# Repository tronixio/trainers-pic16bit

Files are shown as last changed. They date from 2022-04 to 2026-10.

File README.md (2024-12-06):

# PIC 16-Bit Trainers Boards.

## Schematics.

- [**Nano** Trainer.](https://github.com/tronixio/trainers-pic16bit/blob/main/Kicad/nano/extras/schematic.pdf)
- [TODO - Micro Trainer.](https://github.com/tronixio/trainers-pic8bit/blob/main/Kicad/micro/extras/schematic.pdf)
- [**Mini** Trainer.](https://github.com/tronixio/trainers-pic16bit/blob/main/Kicad/mini/extras/schematic.pdf)
- [**PIC 16-Bit** Trainer.](https://github.com/tronixio/trainers-pic16bit/blob/main/Kicad/trainer/extras/schematic.pdf)

## Firmwares.

- [TODO]()

## Hats & Modules.

- [Trainer Hats](https://github.com/tronixio/modules)
- [Trainer Modules (GPIO/UART/I2C/SPI)](https://github.com/tronixio/modules)

### MINI Trainer.

- [PIC24FJxxGA002 - XC16 - LCD - ADC - SWITCHS - ROTARY ENCODER.](https://github.com/tronixio/trainers-pic16bit/blob/main/Firmwares/pic24fjxxga/pic24fjxxga002-mini-xc16-lcd.md)
- [PIC24FJxxGA002 - XC16 - EUSART - ADC - SWITCHS - ROTARY ENCODER.](https://github.com/tronixio/trainers-pic16bit/blob/main/Firmwares/pic24fjxxga/pic24fjxxga002-mini-xc16-eusart.md)
- [PIC24FJxxGA102 - XC16 - LCD - ADC - SWITCHS - ROTARY ENCODER.](https://github.com/tronixio/trainers-pic16bit/blob/main/Firmwares/pic24fjxxga/pic24fjxxga102-mini-xc16-lcd.md)
- [PIC24FJxxGA102 - XC16 - EUSART - ADC - SWITCHS - ROTARY ENCODER.](https://github.com/tronixio/trainers-pic16bit/blob/main/Firmwares/pic24fjxxga/pic24fjxxga102-mini-xc16-eusart.md)

## NANO Trainer Top.

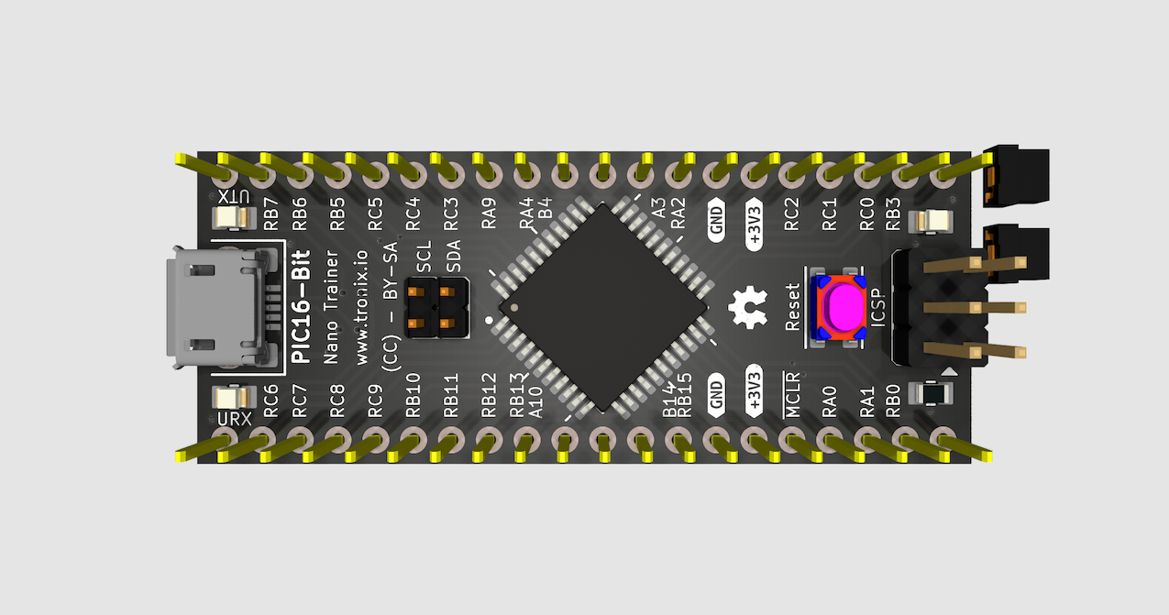
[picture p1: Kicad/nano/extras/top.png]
NANO Trainer Top.


## NANO Trainer Bottom.

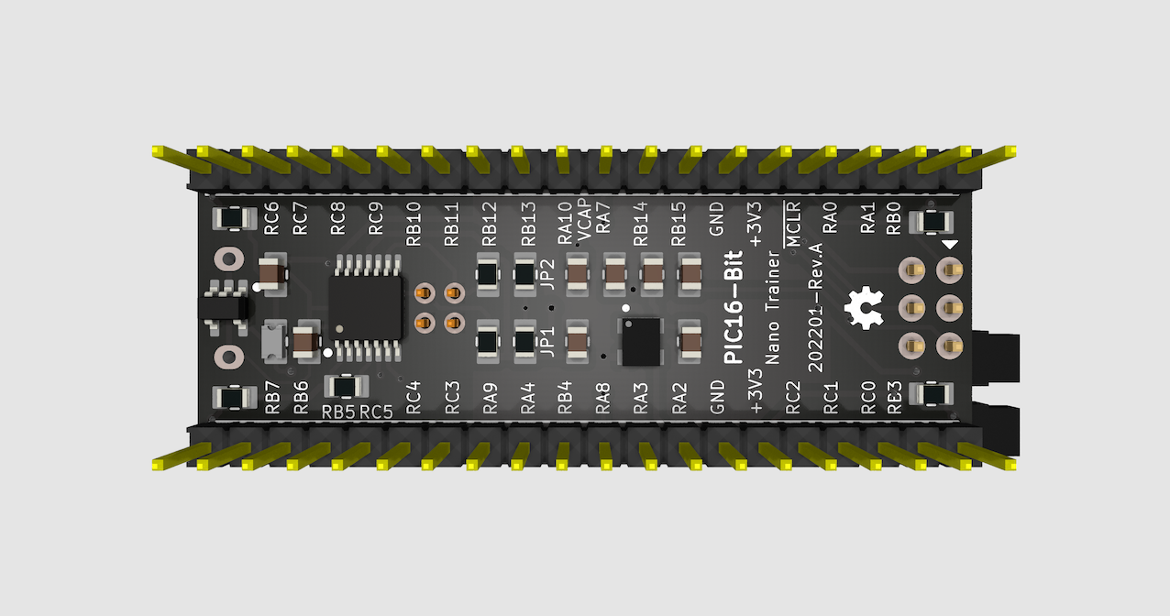
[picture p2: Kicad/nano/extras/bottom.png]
NANO Trainer Bottom.


## MINI Trainer Top.

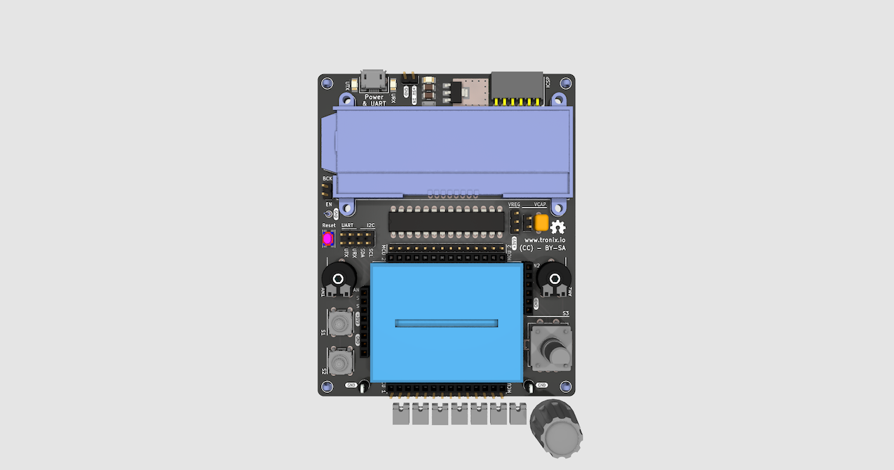
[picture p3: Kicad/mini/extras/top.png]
MINI Trainer Top.


## MINI Trainer Bottom.

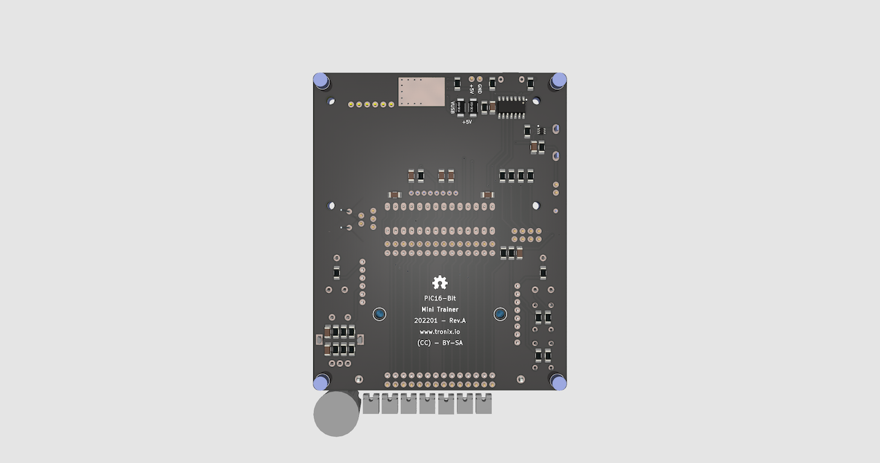
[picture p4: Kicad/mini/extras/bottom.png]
MINI Trainer Bottom.


## PIC 16-Bit Trainer Top.

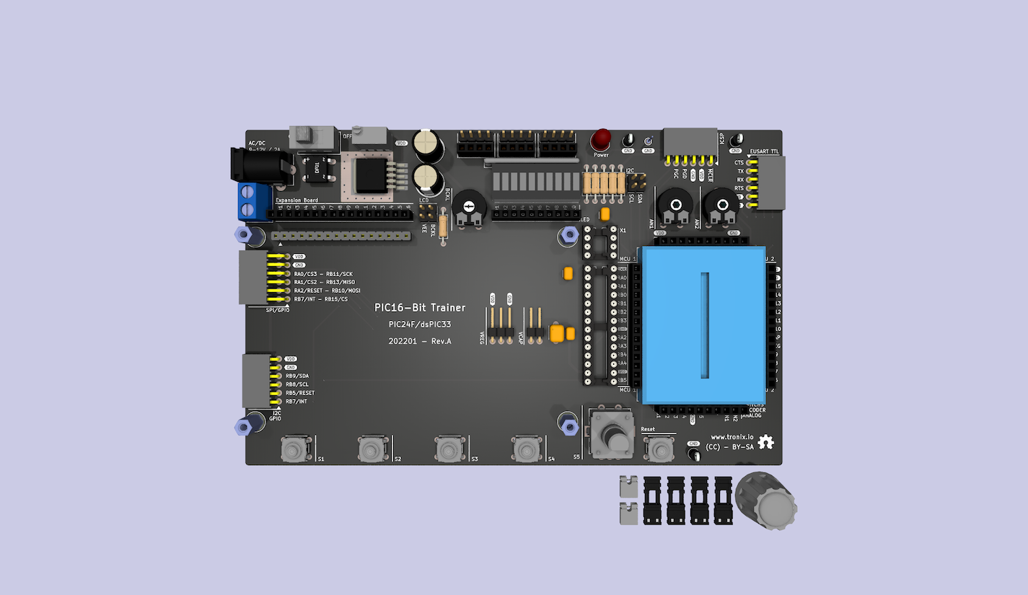
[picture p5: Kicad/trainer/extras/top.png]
PIC 16-Bit Trainer Top.


## PIC 16-Bit Trainer Bottom.

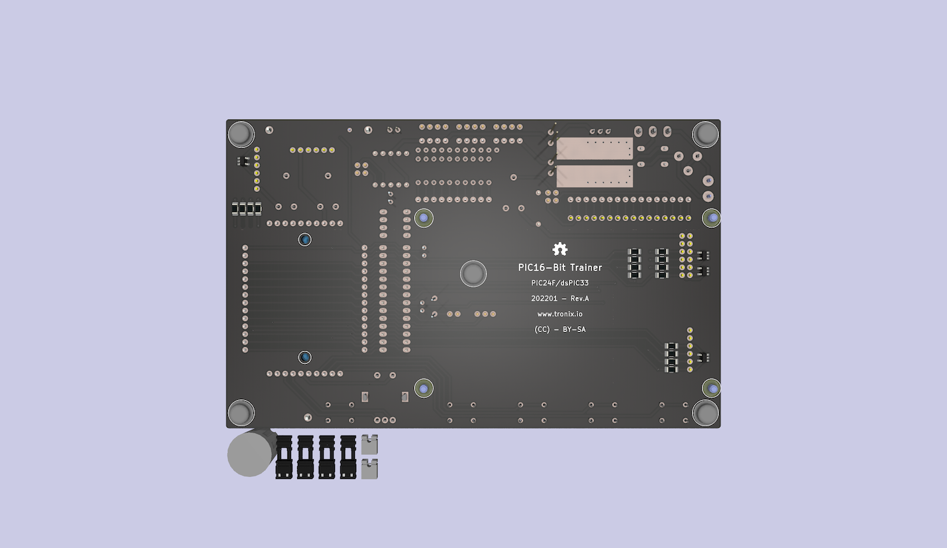
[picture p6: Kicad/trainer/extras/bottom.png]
PIC 16-Bit Trainer Bottom.


## Note.

- DRAFT : Prototype OK, last check schematic, PCB & code can be modify.
- TODO : Work in progress, prototype was not good, hardware, PCB and code can be rework.

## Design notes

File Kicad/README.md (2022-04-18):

# Trainers Boards PIC 16-Bit.

- [Trainers Boards PIC 16-Bit.](https://github.com/tronixio/trainers-pic16bit#schematics)

## Notes.

- TODO : Work in progress, prototype was not good, hardware, PCB and code can be rework.
- DRAFT : Prototype OK, last check schematic, PCB & code can be modify.

## DISCLAIMER.

THIS CODE IS PROVIDED WITHOUT ANY WARRANTY OR GUARANTEES.
USERS MAY USE THIS CODE FOR DEVELOPMENT AND EXAMPLE PURPOSES ONLY.
AUTHORS ARE NOT RESPONSIBLE FOR ANY ERRORS, OMISSIONS, OR DAMAGES THAT COULD
RESULT FROM USING THIS FIRMWARE IN WHOLE OR IN PART.

---

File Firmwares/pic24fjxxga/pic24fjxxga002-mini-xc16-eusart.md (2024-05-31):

# PIC16-Bit Mini Trainer.

## XC16 - EUSART - ADC - SWITCHS - ROTARY ENCODER.

```c
// Configuration Registers.
#pragma config WDTPS = PS32768, FWPSA = PR128, WINDIS = OFF, FWDTEN = OFF
#pragma config ICS = PGx1, GWRP = OFF, GCP = OFF, JTAGEN = OFF
#pragma config POSCMOD = NONE, I2C1SEL = PRI, IOL1WAY = ON
#pragma config OSCIOFNC = OFF, FCKSM = CSDCMD, FNOSC = FRC
#pragma config SOSCSEL = SOSC, WUTSEL = LEG, IESO = OFF

#define FOSC (8000000UL)
#define FCY (FOSC/2)
#define _ISR_FAST __attribute__ ((interrupt, shadow))
#define _ISR_NOPSV __attribute__ ((interrupt, no_auto_psv))
#define _ISR_PSV __attribute__ ((interrupt, auto_psv))

#include <xc.h>
#include <libpic30.h>
// PIC24FJxxGA002 - Compile with XC16(v2.00).
// PIC24FJxxGA002 - @8MHz Internal Oscillator.

// Rotary encoder code from:
// https://www.mikrocontroller.net/articles/Drehgeber

// PIC16-Bit Mini Trainer.
// 2x ADC CHANNELS.
// 1x LCD NHD-C0220BiZ - ST7036.
// 1x EUSART ASYNCHRONOUS TX/RX.
// 1x ROTARY ENCODER with SWITCH.
// 2x SWITCHS.

// JUMPER.URX - Close.
// JUMPER.UTX - Close.
// JUMPER.SDA - Not Use.
// JUMPER.SCL - Not Use.
// JUMPER.VREG - GND.
// JUMPER.VCAP - Close.
// JUMPER.BCKL - Not Use.

// Pinout.
// MCU.RA0 <- ANALOG.AN1.
// MCU.RA1 <- ANALOG.AN2.
// MCU.RB2 <- SWITCH.S1.
// MCU.RB3 <- SWITCH.S2.
// MCU.RA2 <- ROTARY.A.
// MCU.RA3 -> OSCILLOSCOPE.PROBE.A.
// MCU.RA4 <- ROTARY.B.
// MCU.RB4 <- ROTARY.S.

// Definitions.
// EUSART.
#define BAUDRATE             9600
#define BAUDRATE_GENERATOR   (((FCY/BAUDRATE)/16)-1)
// ASCII Characters.
#define ASCII_CR              0x0D
// Rotary Encoder.
#define ROTARY_PHASE_A        PORTAbits.RA2
#define ROTARY_PHASE_B        PORTAbits.RA4
#define ROTARY_SWITCH         PORTBbits.RB4
// Switchs.
#define SWITCH_S1             PORTBbits.RB2
#define SWITCH_S2             PORTBbits.RB3

// Function Prototypes.
uint8_t eusart_readCharacter(void);
void eusart_writeCharacter(uint8_t u8Data);
void eusart_writeString(const uint8_t * u8Data);
int8_t rotary_i8encoderFilter(void);
void u16toa(uint16_t u16Data, uint8_t * au8Buffer, uint8_t u8Base);

// Strings & Custom Patterns.
const uint8_t au8Tronix[] = "\r\n\r\nTronix I/O";
const uint8_t au8WWW[] = "\r\nhttps://www.tronix.io/\r\n";
const uint8_t au8Ready[] = "\r\nREADY> ";
const uint8_t au8Adc0[] = "\r\nADC CHANNEL 0> ";
const uint8_t au8Adc1[] = "\r\nADC CHANNEL 1> ";
const uint8_t au8Encoder[] = "\r\nROTARY ENCODER> ";
const uint8_t au8Encodersw[] = "\r\nROTARY ENCODER SWITCH> ";
const uint8_t au8Switch1[] = "\r\nSWITCH 1> ";
const uint8_t au8Switch2[] = "\r\nSWITCH 2> ";
const uint8_t au8Pressed[] = "PRESSED";
const uint8_t au8Released[] = "RELEASED";

const uint8_t au8encoder[16] = {0, 1, 255, 0, 255, 0, 0, 1, 1, 0, 0, 255, 0, 255, 1, 0};

// Global Variables.
uint8_t u8encoderDelta;
uint16_t u16adcTimer;

// Interrupts Service Routines
void _ISR_NOPSV _T1Interrupt(void)
{
    if(IFS0bits.T1IF){
        static int8_t u8encoderLast = 0;
        u8encoderLast = (u8encoderLast<<2) & 0x0F;
        if(ROTARY_PHASE_A) u8encoderLast |= 0b01; // CW.
        if(ROTARY_PHASE_B) u8encoderLast |= 0b10; // CCW.
        u8encoderDelta += au8encoder[u8encoderLast];
        IFS0bits.T1IF = 0b0;
    }
    u16adcTimer++;
}

// Main.
int main(void)
{
    // MCU Initialization.
    // Internal Oscillator Settings.
    CLKDIVbits.RCDIV = 0b000;
    // Ports Initialization.
    // Analog Inputs Settings.
    AD1PCFG = 0b1001111000111100;
    // Port A Settings.
    TRISA = 0b0000000000010111;
    PORTA = 0b0000000000000000;
    LATA = 0b0000000000000000;
    ODCA = 0b0000000000000000;
    // Port B Settings.
    TRISB = 0b0000000000011110;
    PORTB = 0b0000000000000000;
    LATB = 0b0000000000000000;
    ODCB = 0b0000000000000000;
    // PPS Settings.
    __builtin_write_OSCCONL(OSCCON & 0xBF);
    // PPS Inputs.
    RPINR18bits.U1RXR = 0b00001;    // RB1 - RP1 - EUSART.U1RX.
    // PPS Outputs.
    RPOR0bits.RP0R = 0b00011;       // RB0 - RP0 - EUSART.U1TX.
    __builtin_write_OSCCONL(OSCCON | 0x40);

    // Interrupts Settings.
    INTCON1 = 0x8000;
    INTCON2 = 0x0000;

    // ADC Settings.
    AD1CON1 = 0x0000;
    AD1CON1bits.ADSIDL = 0b1;
    AD1CON1bits.FORM = 0b00;
    AD1CON1bits.SSRC = 0b111;
    AD1CON1bits.ASAM = 0b1;
    AD1CON1bits.SAMP = 0b0;
    AD1CON2 = 0x0000;
    AD1CON2bits.VCFG = 0b000;
    AD1CON2bits.CSCNA = 0b1;
    AD1CON2bits.BUFS = 0b0;
    AD1CON2bits.SMPI = 0b0001;
    AD1CON2bits.BUFM = 0b0;
    AD1CON2bits.ALTS = 0b0;
    AD1CON3 = 0x0000;
    AD1CON3bits.ADRC = 0b0;
    AD1CON3bits.SAMC = 0b11111;
    AD1CON3bits.ADCS = 0b00111111;
    AD1CHS = 0x0000;
    AD1CHSbits.CH0NB = 0b0;
    AD1CHSbits.CH0SB = 0b00000;
    AD1CHSbits.CH0NA = 0b0;
    AD1CHSbits.CH0SA = 0b00000;
    AD1CSSL = 0b0000000000000011;
    // ADC Enable.
    AD1CON1bits.ADON = 0b1;

    // EUSART Settings.
    U1BRG = BAUDRATE_GENERATOR;
    U1MODE = 0x0000;
    U1MODEbits.UEN = 0b00;
    U1MODEbits.BRGH = 0b0;
    U1MODEbits.PDSEL = 0b00;
    U1MODEbits.STSEL = 0b0;
    U1STA = 0x0000;
    U1TXREG = 0x0000;
    U1RXREG = 0x0000;
    // UART Enable.
    U1MODEbits.UARTEN = 0b1;
    U1STAbits.UTXEN = 0b1;

    // Timer1 Settings.
    // ~500Hz @8MHz.
    PR1 = 3980;
    T1CON = 0x0000;
    // Timer1 Enable.
    T1CONbits.TON = 0b1;
    // Timer1 Interrupts Enable.
    IFS0bits.T1IF = 0b0;
    IEC0bits.T1IE = 0b1;
    IPC0bits.IC1IP = 0b000;

    // Display String.
    eusart_writeString(au8Tronix);
    eusart_writeString(au8WWW);
    eusart_writeString(au8Ready);

    uint8_t u8Rx;
    uint8_t au8Buffer[6];
    uint16_t u16ADCRead, u16ADC0Last, u16ADC1Last;
    uint8_t u8encoderSwitchPressed;
    uint16_t u8encoderRead, u8encoderLast;
    uint8_t u8switchS1Pressed, u8switchS2Pressed;
    while(1){
        // ADC Read every ~1s.
        if(u16adcTimer>1000){
            u16ADCRead = 0;
            AD1CHSbits.CH0SA = 0b00000;
            __delay_us(5);
            AD1CON1bits.DONE = 0b1;
            while(!AD1CON1bits.DONE){};
                u16ADCRead = ADC1BUF0;
                if(u16ADC0Last != u16ADCRead){
                    u16toa(u16ADCRead, au8Buffer, 10);
                    eusart_writeString(au8Adc0);
                    eusart_writeString(au8Buffer);
                    u16ADC0Last = u16ADCRead;
                }
            u16ADCRead = 0;
            AD1CHSbits.CH0SA = 0b00001;
            __delay_us(5);
            AD1CON1bits.DONE = 0b1;
            while(!AD1CON1bits.DONE){};
                u16ADCRead = ADC1BUF1;
                if(u16ADC1Last != u16ADCRead){
                    u16toa(u16ADCRead, au8Buffer, 10);
                    eusart_writeString(au8Adc1);
                    eusart_writeString(au8Buffer);
                    u16ADC1Last = u16ADCRead;
                }
            u16adcTimer = 0;
        }

        // EUSART.
        if(IFS0bits.U1RXIF){
            u8Rx = eusart_readCharacter();
            eusart_writeCharacter(u8Rx);
            if(u8Rx == ASCII_CR)
                eusart_writeString(au8Ready);
            IFS0bits.U1RXIF = 0b0;
        }

        // ROTARY ENCODER.
        if(!ROTARY_SWITCH){
            __delay_ms(100);
            u8encoderSwitchPressed = 0b1;
            eusart_writeString(au8Encodersw);
            eusart_writeString(au8Pressed);
        }else if(ROTARY_SWITCH){
            if(u8encoderSwitchPressed){
                u8encoderSwitchPressed = 0b0;
                eusart_writeString(au8Encodersw);
                eusart_writeString(au8Released);
                u8encoderRead = 0;
            }
        }

        u8encoderRead += rotary_i8encoderFilter();
        if(u8encoderLast != u8encoderRead){
            u16toa(u8encoderRead, au8Buffer, 10);
            eusart_writeString(au8Encoder);
            eusart_writeString(au8Buffer);
            u8encoderLast = u8encoderRead;
        }

        // SWITCHS.
        if(!SWITCH_S1){
            __delay_ms(100);
            u8switchS1Pressed = 0b1;
            eusart_writeString(au8Switch1);
            eusart_writeString(au8Pressed);
        }else if(SWITCH_S1){
            if(u8switchS1Pressed){
                eusart_writeString(au8Switch1);
                eusart_writeString(au8Released);
                u8switchS1Pressed = 0b0;
            }
        }
        if(!SWITCH_S2){
            __delay_ms(100);
            u8switchS2Pressed = 0b1;
            eusart_writeString(au8Switch2);
            eusart_writeString(au8Pressed);
        }else if(SWITCH_S2){
            if(u8switchS2Pressed){
                eusart_writeString(au8Switch2);
            eusart_writeString(au8Released);
            u8switchS2Pressed = 0b0;
            }
        }
    }
    return(0);
}

// Functions.
uint8_t eusart_readCharacter(void)
{
    while(!U1STAbits.URXDA){};
    return(U1RXREG);
}

void eusart_writeCharacter(uint8_t u8Data)
{
    while(U1STAbits.UTXBF){};
    U1TXREG = u8Data;
}

void eusart_writeString(const uint8_t * u8Data)
{
    while(*u8Data != '\0')
        eusart_writeCharacter(*u8Data++);
}

int8_t rotary_i8encoderFilter(void)
{
    int8_t i8encoderFilter;

    IEC0bits.T1IE = 0b0;
    i8encoderFilter = u8encoderDelta;
    u8encoderDelta = i8encoderFilter & 3;
    IEC0bits.T1IE = 0b1;

    return(i8encoderFilter>>2);
}

void u16toa(uint16_t u16Data, uint8_t * au8Buffer, uint8_t u8Base)
{
    uint8_t u8Buffer;
    uint16_t data = u16Data;

    do{
        data /= u8Base;
        au8Buffer++;
    }while(data != '\0');
    *au8Buffer-- = 0;

    do{
        u8Buffer = (uint16_t)(u16Data % u8Base);
        u16Data /= u8Base;
        if(u8Buffer >= 10)
            u8Buffer += 'A' - '0' - 10;
        u8Buffer += '0';
        *au8Buffer-- = u8Buffer;
    }while(u16Data != '\0');
}
```

---
DISCLAIMER: THIS CODE IS PROVIDED WITHOUT ANY WARRANTY OR GUARANTEES.
USERS MAY USE THIS CODE FOR DEVELOPMENT AND EXAMPLE PURPOSES ONLY.
AUTHORS ARE NOT RESPONSIBLE FOR ANY ERRORS, OMISSIONS, OR DAMAGES THAT COULD
RESULT FROM USING THIS FIRMWARE IN WHOLE OR IN PART.

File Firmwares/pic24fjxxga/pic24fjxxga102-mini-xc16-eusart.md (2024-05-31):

# PIC16-Bit Mini Trainer.

## XC16 - EUSART - ADC - SWITCHS - ROTARY ENCODER.

```c
// Configuration Registers.
#pragma config WDTPS = PS32768, FWPSA = PR128, WINDIS = OFF
#pragma config FWDTEN = OFF, ICS = PGx1, GWRP = OFF, GCP = OFF, JTAGEN = OFF
#pragma config POSCMOD = NONE, I2C1SEL = PRI, IOL1WAY = ON
#pragma config OSCIOFNC = OFF, FCKSM = CSDCMD, FNOSC = FRC, IESO = OFF
#pragma config WPFP = WPFP63, SOSCSEL = IO, WUTSEL = LEG
#pragma config WPDIS = WPDIS, WPCFG = WPCFGDIS, WPEND = WPENDMEM
#pragma config DSWDTPS = DSWDTPSF, DSWDTOSC = LPRC
#pragma config RTCOSC = SOSC, DSBOREN = OFF, DSWDTEN = OFF

#define FOSC (8000000UL)
#define FCY (FOSC/2)
#define _ISR_FAST __attribute__ ((interrupt, shadow))
#define _ISR_NOPSV __attribute__ ((interrupt, no_auto_psv))
#define _ISR_PSV __attribute__ ((interrupt, auto_psv))

#include <xc.h>
#include <libpic30.h>
// PIC24FJxxGA102 - Compile with XC16(v2.00).
// PIC24FJxxGA102 - @8MHz Internal Oscillator.

// Rotary encoder code from:
// https://www.mikrocontroller.net/articles/Drehgeber

// PIC16-Bit Mini Trainer.
// 2x ADC CHANNELS.
// 1x LCD NHD-C0220BiZ - ST7036.
// 1x EUSART ASYNCHRONOUS TX/RX.
// 1x ROTARY ENCODER with SWITCH.
// 2x SWITCHS.

// JUMPER.URX - Close.
// JUMPER.UTX - Close.
// JUMPER.SDA - Not Use.
// JUMPER.SCL - Not Use.
// JUMPER.VREG - GND.
// JUMPER.VCAP - Close.
// JUMPER.BCKL - Not Use.

// Pinout.
// MCU.RA0 <- ANALOG.AN1.
// MCU.RA1 <- ANALOG.AN2.
// MCU.RB2 <- SWITCH.S1.
// MCU.RB3 <- SWITCH.S2.
// MCU.RA2 <- ROTARY.A.
// MCU.RA3 -> OSCILLOSCOPE.PROBE.A.
// MCU.RA4 <- ROTARY.B.
// MCU.RB4 <- ROTARY.S.

// Definitions.
// EUSART.
#define BAUDRATE             9600
#define BAUDRATE_GENERATOR   (((FCY/BAUDRATE)/16)-1)
// ASCII Characters.
#define ASCII_CR             0x0D
// Rotary Encoder.
#define ROTARY_PHASE_A       PORTAbits.RA2
#define ROTARY_PHASE_B       PORTAbits.RA4
#define ROTARY_SWITCH        PORTBbits.RB4
// Switchs.
#define SWITCH_S1            PORTBbits.RB2
#define SWITCH_S2            PORTBbits.RB3

// Function Prototypes.
uint8_t eusart_readCharacter(void);
void eusart_writeCharacter(uint8_t u8Data);
void eusart_writeString(const uint8_t * u8Data);
int8_t rotary_i8encoderRead(void);
void u16toa(uint16_t u16Data, uint8_t * au8Buffer, uint8_t u8Base);

// Strings & Custom Patterns.
const uint8_t au8Tronix[] = "\r\n\r\nTronix I/O";
const uint8_t au8WWW[] = "\r\nhttps://www.tronix.io/\r\n";
const uint8_t au8Ready[] = "\r\nREADY> ";
const uint8_t au8Adc0[] = "\r\nADC CHANNEL 0> ";
const uint8_t au8Adc1[] = "\r\nADC CHANNEL 1> ";
const uint8_t au8Encoder[] = "\r\nROTARY ENCODER> ";
const uint8_t au8Encodersw[] = "\r\nROTARY ENCODER SWITCH> ";
const uint8_t au8Switch1[] = "\r\nSWITCH 1> ";
const uint8_t au8Switch2[] = "\r\nSWITCH 2> ";
const uint8_t au8Pressed[] = "PRESSED";
const uint8_t au8Released[] = "RELEASED";

const int8_t ai8encoderFull[16] = {0, 1, -1, 0, -1, 0, 0, 1, 1, 0, 0, -1, 0, -1, 1, 0};

// Global Variables.
int8_t i8encoderDelta;
uint16_t u16adcTimer;

// Interrupts Service Routines
void _ISR_NOPSV _T1Interrupt(void)
{
    if(IFS0bits.T1IF){
        static int8_t u8encoderLast = 0;
        u8encoderLast = (u8encoderLast<<2) & 0x0F;
        if(ROTARY_PHASE_A) u8encoderLast |= 0b01; // CW.
        if(ROTARY_PHASE_B) u8encoderLast |= 0b10; // CCW.
        i8encoderDelta += ai8encoderFull[u8encoderLast];
        IFS0bits.T1IF = 0b0;
    }
    u16adcTimer++;
}

// Main.
int main(void)
{
    // MCU Initialization.
    // Internal Oscillator Settings.
    CLKDIVbits.RCDIV = 0b000;
    // Ports Initialization.
    // Analog Inputs Settings.
    AD1PCFG = 0b1001111000111100;
    // Port A Settings.
    TRISA = 0b0000000000010111;
    PORTA = 0b0000000000000000;
    LATA = 0b0000000000000000;
    ODCA = 0b0000000000000000;
    // Port B Settings.
    TRISB = 0b0000000000011110;
    PORTB = 0b0000000000000000;
    LATB = 0b0000000000000000;
    ODCB = 0b0000000000000000;
    // PPS Settings.
    __builtin_write_OSCCONL(OSCCON & 0xBF);
    // PPS Inputs.
    RPINR18bits.U1RXR = 0b00001;    // RB1 - RP1 - EUSART.U1RX.
    // PPS Outputs.
    RPOR0bits.RP0R = 0b00011;       // RB0 - RP0 - EUSART.U1TX.
    __builtin_write_OSCCONL(OSCCON | 0x40);

    // Interrupts Settings.
    INTCON1 = 0x8000;
    INTCON2 = 0x0000;

    // ADC Settings.
    AD1CON1 = 0x0000;
    AD1CON1bits.ADSIDL = 0b1;
    AD1CON1bits.FORM = 0b00;
    AD1CON1bits.SSRC = 0b111;
    AD1CON1bits.ASAM = 0b1;
    AD1CON1bits.SAMP = 0b0;
    AD1CON2 = 0x0000;
    AD1CON2bits.VCFG = 0b000;
    AD1CON2bits.CSCNA = 0b1;
    AD1CON2bits.BUFS = 0b0;
    AD1CON2bits.SMPI = 0b0001;
    AD1CON2bits.BUFM = 0b0;
    AD1CON2bits.ALTS = 0b0;
    AD1CON3 = 0x0000;
    AD1CON3bits.ADRC = 0b0;
    AD1CON3bits.SAMC = 0b11111;
    AD1CON3bits.ADCS = 0b00111111;
    AD1CHS = 0x0000;
    AD1CHSbits.CH0NB = 0b0;
    AD1CHSbits.CH0SB = 0b00000;
    AD1CHSbits.CH0NA = 0b0;
    AD1CHSbits.CH0SA = 0b00000;
    AD1CSSL = 0b0000000000000011;
    // ADC Enable.
    AD1CON1bits.ADON = 0b1;

    // EUSART Settings.
    U1BRG = BAUDRATE_GENERATOR;
    U1MODE = 0x0000;
    U1MODEbits.UEN = 0b00;
    U1MODEbits.BRGH = 0b0;
    U1MODEbits.PDSEL = 0b00;
    U1MODEbits.STSEL = 0b0;
    U1STA = 0x0000;
    U1TXREG = 0x0000;
    U1RXREG = 0x0000;
    // UART Enable.
    U1MODEbits.UARTEN = 0b1;
    U1STAbits.UTXEN = 0b1;

    // Timer1 Settings.
    // ~500Hz @8MHz.
    PR1 = 3980;
    T1CON = 0x0000;
    // Timer1 Enable.
    T1CONbits.TON = 0b1;
    // Timer1 Interrupts Enable.
    IFS0bits.T1IF = 0b0;
    IEC0bits.T1IE = 0b1;
    IPC0bits.IC1IP = 0b000;

    // Display String.
    eusart_writeString(au8Tronix);
    eusart_writeString(au8WWW);
    eusart_writeString(au8Ready);

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

        // EUSART.
        if(IFS0bits.U1RXIF){
            u8Rx = eusart_readCharacter();
            eusart_writeCharacter(u8Rx);
            if(u8Rx == ASCII_CR)
                eusart_writeString(au8Ready);
            IFS0bits.U1RXIF = 0b0;
        }

        // ROTARY ENCODER.
        if(!ROTARY_SWITCH){
            __delay_ms(100);
            u8encoderSwitchPressed = 0b1;
            eusart_writeString(au8Encodersw);
            eusart_writeString(au8Pressed);
        }else if(ROTARY_SWITCH){
            if(u8encoderSwitchPressed){
                u8encoderSwitchPressed = 0b0;
                eusart_writeString(au8Encodersw);
                eusart_writeString(au8Released);
                u8encoderRead = 0;
            }
        }

        u8encoderRead += rotary_i8encoderRead();
        if(u8encoderLast != u8encoderRead){
            u16toa(u8encoderRead, au8Buffer, 10);
            eusart_writeString(au8Encoder);
            eusart_writeString(au8Buffer);
            u8encoderLast = u8encoderRead;
        }

        // SWITCHS.
        if(!SWITCH_S1){
            __delay_ms(100);
            u8switchS1Pressed = 0b1;
            eusart_writeString(au8Switch1);
            eusart_writeString(au8Pressed);
        }else if(SWITCH_S1){
            if(u8switchS1Pressed){
                eusart_writeString(au8Switch1);
                eusart_writeString(au8Released);
                u8switchS1Pressed = 0b0;
            }
        }
        if(!SWITCH_S2){
            __delay_ms(100);
            u8switchS2Pressed = 0b1;
            eusart_writeString(au8Switch2);
            eusart_writeString(au8Pressed);
        }else if(SWITCH_S2){
            if(u8switchS2Pressed){
                eusart_writeString(au8Switch2);
            eusart_writeString(au8Released);
            u8switchS2Pressed = 0b0;
            }
        }
    }
    return(0);
}

// Functions.
uint8_t eusart_readCharacter(void)
{
    while(!U1STAbits.URXDA){};
    return(U1RXREG);
}

void eusart_writeCharacter(uint8_t u8Data)
{
    while(U1STAbits.UTXBF){};
    U1TXREG = u8Data;
}

void eusart_writeString(const uint8_t * u8Data)
{
    while(*u8Data != '\0')
        eusart_writeCharacter(*u8Data++);
}

int8_t rotary_i8encoderRead(void)
{
    int8_t u8encoderRead;

    IEC0bits.T1IE = 0b0;
    u8encoderRead = i8encoderDelta;
    i8encoderDelta = u8encoderRead & 3;
    IEC0bits.T1IE = 0b1;

    return(u8encoderRead>>2);
}

void u16toa(uint16_t u16Data, uint8_t * au8Buffer, uint8_t u8Base)
{
    uint8_t u8Buffer;
    uint16_t data = u16Data;

    do{
        data /= u8Base;
        au8Buffer++;
    }while(data != '\0');
    *au8Buffer-- = 0;

    do{
        u8Buffer = (uint16_t)(u16Data % u8Base);
        u16Data /= u8Base;
        if(u8Buffer >= 10)
            u8Buffer += 'A' - '0' - 10;
        u8Buffer += '0';
        *au8Buffer-- = u8Buffer;
    }while(u16Data != '\0');
}
```

---
DISCLAIMER: THIS CODE IS PROVIDED WITHOUT ANY WARRANTY OR GUARANTEES.
USERS MAY USE THIS CODE FOR DEVELOPMENT AND EXAMPLE PURPOSES ONLY.
AUTHORS ARE NOT RESPONSIBLE FOR ANY ERRORS, OMISSIONS, OR DAMAGES THAT COULD
RESULT FROM USING THIS FIRMWARE IN WHOLE OR IN PART.

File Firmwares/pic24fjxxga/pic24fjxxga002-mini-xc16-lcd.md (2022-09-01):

# PIC16-Bit Mini Trainer.

## XC16 - LCD - ADC - SWITCHS - ROTARY ENCODER.

```c
// Configuration Registers.
#pragma config WDTPS = PS32768, FWPSA = PR128, WINDIS = OFF, FWDTEN = OFF
#pragma config ICS = PGx1, GWRP = OFF, GCP = OFF, JTAGEN = OFF
#pragma config POSCMOD = NONE, I2C1SEL = PRI, IOL1WAY = ON
#pragma config OSCIOFNC = OFF, FCKSM = CSDCMD, FNOSC = FRC
#pragma config SOSCSEL = SOSC, WUTSEL = LEG, IESO = OFF

#define FOSC    (8000000UL)
#define FCY     (FOSC/2)
#define _ISR_FAST __attribute__ ((interrupt, shadow))
#define _ISR_NOPSV __attribute__ ((interrupt, no_auto_psv))
#define _ISR_PSV __attribute__ ((interrupt, auto_psv))

#include <xc.h>
#include <libpic30.h>
// PIC24FJxxGA002 - Compile with XC16(v2.00).
// PIC24FJxxGA002 - @8MHz Internal Oscillator.

// Rotary encoder code from:
// https://www.mikrocontroller.net/articles/Drehgeber

// PIC16-Bit Mini Trainer.
// 2x ADC CHANNELS.
// 1x LCD NHD-C0220BiZ - ST7036.
// 1x EUSART ASYNCHRONOUS TX/RX.
// 1x ROTARY ENCODER with SWITCH.
// 2x SWITCHS.

// JUMPER.URX - Not Use.
// JUMPER.UTX - Not Use.
// JUMPER.SDA - Close.
// JUMPER.SCL - Close.
// JUMPER.VREG - GND.
// JUMPER.VCAP - Close.
// JUMPER.BCKL - Open.

// Pinout.
// MCU.RA0 <- ANALOG.AN1.
// MCU.RA1 <- ANALOG.AN2.
// MCU.RB2 <- SWITCH.S1.
// MCU.RB3 <- SWITCH.S2.
// MCU.RA2 <- ROTARY.A.
// MCU.RA3 -> OSCILLOSCOPE.PROBE.A.
// MCU.RA4 <- ROTARY.B.
// MCU.RB4 <- ROTARY.S.
// MCU.RB6 -> LCD.BACKLIGHT.EN.

// Definitions.
// I2C.
#define I2C_READ                                            0b1
#define I2C_WRITE                                           0b0
#define I2C_FSCL_HZ                                         400000
#define I2C_BRG                                             (((FCY/I2C_FSCL_HZ)-(FCY/10000000))-1)
// CAT4002A.
#define CAT4002_DELAY_DIM_MS                                5
#define CAT4002_DELAY_LED_US                                10
// ST7036 I2C Address.
#define ST7036_I2C_ADDRESS_78                               0x78
#define ST7036_I2C_CONTROL_CONTINUOUS_COMMAND               0x00
#define ST7036_I2C_CONTROL_CONTINUOUS_DATA                  0x40
#define ST7036_I2C_CONTROL_NO_CONTINUOUS_COMMAND            0x80
#define ST7036_I2C_CONTROL_NO_CONTINUOUS_DATA               0xC0
// ST7036 Instruction Table IS2=0, IS1=0.
#define ST7036_CLEAR_DISPLAY                                0x01
#define ST7036_RETURN_HOME                                  0x02
#define ST7036_ENTRY_MODE_SET_DDRAM_DECREMENT_NOSHIFT       0x04
#define ST7036_ENTRY_MODE_SET_DDRAM_DECREMENT_SHIFT_RIGHT   0x05
#define ST7036_ENTRY_MODE_SET_DDRAM_INCREMENT_NOSHIFT       0x06
#define ST7036_ENTRY_MODE_SET_DDRAM_INCREMENT_SHIFT_LEFT    0x07
#define ST7036_DISPLAY_OFF                                  0x08
#define ST7036_DISPLAY_ON_CURSOR_OFF                        0x0C
#define ST7036_DISPLAY_ON_CURSOR_ON_NOBLINK                 0x0E
#define ST7036_DISPLAY_ON_CURSOR_ON_BLINK                   0x0F
#define ST7036_DISPLAY_CURSOR_SHIFT_LEFT                    0x10
#define ST7036_DISPLAY_CURSOR_SHIFT_RIGHT                   0x14
#define ST7036_DISPLAY_DISPLAY_SHIFT_LEFT                   0x18
#define ST7036_DISPLAY_DISPLAY_SHIFT_RIGH                   0x1C
#define ST7036_FUNCTION_SET_4_BIT_ONE_LINE_FONT5x8          0x20
#define ST7036_FUNCTION_SET_4_BIT_ONE_LINE_FONT5x8_IS1      0x21
#define ST7036_FUNCTION_SET_4_BIT_ONE_LINE_FONT5x8_IS2      0x22
#define ST7036_FUNCTION_SET_4_BIT_TWO_LINE_FONT5x8          0x28
#define ST7036_FUNCTION_SET_4_BIT_ONE_LINE_DHFONT5x8        0x24
#define ST7036_FUNCTION_SET_4_BIT_TWO_LINE_DHFONT5x8        0x2C
#define ST7036_FUNCTION_SET_8_BIT_ONE_LINE_FONT5x8          0x30
#define ST7036_FUNCTION_SET_8_BIT_ONE_LINE_FONT5x8_IS1      0x31
#define ST7036_FUNCTION_SET_8_BIT_ONE_LINE_FONT5x8_IS2      0x32
#define ST7036_FUNCTION_SET_8_BIT_ONE_LINE_DHFONT5x8        0x34
#define ST7036_FUNCTION_SET_8_BIT_TWO_LINE_FONT5x8          0x38
#define ST7036_FUNCTION_SET_8_BIT_TWO_LINE_DHFONT5x8        0x3C
#define ST7036_SET_ICON_RAM_ADDRESS                         0X40
#define ST7036_SET_CGRAM_ADDRESS                            0x40
#define ST7036_DDRAM_ADDRESS_FIRST_LINE                     0x80
#define ST7036_DDRAM_ADDRESS_SECOND_LINE                    0xC0
// ST7036 Instruction Table IS2=0, IS1=1.
#define ST7036_BIAS_SET_1_5                                 0x14
#define ST7036_BIAS_SET_1_5_3_LINE                          0x15
#define ST7036_BIAS_SET_1_4                                 0x1C
#define ST7036_BIAS_SET_1_4_3_LINE                          0x1D
#define ST7036_POWER_ICON_OFF_BOOST_OFF_NO_CONTRAST         0x50
#define ST7036_POWER_ICON_ON_BOOST_OFF_NO_CONTRAST          0x58
#define ST7036_POWER_ICON_OFF_BOOST_ON_CONTRAST_MSB_0       0x54
#define ST7036_POWER_ICON_OFF_BOOST_ON_CONTRAST_MSB_1       0x55
#define ST7036_POWER_ICON_OFF_BOOST_ON_CONTRAST_MSB_2       0x56
#define ST7036_POWER_ICON_OFF_BOOST_ON_CONTRAST_MSB_3       0x57
#define ST7036_POWER_ICON_ON_BOOST_ON_CONTRAST_MSB_0        0x5C
#define ST7036_POWER_ICON_ON_BOOST_ON_CONTRAST_MSB_1        0x5D
#define ST7036_POWER_ICON_ON_BOOST_ON_CONTRAST_MSB_2        0x5E
#define ST7036_POWER_ICON_ON_BOOST_ON_CONTRAST_MSB_3        0x5F
#define ST7036_FOLLOWER_CONTROL_OFF                         0x60
#define ST7036_FOLLOWER_CONTROL_ON_RAB_0                    0x68
#define ST7036_FOLLOWER_CONTROL_ON_RAB_1                    0x69
#define ST7036_FOLLOWER_CONTROL_ON_RAB_2                    0x6A
#define ST7036_FOLLOWER_CONTROL_ON_RAB_3                    0x6B
#define ST7036_FOLLOWER_CONTROL_ON_RAB_4                    0x6C
#define ST7036_FOLLOWER_CONTROL_ON_RAB_5                    0x6D
#define ST7036_FOLLOWER_CONTROL_ON_RAB_6                    0x6E
#define ST7036_FOLLOWER_CONTROL_ON_RAB_7                    0x6F
#define ST7036_CONTRAST_LSB_0                               0x70
#define ST7036_CONTRAST_LSB_1                               0x71
#define ST7036_CONTRAST_LSB_2                               0x72
#define ST7036_CONTRAST_LSB_3                               0x73
#define ST7036_CONTRAST_LSB_4                               0x74
#define ST7036_CONTRAST_LSB_5                               0x75
#define ST7036_CONTRAST_LSB_6                               0x76
#define ST7036_CONTRAST_LSB_7                               0x77
#define ST7036_CONTRAST_LSB_8                               0x78
#define ST7036_CONTRAST_LSB_9                               0x79
#define ST7036_CONTRAST_LSB_10                              0x7A
#define ST7036_CONTRAST_LSB_11                              0x7B
#define ST7036_CONTRAST_LSB_12                              0x7C
#define ST7036_CONTRAST_LSB_13                              0x7D
#define ST7036_CONTRAST_LSB_14                              0x7E
#define ST7036_CONTRAST_LSB_15                              0x7F
// ST7036 Instruction Table IS2=1, IS1=0.
#define ST7036_DOUBLE_HEIGHT_FONT_COM9_COM24                0x10
#define ST7036_DOUBLE_HEIGHT_FONT_COM1_COM16                0x11
// ST7036 Delays.
#define ST7036_CLEAR_DISPLAY_DELAY_MS                       2
#define ST7036_INITIALIZATION_DELAY_MS                      40
// NHD-C0220BiZ Configuration.
#define C0220BiZ_CONFIGURATION_I2C_ADDRESS                  ST7036_I2C_ADDRESS_78
#define C0220BiZ_CONFIGURATION_FIRST_LINE                   ST7036_DDRAM_ADDRESS_FIRST_LINE
#define C0220BiZ_CONFIGURATION_SECOND_LINE                  ST7036_DDRAM_ADDRESS_SECOND_LINE
#define C0220BiZ_CONFIGURATION_CHARACTERS                   20
// ASCII Characters.
#define ASCII_SPACE                                         0x20
// Patterns.
#define PATTERN_BATTERY_FULL                                0x04
#define PATTERN_BATTERY_3                                   0x03
#define PATTERN_BATTERY_2                                   0x02
#define PATTERN_BATTERY_1                                   0x01
#define PATTERN_BATTERY_EMPTY                               0x00
// LCD.
#define LCD_BACKLIGHT_OFF                                   LATBbits.LATB6 = 0b0
#define LCD_BACKLIGHT_ON                                    LATBbits.LATB6 = 0b1
// Rotary Encoder.
#define ROTARY_PHASE_A                                      PORTAbits.RA2
#define ROTARY_PHASE_B                                      PORTAbits.RA4
#define ROTARY_SWITCH                                       PORTBbits.RB4
// Switchs.
#define SWITCH_S1                                           PORTBbits.RB2
#define SWITCH_S2                                           PORTBbits.RB3

// Function Prototypes.
void i2c_restart(void);
void i2c_start(void);
void i2c_stop(void);
void i2c_write(uint8_t u8Data);
void lcd_clearDisplay(void);
void lcd_clearLine(uint8_t u8Line);
void lcd_initialize(void);
void lcd_setBacklight(uint8_t u8Backlight);
void lcd_setCursor(uint8_t u8Cursor);
void lcd_writeCharacter(uint8_t u8Data);
void lcd_writeInstruction(uint8_t u8Data);
void lcd_writeString(const uint8_t * u8Data);
void lcd_writeStringSetCursor(const uint8_t * u8Data, uint8_t u8Cursor);
int8_t rotary_i8encoderFilter(void);
void u16toa(uint16_t u16Data, uint8_t * au8Buffer, uint8_t u8Base);

// Strings & Custom Patterns.
const uint8_t au8Tronix[] = "Tronix I/O";
const uint8_t au8WWW[] = "www.tronix.io";
const uint8_t au8Adc0[] = "ADC CHANNEL 0> ";
const uint8_t au8Adc1[] = "ADC CHANNEL 1> ";
const uint8_t au8Encoder[] = "ROTARY> ";
const uint8_t au8Backlight[] = "BACKLIGHT> ";
const uint8_t au8Switch1[] = "SWITCH 1> ";
const uint8_t au8Switch2[] = "SWITCH 2> ";
const uint8_t au8Pressed[] = "PRESSED";
const uint8_t au8Released[] = "RELEASED";

const uint8_t au8BatteryPattern[5][8] = {
    {0x0e, 0x1b, 0x11, 0x11, 0x11, 0x11, 0x11, 0x1f},
    {0x0e, 0x1b, 0x11, 0x11, 0x11, 0x1f, 0x1f, 0x1f},
    {0x0e, 0x1b, 0x11, 0x11, 0x1f, 0x1f, 0x1f, 0x1f},
    {0x0e, 0x1b, 0x11, 0x1f, 0x1f, 0x1f, 0x1f, 0x1f},
    {0x0e, 0x1f, 0x1f, 0x1f, 0x1f, 0x1f, 0x1f, 0x1f}
};

const uint8_t au8encoder[16] = {0, 1, 255, 0, 255, 0, 0, 1, 1, 0, 0, 255, 0, 255, 1, 0};

// Global Variables.
uint8_t u8encoderDelta;
uint16_t u16adcTimer;

// Interrupts Service Routines
void _ISR_NOPSV _T1Interrupt(void)
{
    if(IFS0bits.T1IF){
        static int8_t u8encoder = 0;
        u8encoder = (u8encoder<<2) & 0x0F;
        if(ROTARY_PHASE_A) u8encoder |= 0b01; // CW.
        if(ROTARY_PHASE_B) u8encoder |= 0b10; // CCW.
        u8encoderDelta += au8encoder[u8encoder];
        IFS0bits.T1IF = 0b0;
    }
    u16adcTimer++;
}

// Main.
int main(void)
{
    // MCU Initialization.
    // Internal Oscillator Settings.
    CLKDIVbits.RCDIV = 0b000;
    // Ports Initialization.
    // Analog Inputs Settings.
    AD1PCFG = 0b1001111000111100;
    // Port A Settings.
    TRISA = 0b0000000000010111;
    PORTA = 0b0000000000000000;
    LATA = 0b0000000000000000;
    ODCA = 0b0000000000000000;
    // Port B Settings.
    TRISB = 0b0000000000011110;
    PORTB = 0b0000000000000000;
    LATB = 0b0000000000000000;
    ODCB = 0b0000000000000000;

    // Interrupts Settings.
    INTCON1 = 0x8000;
    INTCON2 = 0x0000;

    // ADC Settings.
    AD1CON1 = 0x0000;
    AD1CON1bits.ADSIDL = 0b1;
    AD1CON1bits.FORM = 0b00;
    AD1CON1bits.SSRC = 0b111;
    AD1CON1bits.ASAM = 0b1;
    AD1CON1bits.SAMP = 0b0;
    AD1CON2 = 0x0000;
    AD1CON2bits.VCFG = 0b000;
    AD1CON2bits.CSCNA = 0b1;
    AD1CON2bits.BUFS = 0b0;
    AD1CON2bits.SMPI = 0b0001;
    AD1CON2bits.BUFM = 0b0;
    AD1CON2bits.ALTS = 0b0;
    AD1CON3 = 0x0000;
    AD1CON3bits.ADRC = 0b0;
    AD1CON3bits.SAMC = 0b11111;
    AD1CON3bits.ADCS = 0b00111111;
    AD1CHS = 0x0000;
    AD1CHSbits.CH0NB = 0b0;
    AD1CHSbits.CH0SB = 0b00000;
    AD1CHSbits.CH0NA = 0b0;
    AD1CHSbits.CH0SA = 0b00000;
    AD1CSSL = 0b0000000000000011;
    // ADC Enable.
    AD1CON1bits.ADON = 0b1;

    // I2C Master Settings.
    I2C1BRG = I2C_BRG;
    I2C1CON = 0x0000;
    I2C1STAT = 0x0000;
    // I2C Enable.
    I2C1CONbits.I2CEN = 0b1;

    // Timer1 Settings.
    // ~500Hz @8MHz.
    PR1 = 3980;
    T1CON = 0x0000;
    // Timer1 Enable.
    T1CONbits.TON = 0b1;
    // Timer1 Interrupts Enable.
    IFS0bits.T1IF = 0b0;
    IEC0bits.T1IE = 0b1;
    IPC0bits.IC1IP = 0b000;

    // ST7036 Initialization.
    lcd_initialize();

    // Write 5x8 Dots Custom Patterns in ST7036 CGRAM.
    lcd_writeInstruction(ST7036_SET_CGRAM_ADDRESS);
    uint8_t line = 0;
    uint8_t pattern = 0;
    for(pattern=0; pattern<5; pattern++){
        for(line=0; line<8; line++){
            lcd_writeCharacter(au8BatteryPattern[pattern][line]);
        }
    }

    // Display String.
    LCD_BACKLIGHT_ON;
    lcd_writeStringSetCursor(au8Tronix, C0220BiZ_CONFIGURATION_FIRST_LINE);
    lcd_writeStringSetCursor(au8WWW, C0220BiZ_CONFIGURATION_SECOND_LINE);
    lcd_setCursor(C0220BiZ_CONFIGURATION_FIRST_LINE + 19);
    lcd_writeCharacter(PATTERN_BATTERY_FULL);

    uint8_t au8Buffer[6];
    uint16_t u16ADCRead, u16ADC0Last, u16ADC1Last;
    uint8_t u8LCDBacklight=0, u8encoderRotary=0, u8encoderRead=0, u8encoderLast=0, u8encoderSwitchPressed;
    uint8_t u8switchS1Pressed, u8switchS2Pressed;
    while(1){
        // ADC Read every ~1s.
        if(u16adcTimer>1000){
            u16ADCRead = 0;
            AD1CHSbits.CH0SA = 0b00000;
            __delay_us(5);
            while(!AD1CON1bits.DONE){};
            u16ADCRead = ADC1BUF0;
            if(u16ADC0Last != u16ADCRead){
                u16toa(u16ADCRead, au8Buffer, 10);
                lcd_clearLine(C0220BiZ_CONFIGURATION_SECOND_LINE);
                lcd_writeString(au8Adc0);
                lcd_writeString(au8Buffer);
                u16ADC0Last = u16ADCRead;
            }
            u16ADCRead = 0;
            AD1CHSbits.CH0SA = 0b00001;
            __delay_us(5);
            while(!AD1CON1bits.DONE){};
            u16ADCRead = ADC1BUF1;
            if(u16ADC1Last != u16ADCRead){
                u16toa(u16ADCRead, au8Buffer, 10);
                lcd_clearLine(C0220BiZ_CONFIGURATION_SECOND_LINE);
                lcd_writeString(au8Adc1);
                lcd_writeString(au8Buffer);
                u16ADC1Last = u16ADCRead;
            }
            u16adcTimer = 0;
        }

        // ROTARY ENCODER.
        if(!ROTARY_SWITCH){
            __delay_ms(100);
            u8encoderSwitchPressed = !u8encoderSwitchPressed;
            lcd_clearLine(C0220BiZ_CONFIGURATION_SECOND_LINE);
            if(u8encoderSwitchPressed){
                u16toa(u8encoderRotary, au8Buffer, 10);
                lcd_writeString(au8Encoder);
                lcd_writeString(au8Buffer);
            }else if(!u8encoderSwitchPressed){
                u16toa(u8LCDBacklight, au8Buffer, 10);
                lcd_writeString(au8Backlight);
                lcd_writeString(au8Buffer);
            }
            while(!ROTARY_SWITCH){};
        }

        u8encoderRead += rotary_i8encoderFilter();
        if(u8encoderLast != u8encoderRead){
          lcd_clearLine(C0220BiZ_CONFIGURATION_SECOND_LINE);
          if(!u8encoderSwitchPressed){
                u8LCDBacklight += u8encoderRead;
                if(u8LCDBacklight >= 33) u8LCDBacklight = 0;
                u16toa(u8LCDBacklight, au8Buffer, 10);
                lcd_writeString(au8Backlight);
                lcd_writeString(au8Buffer);
                lcd_setBacklight(30 - u8LCDBacklight);
            }else if(u8encoderSwitchPressed){
                u8encoderRotary += u8encoderRead;
                u16toa(u8encoderRotary, au8Buffer, 10);
                lcd_writeString(au8Encoder);
                lcd_writeString(au8Buffer);
                lcd_setCursor(C0220BiZ_CONFIGURATION_FIRST_LINE + 19);
                if(u8encoderRotary<51)
                    lcd_writeCharacter(PATTERN_BATTERY_EMPTY);
                else if(u8encoderRotary>50 && u8encoderRotary<101)
                    lcd_writeCharacter(PATTERN_BATTERY_1);
                else if(u8encoderRotary>100 && u8encoderRotary<151)
                    lcd_writeCharacter(PATTERN_BATTERY_2);
                else if(u8encoderRotary>150 && u8encoderRotary<201)
                    lcd_writeCharacter(PATTERN_BATTERY_3);
                else
                    lcd_writeCharacter(PATTERN_BATTERY_FULL);
            }
            u8encoderLast = u8encoderRead;
            u8encoderRead = 0;
        }

        // SWITCHS.
        if(!SWITCH_S1){
            __delay_ms(100);
            u8switchS1Pressed = 0b1;
            lcd_clearLine(C0220BiZ_CONFIGURATION_SECOND_LINE);
            lcd_writeString(au8Switch1);
            lcd_writeString(au8Pressed);
            LCD_BACKLIGHT_ON;
            while(!SWITCH_S1){};
        }else if(SWITCH_S1){
            if(u8switchS1Pressed){
                lcd_clearLine(C0220BiZ_CONFIGURATION_SECOND_LINE);
                lcd_writeString(au8Switch1);
                lcd_writeString(au8Released);
                u8switchS1Pressed = 0b0;
            }
        }
        if(!SWITCH_S2){
            __delay_ms(100);
            u8switchS2Pressed = 0b1;
            lcd_clearLine(C0220BiZ_CONFIGURATION_SECOND_LINE);
            lcd_writeString(au8Switch2);
            lcd_writeString(au8Pressed);
            LCD_BACKLIGHT_OFF;
            while(!SWITCH_S2){};
        }else if(SWITCH_S2){
            if(u8switchS2Pressed){
                lcd_clearLine(C0220BiZ_CONFIGURATION_SECOND_LINE);
                lcd_writeString(au8Switch2);
                lcd_writeString(au8Released);
                u8switchS2Pressed = 0b0;
            }
        }
    }
    return(0);
}

// Functions.
void i2c_restart(void)
{
    while(I2C1CON & 0x001F){};
    I2C1CONbits.RSEN = 0b1;
    while(I2C1CONbits.RSEN){};
}

void i2c_start(void)
{
    while(I2C1CON & 0x001F){};
    I2C1CONbits.SEN = 0b1;
    while(I2C1CONbits.SEN){};
}

void i2c_stop(void)
{
    while(I2C1CON & 0x001F){};
    I2C1CONbits.PEN = 0b1;
    while(I2C1CONbits.PEN){};
}

void i2c_write(uint8_t u8Data)
{
    I2C1TRN = u8Data;
    while(I2C1STATbits.TRSTAT){};
}

void lcd_clearDisplay(void)
{
    lcd_writeInstruction(ST7036_CLEAR_DISPLAY);
    __delay_ms(ST7036_CLEAR_DISPLAY_DELAY_MS);
}

void lcd_clearLine(uint8_t u8Line)
{
    uint8_t character = C0220BiZ_CONFIGURATION_CHARACTERS;

    i2c_start();
    i2c_write(C0220BiZ_CONFIGURATION_I2C_ADDRESS | I2C_WRITE);
    i2c_write(ST7036_I2C_CONTROL_NO_CONTINUOUS_COMMAND);
    i2c_write(u8Line);
    i2c_write(ST7036_I2C_CONTROL_CONTINUOUS_DATA);
    while(character--)
        i2c_write(ASCII_SPACE);
    i2c_restart();
    i2c_write(C0220BiZ_CONFIGURATION_I2C_ADDRESS | I2C_WRITE);
    i2c_write(ST7036_I2C_CONTROL_NO_CONTINUOUS_COMMAND);
    i2c_write(u8Line);
    i2c_stop();
}

void lcd_initialize(void)
{
    __delay_ms(ST7036_INITIALIZATION_DELAY_MS);

    i2c_start();
    i2c_write(C0220BiZ_CONFIGURATION_I2C_ADDRESS | I2C_WRITE);
    i2c_write(ST7036_I2C_CONTROL_CONTINUOUS_COMMAND);
    // Instruction Table IS2=0, IS1=1.
    i2c_write(ST7036_FUNCTION_SET_8_BIT_ONE_LINE_FONT5x8_IS1);
    i2c_write(ST7036_BIAS_SET_1_5);
    i2c_write(ST7036_CONTRAST_LSB_12);
    i2c_write(ST7036_POWER_ICON_ON_BOOST_ON_CONTRAST_MSB_1);
    i2c_write(ST7036_FOLLOWER_CONTROL_ON_RAB_5);
    // Instruction Table IS2=0, IS1=0.
    i2c_write(ST7036_FUNCTION_SET_8_BIT_TWO_LINE_FONT5x8);
    i2c_write(ST7036_DISPLAY_ON_CURSOR_OFF);
    i2c_write(ST7036_ENTRY_MODE_SET_DDRAM_INCREMENT_NOSHIFT);
    i2c_write(ST7036_CLEAR_DISPLAY);
    i2c_stop();
    __delay_ms(ST7036_CLEAR_DISPLAY_DELAY_MS);
}

void lcd_setBacklight(uint8_t u8Backlight)
{
    // CAT4002 DIM Reset.
    LCD_BACKLIGHT_OFF;
    __delay_ms(CAT4002_DELAY_DIM_MS);
    LCD_BACKLIGHT_ON;
    __delay_us(CAT4002_DELAY_LED_US);

    // CAT4002 DIM Pulses.
    IEC0bits.T1IE = 0b0;
    do{
        LCD_BACKLIGHT_OFF;
        LCD_BACKLIGHT_ON;
    } while(u8Backlight--);
    IEC0bits.T1IE = 0b1;
}

void lcd_setCursor(uint8_t u8Cursor)
{
    i2c_start();
    i2c_write(C0220BiZ_CONFIGURATION_I2C_ADDRESS | I2C_WRITE);
    i2c_write(ST7036_I2C_CONTROL_NO_CONTINUOUS_COMMAND);
    i2c_write(u8Cursor);
    i2c_stop();
}

void lcd_writeCharacter(uint8_t u8Data)
{
    i2c_start();
    i2c_write(C0220BiZ_CONFIGURATION_I2C_ADDRESS | I2C_WRITE);
    i2c_write(ST7036_I2C_CONTROL_NO_CONTINUOUS_DATA);
    i2c_write(u8Data);
    i2c_stop();
}

void lcd_writeInstruction(uint8_t u8Data)
{
    i2c_start();
    i2c_write(C0220BiZ_CONFIGURATION_I2C_ADDRESS | I2C_WRITE);
    i2c_write(ST7036_I2C_CONTROL_NO_CONTINUOUS_COMMAND);
    i2c_write(u8Data);
    i2c_stop();
}

void lcd_writeString(const uint8_t * u8Data)
{
    i2c_start();
    i2c_write(C0220BiZ_CONFIGURATION_I2C_ADDRESS | I2C_WRITE);
    i2c_write(ST7036_I2C_CONTROL_CONTINUOUS_DATA);
    while(*u8Data != '\0')
        i2c_write(*u8Data++);
    i2c_stop();
}

void lcd_writeStringSetCursor(const uint8_t * u8Data, uint8_t u8Cursor)
{
    i2c_start();
    i2c_write(C0220BiZ_CONFIGURATION_I2C_ADDRESS | I2C_WRITE);
    i2c_write(ST7036_I2C_CONTROL_NO_CONTINUOUS_COMMAND);
    i2c_write(u8Cursor);
    i2c_write(ST7036_I2C_CONTROL_CONTINUOUS_DATA);
    while(*u8Data != '\0')
        i2c_write(*u8Data++);
    i2c_stop();
}

int8_t rotary_i8encoderFilter(void)
{
    int8_t i8encoderFilter;

    IEC0bits.T1IE = 0b0;
    i8encoderFilter = u8encoderDelta;
    u8encoderDelta = i8encoderFilter & 3;
    IEC0bits.T1IE = 0b1;

    return(i8encoderFilter>>2);
}

void u16toa(uint16_t u16Data, uint8_t * au8Buffer, uint8_t u8Base)
{
    uint8_t u8Buffer;
    uint16_t data = u16Data;

    do{
        data /= u8Base;
        au8Buffer++;
    }while(data != '\0');
    *au8Buffer-- = 0;

    do{
        u8Buffer = (uint8_t)(u16Data % u8Base); // todo
        u16Data /= u8Base;
        if(u8Buffer >= 10)
            u8Buffer += 'A' - '0' - 10;
        u8Buffer += '0';
        *au8Buffer-- = u8Buffer;
    }while(u16Data != '\0');
}
```

---
DISCLAIMER: THIS CODE IS PROVIDED WITHOUT ANY WARRANTY OR GUARANTEES.
USERS MAY USE THIS CODE FOR DEVELOPMENT AND EXAMPLE PURPOSES ONLY.
AUTHORS ARE NOT RESPONSIBLE FOR ANY ERRORS, OMISSIONS, OR DAMAGES THAT COULD
RESULT FROM USING THIS FIRMWARE IN WHOLE OR IN PART.

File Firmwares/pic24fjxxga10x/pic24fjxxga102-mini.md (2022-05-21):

# PIC16-Bit Mini Trainer.

## 0.Contents.

- [1.DRAFT - EUSART - ADC - SWITCHS - ROTARY ENCODER.](#1draft---eusart---adc---switchs---rotary-encoder)
- [2.DRAFT - LCD - ADC - SWITCHS - ROTARY ENCODER.](#2draft---lcd---adc---switchs---rotary-encoder)

## 1.DRAFT - EUSART - ADC - SWITCHS - ROTARY ENCODER.

```c
// Configuration Registers.
#pragma config DSWDTPS = DSWDTPSF, DSWDTOSC = LPRC
#pragma config RTCOSC = SOSC, DSBOREN = ON, DSWDTEN = ON
#pragma config WPFP = WPFP63, SOSCSEL = IO, WUTSEL = LEG
#pragma config WPDIS = WPDIS, WPCFG = WPCFGDIS, WPEND = WPENDMEM
#pragma config POSCMOD = NONE, I2C1SEL = PRI, IOL1WAY = ON
#pragma config OSCIOFNC = ON, FCKSM = CSDCMD, FNOSC = FRC, IESO = OFF
#pragma config WDTPS = PS32768, FWPSA = PR128, WINDIS = OFF
#pragma config FWDTEN = OFF, ICS = PGx1, GWRP = OFF, GCP = OFF, JTAGEN = OFF

#define FOSC (8000000UL)
#define FCY (FOSC/2)
#define _ISR_FAST __attribute__ ((interrupt, shadow))
#define _ISR_PSV __attribute__ ((interrupt, auto_psv))
#define _ISR_NOPSV __attribute__ ((interrupt, no_auto_psv))

#include <xc.h>
#include <libpic30.h>
// PIC24FJxxGA102 - Compile with XC16(v2.00).
// PIC24FJxxGA102 - @8MHz Internal Oscillator.

// Rotary encoder code from:
// https://www.mikrocontroller.net/articles/Drehgeber

// PIC16-Bit Mini Trainer.
// 2x ADC CHANNELS.
// 1x EUSART ASYNCHRONOUS TX/RX.
// 1x ROTARY ENCODER with SWITCH.
// 2x SWITCHS.

// PIC16-Bit Mini Trainer.
// URX - Close.
// UTX - Close.
// SDA - Open.
// SCL - Open.
// VREG - GND.
// VCAP - Close.
// BCKL - Open.

// Pinout.
// MCU.RA0 <- ANALOG.AN1.
// MCU.RA1 <- ANALOG.AN2.
// MCU.RB2 <- SWITCH.S1.
// MCU.RB3 <- SWITCH.S2.
// MCU.RA2 <- ROTARY.A.
// MCU.RA3 <- ROTARY.B.
// MCU.RB4 <- ROTARY.S.

// Definitions.
// EUSART.
#define BAUDRATE                    9600
#define BAUDRATE_GENERATOR_BRGH_0   (((FCY/BAUDRATE)/16)-1)
#define BAUDRATE_GENERATOR_BRGH_1   (((FCY/BAUDRATE)/4)-1)
// ASCII Characters.
#define ASCII_CR                    0x0D
// Rotary Encoder.
#define ROTARY_ENCODER_A            PORTAbits.RA2
#define ROTARY_ENCODER_B            PORTAbits.RA3
#define ROTARY_ENCODER_SWITCH       PORTBbits.RB4
// Switchs.
#define SWITCH_S1                   PORTBbits.RB2
#define SWITCH_S2                   PORTBbits.RB3

// Function Prototypes.
uint8_t eusart_readCharacter(void);
void eusart_writeCharacter(uint8_t u8Data);
void eusart_writeString(const uint8_t * u8Data);
int8_t rotary_u8encoderRead(void);
void u16toa(uint16_t u16Data, uint8_t * au8Buffer, uint8_t u8Base);

// Strings & Custom Patterns.
const uint8_t au8Tronix[] = "\r\n\r\nTronix I/O";
const uint8_t au8WWW[] = "\r\nhttp://www.tronix.io/\r\n";
const uint8_t au8Ready[] = "\r\nREADY> ";
const uint8_t au8Adc0[] = "\r\nADC CHANNEL 0> ";
const uint8_t au8Adc1[] = "\r\nADC CHANNEL 1> ";
const uint8_t au8Encoder[] = "\r\nROTARY ENCODER> ";
const uint8_t au8Encodersw[] = "\r\nROTARY ENCODER SWITCH> ";
const uint8_t au8Eusart[] = "\r\nEUSART ECHO> ";
const uint8_t au8Switch1[] = "\r\nSWITCH 1> ";
const uint8_t au8Switch2[] = "\r\nSWITCH 2> ";
const uint8_t au8Pressed[] = "PRESSED";
const uint8_t au8Released[] = "RELEASED";

// Global Variables.
int8_t encoderDelta;
uint16_t u16AdcTimer;
const int8_t encoderFull[16] = {0, 1, -1, 0, -1, 0, 0, 1, 1, 0, 0, -1, 0, -1, 1, 0};

// Interrupts Service Routines
void _ISR_NOPSV _T1Interrupt(void)
{
    if(IFS0bits.T1IF){
        static int8_t u8encoderLast = 0;
        u8encoderLast = (u8encoderLast<<2) & 0x0F;
        if(ROTARY_ENCODER_A) u8encoderLast |= 1;
        if(ROTARY_ENCODER_B) u8encoderLast |= 2;
        encoderDelta += encoderFull[u8encoderLast];
        IFS0bits.T1IF = 0b0;
    }
    u16AdcTimer++;
}

// Main.
int main(void)
{
    // MCU Initialization.
    // Internal Oscillator Settings.
    CLKDIVbits.RCDIV = 0b000;
    // Ports Initialization.
    // Analog Inputs Settings.
    AD1PCFG = 0b1001111000111100;
    // Port A Settings.
    TRISA = 0b0000000000001111;
    PORTA = 0b0000000000000000;
    LATA = 0b0000000000000000;
    ODCA = 0b0000000000000000;
    // Port B Settings.
    TRISB = 0b0000000000011110;
    PORTB = 0b0000000000000000;
    LATB = 0b0000000000000000;
    ODCB = 0b0000000000000000;
    // PPS Settings.
    __builtin_write_OSCCONL(OSCCON & 0xBF);
    // PPS Inputs.
    RPINR18bits.U1RXR = 0b00001;    // RB1 - RP1 - EUSART.U1RX.
    // PPS Outputs.
    RPOR0bits.RP0R = 0b00011;       // RB0 - RP0 - EUSART.U1TX.
    __builtin_write_OSCCONL(OSCCON | 0x40);

    // Interrupts Settings.
    INTCON1 = 0x8000;
    INTCON2 = 0x0000;

    // ADC Settings.
    AD1CON1 = 0x0000;
    AD1CON1bits.ADSIDL = 0b1;
    AD1CON1bits.FORM = 0b00;
    AD1CON1bits.SSRC = 0b111;
    AD1CON1bits.ASAM = 0b1;
    AD1CON1bits.SAMP = 0b0;
    AD1CON2 = 0x0000;
    AD1CON2bits.VCFG = 0b000;
    AD1CON2bits.CSCNA = 0b1;
    AD1CON2bits.BUFS = 0b0;
    AD1CON2bits.SMPI = 0b0001;
    AD1CON2bits.BUFM = 0b0;
    AD1CON2bits.ALTS = 0b0;
    AD1CON3 = 0x0000;
    AD1CON3bits.ADRC = 0b0;
    AD1CON3bits.SAMC = 0b11111;
    AD1CON3bits.ADCS = 0b00111111;
    AD1CHS = 0x0000;
    AD1CHSbits.CH0NB = 0b0;
    AD1CHSbits.CH0SB = 0b00000;
    AD1CHSbits.CH0NA = 0b0;
    AD1CHSbits.CH0SA = 0b00000;
    AD1CSSL = 0b0000000000000011;
    // ADC Enable.
    AD1CON1bits.ADON = 1;

    // EUSART Settings.
    U1BRG = BAUDRATE_GENERATOR_BRGH_0;
    U1MODE = 0x0000;
    U1MODEbits.UEN = 0b00;
    U1MODEbits.BRGH = 0b0;
    U1MODEbits.PDSEL = 0b00;
    U1MODEbits.STSEL = 0b0;
    U1STA = 0x0000;
    U1TXREG = 0x0000;
    U1RXREG = 0x0000;
    // UART Enable.
    U1MODEbits.UARTEN = 0b1;
    U1STAbits.UTXEN = 0b1;

    // Timer1 Settings.
    // ~500Hz @8MHz.
    PR1 = 3980;
    T1CON = 0x0000;
    // Timer1 Enable.
    T1CONbits.TON = 0b1;
    // Timer1 Interrupts Enable.
    IFS0bits.T1IF = 0b0;
    IEC0bits.T1IE = 0b1;
    IPC0bits.IC1IP = 0b000;

    // Display String.
    eusart_writeString(au8Tronix);
    eusart_writeString(au8WWW);
    eusart_writeString(au8Ready);

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

        // EUSART.
        if(IFS0bits.U1RXIF){
            u8Rx = eusart_readCharacter();
            eusart_writeString(au8Eusart);
            eusart_writeCharacter(u8Rx);
            if(u8Rx == ASCII_CR)
                eusart_writeString(au8Ready);
        }

        // ROTARY ENCODER.
        if(!ROTARY_ENCODER_SWITCH){
            __delay_ms(100);
            u8encoderSwitchPressed = 1;
            eusart_writeString(au8Encodersw);
            eusart_writeString(au8Pressed);
        }else if(ROTARY_ENCODER_SWITCH){
            if(u8encoderSwitchPressed){
                u8encoderSwitchPressed = 0;
                eusart_writeString(au8Encodersw);
                eusart_writeString(au8Released);
                u8encoderRead = 0;
            }
        }

        u8encoderRead += rotary_u8encoderRead();
        if(u8encoderLast != u8encoderRead){
            u16toa(u8encoderRead, au8Buffer, 10);
            eusart_writeString(au8Encoder);
            eusart_writeString(au8Buffer);
            u8encoderLast = u8encoderRead;
        }

        // SWITCHS.
        if(!SWITCH_S1){
            __delay_ms(100);
            u8switchS1Pressed = 1;
            eusart_writeString(au8Switch1);
            eusart_writeString(au8Pressed);
        }else if(SWITCH_S1){
            if(u8switchS1Pressed){
                eusart_writeString(au8Switch1);
                eusart_writeString(au8Released);
                u8switchS1Pressed = 0;
            }
        }
        if(!SWITCH_S2){
            __delay_ms(100);
            u8switchS2Pressed = 1;
            eusart_writeString(au8Switch2);
            eusart_writeString(au8Pressed);
        }else if(SWITCH_S2){
            if(u8switchS2Pressed){
                eusart_writeString(au8Switch2);
            eusart_writeString(au8Released);
            u8switchS2Pressed = 0;
            }
        }
    }
    return(0);
}

// Functions.
uint8_t eusart_readCharacter(void)
{
    while(!U1STAbits.URXDA){};
    return(U1RXREG);
}

void eusart_writeCharacter(uint8_t u8Data)
{
    while(U1STAbits.UTXBF){};
    U1TXREG = u8Data;
}

void eusart_writeString(const uint8_t * u8Data)
{
    while(*u8Data != '\0')
        eusart_writeCharacter(*u8Data++);
}

int8_t rotary_u8encoderRead(void)
{
    int8_t u8encoderRead;

    IEC0bits.T1IE = 0b0;
    u8encoderRead = encoderDelta;
    encoderDelta = u8encoderRead & 3;
    IEC0bits.T1IE = 0b1;

    return(u8encoderRead>>2);
}

void u16toa(uint16_t u16Data, uint8_t * au8Buffer, uint8_t u8Base)
{
    uint8_t u8Buffer;
    uint16_t data = u16Data;

    do{
        data /= u8Base;
        au8Buffer++;
    }while(data != '\0');
    *au8Buffer-- = 0;

    do{
        u8Buffer = (uint16_t)(u16Data % u8Base);
        u16Data /= u8Base;
        if(u8Buffer >= 10)
            u8Buffer += 'A' - '0' - 10;
        u8Buffer += '0';
        *au8Buffer-- = u8Buffer;
    }while(u16Data != '\0');
}
```

## 2.DRAFT - LCD - ADC - SWITCHS - ROTARY ENCODER.

```c
// Configuration Registers.
#pragma config DSWDTPS = DSWDTPSF, DSWDTOSC = LPRC
#pragma config RTCOSC = SOSC, DSBOREN = ON, DSWDTEN = ON
#pragma config WPFP = WPFP63, SOSCSEL = IO, WUTSEL = LEG
#pragma config WPDIS = WPDIS, WPCFG = WPCFGDIS, WPEND = WPENDMEM
#pragma config POSCMOD = NONE, I2C1SEL = PRI, IOL1WAY = ON
#pragma config OSCIOFNC = ON, FCKSM = CSDCMD, FNOSC = FRC, IESO = OFF
#pragma config WDTPS = PS32768, FWPSA = PR128, WINDIS = OFF
#pragma config FWDTEN = OFF, ICS = PGx1, GWRP = OFF, GCP = OFF, JTAGEN = OFF

#define FOSC    (8000000UL)
#define FCY     (FOSC/2)
#define _ISR_FAST __attribute__ ((interrupt, shadow))
#define _ISR_PSV __attribute__ ((interrupt, auto_psv))
#define _ISR_NOPSV __attribute__ ((interrupt, no_auto_psv))

#include <xc.h>
#include <libpic30.h>
// PIC24FJxxGA102 - Compile with XC16(v2.00).
// PIC24FJxxGA102 - @8MHz Internal Oscillator.
// v0.1 - 04/2022.

// Rotary encoder code from:
// https://www.mikrocontroller.net/articles/Drehgeber

// PIC16-Bit Mini Trainer.
// 2x ADC CHANNELS.
// 1x EUSART ASYNCHRONOUS TX/RX.
// 1x ROTARY ENCODER with SWITCH.
// 2x SWITCHS.

// PIC16-Bit Mini Trainer.
// URX - Open.
// UTX - Open.
// SDA - Close.
// SCL - Close.
// VREG - GND.
// VCAP - Close.
// BCKL - Open.

// Pinout.
// MCU.RA0 <- ANALOG.AN1.
// MCU.RA1 <- ANALOG.AN2.
// MCU.RB2 <- SWITCH.S1.
// MCU.RB3 <- SWITCH.S2.
// MCU.RA2 <- ROTARY.A.
// MCU.RA3 <- ROTARY.B.
// MCU.RB4 <- ROTARY.S.
// MCU.RB6 -> BACKLIGHT.EN.

// Definitions.
// I2C.
#define I2C_READ                                            0b1
#define I2C_WRITE                                           0b0
#define I2C_FSCL_HZ                                         400000
#define I2C_BRG                                             (((FCY/I2C_FSCL_HZ)-(FCY/10000000))-1)
// CAT4002A.
#define CAT4002_DELAY_HIGH_US                               1                               
#define CAT4002_DELAY_LED_US                                10
#define CAT4002_DELAY_LOW_US                                5
#define CAT4002_DELAY_DOWN_MS                               3
// ST7036 I2C Address.
#define ST7036_I2C_ADDRESS_78                               0x78
#define ST7036_I2C_CONTROL_CONTINUOUS_COMMAND               0x00
#define ST7036_I2C_CONTROL_CONTINUOUS_DATA                  0x40
#define ST7036_I2C_CONTROL_NO_CONTINUOUS_COMMAND            0x80
#define ST7036_I2C_CONTROL_NO_CONTINUOUS_DATA               0xC0
// ST7036 Instruction Table IS2=0, IS1=0.
#define ST7036_CLEAR_DISPLAY                                0x01
#define ST7036_RETURN_HOME                                  0x02
#define ST7036_ENTRY_MODE_SET_DDRAM_DECREMENT_NOSHIFT       0x04
#define ST7036_ENTRY_MODE_SET_DDRAM_DECREMENT_SHIFT_RIGHT   0x05
#define ST7036_ENTRY_MODE_SET_DDRAM_INCREMENT_NOSHIFT       0x06
#define ST7036_ENTRY_MODE_SET_DDRAM_INCREMENT_SHIFT_LEFT    0x07
#define ST7036_DISPLAY_OFF                                  0x08
#define ST7036_DISPLAY_ON_CURSOR_OFF                        0x0C
#define ST7036_DISPLAY_ON_CURSOR_ON_NOBLINK                 0x0E
#define ST7036_DISPLAY_ON_CURSOR_ON_BLINK                   0x0F
#define ST7036_DISPLAY_CURSOR_SHIFT_LEFT                    0x10
#define ST7036_DISPLAY_CURSOR_SHIFT_RIGHT                   0x14
#define ST7036_DISPLAY_DISPLAY_SHIFT_LEFT                   0x18
#define ST7036_DISPLAY_DISPLAY_SHIFT_RIGH                   0x1C
#define ST7036_FUNCTION_SET_4_BIT_ONE_LINE_FONT5x8          0x20
#define ST7036_FUNCTION_SET_4_BIT_ONE_LINE_FONT5x8_IS1      0x21
#define ST7036_FUNCTION_SET_4_BIT_ONE_LINE_FONT5x8_IS2      0x22
#define ST7036_FUNCTION_SET_4_BIT_TWO_LINE_FONT5x8          0x28
#define ST7036_FUNCTION_SET_4_BIT_ONE_LINE_DHFONT5x8        0x24
#define ST7036_FUNCTION_SET_4_BIT_TWO_LINE_DHFONT5x8        0x2C
#define ST7036_FUNCTION_SET_8_BIT_ONE_LINE_FONT5x8          0x30
#define ST7036_FUNCTION_SET_8_BIT_ONE_LINE_FONT5x8_IS1      0x31
#define ST7036_FUNCTION_SET_8_BIT_ONE_LINE_FONT5x8_IS2      0x32
#define ST7036_FUNCTION_SET_8_BIT_ONE_LINE_DHFONT5x8        0x34
#define ST7036_FUNCTION_SET_8_BIT_TWO_LINE_FONT5x8          0x38
#define ST7036_FUNCTION_SET_8_BIT_TWO_LINE_DHFONT5x8        0x3C
#define ST7036_SET_ICON_RAM_ADDRESS                         0X40
#define ST7036_SET_CGRAM_ADDRESS                            0x40
#define ST7036_DDRAM_ADDRESS_FIRST_LINE                     0x80
#define ST7036_DDRAM_ADDRESS_SECOND_LINE                    0xC0
// ST7036 Instruction Table IS2=0, IS1=1.
#define ST7036_BIAS_SET_1_5                                 0x14
#define ST7036_BIAS_SET_1_5_3_LINE                          0x15
#define ST7036_BIAS_SET_1_4                                 0x1C
#define ST7036_BIAS_SET_1_4_3_LINE                          0x1D
#define ST7036_POWER_ICON_OFF_BOOST_OFF_NO_CONTRAST         0x50
#define ST7036_POWER_ICON_ON_BOOST_OFF_NO_CONTRAST          0x58
#define ST7036_POWER_ICON_OFF_BOOST_ON_CONTRAST_MSB_0       0x54
#define ST7036_POWER_ICON_OFF_BOOST_ON_CONTRAST_MSB_1       0x55
#define ST7036_POWER_ICON_OFF_BOOST_ON_CONTRAST_MSB_2       0x56
#define ST7036_POWER_ICON_OFF_BOOST_ON_CONTRAST_MSB_3       0x57
#define ST7036_POWER_ICON_ON_BOOST_ON_CONTRAST_MSB_0        0x5C
#define ST7036_POWER_ICON_ON_BOOST_ON_CONTRAST_MSB_1        0x5D
#define ST7036_POWER_ICON_ON_BOOST_ON_CONTRAST_MSB_2        0x5E
#define ST7036_POWER_ICON_ON_BOOST_ON_CONTRAST_MSB_3        0x5F
#define ST7036_FOLLOWER_CONTROL_OFF                         0x60
#define ST7036_FOLLOWER_CONTROL_ON_RAB_0                    0x68
#define ST7036_FOLLOWER_CONTROL_ON_RAB_1                    0x69
#define ST7036_FOLLOWER_CONTROL_ON_RAB_2                    0x6A
#define ST7036_FOLLOWER_CONTROL_ON_RAB_3                    0x6B
#define ST7036_FOLLOWER_CONTROL_ON_RAB_4                    0x6C
#define ST7036_FOLLOWER_CONTROL_ON_RAB_5                    0x6D
#define ST7036_FOLLOWER_CONTROL_ON_RAB_6                    0x6E
#define ST7036_FOLLOWER_CONTROL_ON_RAB_7                    0x6F
#define ST7036_CONTRAST_LSB_0                               0x70
#define ST7036_CONTRAST_LSB_1                               0x71
#define ST7036_CONTRAST_LSB_2                               0x72
#define ST7036_CONTRAST_LSB_3                               0x73
#define ST7036_CONTRAST_LSB_4                               0x74
#define ST7036_CONTRAST_LSB_5                               0x75
#define ST7036_CONTRAST_LSB_6                               0x76
#define ST7036_CONTRAST_LSB_7                               0x77
#define ST7036_CONTRAST_LSB_8                               0x78
#define ST7036_CONTRAST_LSB_9                               0x79
#define ST7036_CONTRAST_LSB_10                              0x7A
#define ST7036_CONTRAST_LSB_11                              0x7B
#define ST7036_CONTRAST_LSB_12                              0x7C
#define ST7036_CONTRAST_LSB_13                              0x7D
#define ST7036_CONTRAST_LSB_14                              0x7E
#define ST7036_CONTRAST_LSB_15                              0x7F
// ST7036 Instruction Table IS2=1, IS1=0.
#define ST7036_DOUBLE_HEIGHT_FONT_COM9_COM24                0x10
#define ST7036_DOUBLE_HEIGHT_FONT_COM1_COM16                0x11
// ST7036 Delays.
#define ST7036_CLEAR_DISPLAY_DELAY_MS                       2
#define ST7036_INITIALIZATION_DELAY_MS                      40
// NHD-C0220BiZ Configuration.
#define C0220BiZ_CONFIGURATION_I2C_ADDRESS                  ST7036_I2C_ADDRESS_78
#define C0220BiZ_CONFIGURATION_FIRST_LINE                   ST7036_DDRAM_ADDRESS_FIRST_LINE
#define C0220BiZ_CONFIGURATION_SECOND_LINE                  ST7036_DDRAM_ADDRESS_SECOND_LINE
#define C0220BiZ_CONFIGURATION_CHARACTERS                   20
// ASCII Characters.
#define ASCII_SPACE                                         0x20
// Patterns.
#define PATTERN_BATTERY_FULL                                0x04
#define PATTERN_BATTERY_3_5                                 0x03
#define PATTERN_BATTERY_2_5                                 0x02
#define PATTERN_BATTERY_1_5                                 0x01
#define PATTERN_BATTERY_EMPTY                               0x00
// LCD.
#define LCD_BACKLIGHT_OFF                                   LATBbits.LATB6 = 0b0
#define LCD_BACKLIGHT_ON                                    LATBbits.LATB6 = 0b1
// Rotary Encoder.
#define ROTARY_ENCODER_A                                    PORTAbits.RA2
#define ROTARY_ENCODER_B                                    PORTAbits.RA3
#define ROTARY_ENCODER_SWITCH                               PORTBbits.RB4
// Switchs.
#define SWITCH_S1                                           PORTBbits.RB2
#define SWITCH_S2                                           PORTBbits.RB3

// Function Prototypes.
void i2c_restart(void);
void i2c_start(void);
void i2c_stop(void);
void i2c_write(uint8_t u8Data);
void lcd_clearDisplay(void);
void lcd_clearLine(uint8_t u8Line);
void lcd_initialize(void);
void lcd_setBacklight(uint8_t u8Backlight);
void lcd_setCursor(uint8_t u8Cursor);
void lcd_writeCharacter(uint8_t u8Data);
void lcd_writeInstruction(uint8_t u8Data);
void lcd_writeString(const uint8_t * u8Data);
void lcd_writeStringSetCursor(const uint8_t * u8Data, uint8_t u8Cursor);
int8_t rotary_u8encoderRead(void);
void u16toa(uint16_t u16Data, uint8_t * au8Buffer, uint8_t u8Base);

// Strings & Custom Patterns.
const uint8_t au8Tronix[] = "Tronix I/O";
const uint8_t au8WWW[] = "www.tronix.io";
const uint8_t au8Adc0[] = "ADC CHANNEL 0> ";
const uint8_t au8Adc1[] = "ADC CHANNEL 1> ";
const uint8_t au8Encoder[] = "ROTARY> ";
const uint8_t au8Encodersw[] = "ROTARY SW> ";
const uint8_t au8Backlight[] = "BACKLIGHT> ";
const uint8_t au8Switch1[] = "SWITCH 1> ";
const uint8_t au8Switch2[] = "SWITCH 2> ";
const uint8_t au8Pressed[] = "PRESSED";
const uint8_t au8Released[] = "RELEASED";

const uint8_t au8BatteryPattern[5][8] = {
    {0x0e, 0x1b, 0x11, 0x11, 0x11, 0x11, 0x11, 0x1f},
    {0x0e, 0x1b, 0x11, 0x11, 0x11, 0x1f, 0x1f, 0x1f},
    {0x0e, 0x1b, 0x11, 0x11, 0x1f, 0x1f, 0x1f, 0x1f},
    {0x0e, 0x1b, 0x11, 0x1f, 0x1f, 0x1f, 0x1f, 0x1f},
    {0x0e, 0x1f, 0x1f, 0x1f, 0x1f, 0x1f, 0x1f, 0x1f}
};

// Global Variables.
int8_t encoderDelta;
uint16_t u16AdcTimer;
const int8_t encoderFull[16] = {0, 1, -1, 0, -1, 0, 0, 1, 1, 0, 0, -1, 0, -1, 1, 0};

// Interrupts Service Routines
void _ISR_NOPSV _T1Interrupt(void)
{
    if(IFS0bits.T1IF){
        static int8_t u8encoderLast = 0;
        u8encoderLast = (u8encoderLast<<2) & 0x0F;
        if(ROTARY_ENCODER_A) u8encoderLast |= 1;
        if(ROTARY_ENCODER_B) u8encoderLast |= 2;
        encoderDelta += encoderFull[u8encoderLast];
        IFS0bits.T1IF = 0b0;
    }
    u16AdcTimer++;
}

// Main.
int main(void)
{
    // MCU Initialization.
    // Internal Oscillator Settings.
    CLKDIVbits.RCDIV = 0b000;
    // Ports Initialization.
    // Analog Inputs Settings.
    AD1PCFG = 0b1001111000111100;
    // Port A Settings.
    TRISA = 0b0000000000001111;
    PORTA = 0b0000000000000000;
    LATA = 0b0000000000000000;
    ODCA = 0b0000000000000000;
    // Port B Settings.
    TRISB = 0b0000000000011110;
    PORTB = 0b0000000000000000;
    LATB = 0b0000000000000000;
    ODCB = 0b0000000000000000;

    // Interrupts Settings.
    INTCON1 = 0x8000;
    INTCON2 = 0x0000;

    // ADC Settings.
    AD1CON1 = 0x0000;
    AD1CON1bits.ADSIDL = 0b1;
    AD1CON1bits.FORM = 0b00;
    AD1CON1bits.SSRC = 0b111;
    AD1CON1bits.ASAM = 0b1;
    AD1CON1bits.SAMP = 0b0;
    AD1CON2 = 0x0000;
    AD1CON2bits.VCFG = 0b000;
    AD1CON2bits.CSCNA = 0b1;
    AD1CON2bits.BUFS = 0b0;
    AD1CON2bits.SMPI = 0b0001;
    AD1CON2bits.BUFM = 0b0;
    AD1CON2bits.ALTS = 0b0;
    AD1CON3 = 0x0000;
    AD1CON3bits.ADRC = 0b0;
    AD1CON3bits.SAMC = 0b11111;
    AD1CON3bits.ADCS = 0b00111111;
    AD1CHS = 0x0000;
    AD1CHSbits.CH0NB = 0b0;
    AD1CHSbits.CH0SB = 0b00000;
    AD1CHSbits.CH0NA = 0b0;
    AD1CHSbits.CH0SA = 0b00000;
    AD1CSSL = 0b0000000000000011;
    // ADC Enable.
    AD1CON1bits.ADON = 1;

    // I2C Master Settings.
    I2C1BRG = I2C_BRG;
    I2C1CON = 0x0000;
    I2C1STAT = 0x0000;
    // I2C Enable.
    I2C1CONbits.I2CEN = 0b1;

    // Timer1 Settings.
    // ~500Hz @8MHz.
    PR1 = 3980;
    T1CON = 0x0000;
    // Timer1 Enable.
    T1CONbits.TON = 0b1;
    // Timer1 Interrupts Enable.
    IFS0bits.T1IF = 0b0;
    IEC0bits.T1IE = 0b1;
    IPC0bits.IC1IP = 0b000;

    // ST7036 Initialization.
    lcd_initialize();

    // Write 5x8 Dots Custom Patterns in ST7036 CGRAM.
    lcd_writeInstruction(ST7036_SET_CGRAM_ADDRESS);
    uint8_t line = 0;
    uint8_t pattern = 0;
    for(pattern=0; pattern<5; pattern++){
        for(line=0; line<8; line++){
            lcd_writeCharacter(au8BatteryPattern[pattern][line]);
        }
    }

    // Display String.
    LCD_BACKLIGHT_ON;
    lcd_writeStringSetCursor(au8Tronix, C0220BiZ_CONFIGURATION_FIRST_LINE);
    lcd_writeStringSetCursor(au8WWW, C0220BiZ_CONFIGURATION_SECOND_LINE);
    lcd_setCursor(C0220BiZ_CONFIGURATION_FIRST_LINE + 19);
    lcd_writeCharacter(PATTERN_BATTERY_FULL);

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

        // ROTARY ENCODER.
        if(!ROTARY_ENCODER_SWITCH){
            __delay_ms(100);
            u8encoderSwitchPressed = 1;
            lcd_clearLine(C0220BiZ_CONFIGURATION_SECOND_LINE);
            lcd_writeString(au8Encodersw);
            lcd_writeString(au8Pressed);
        }else if(ROTARY_ENCODER_SWITCH){
            if(u8encoderSwitchPressed){
                u8encoderSwitchPressed = 0;
                lcd_clearLine(C0220BiZ_CONFIGURATION_SECOND_LINE);
                lcd_writeString(au8Encodersw);
                lcd_writeString(au8Released);
                u8encoderRead = 0;
            }
        }

        u8encoderRead += rotary_u8encoderRead();
        if(u8encoderLast != u8encoderRead){
          lcd_clearLine(C0220BiZ_CONFIGURATION_SECOND_LINE);
          if(!u8encoderSwitchPressed){
                u8LCDBacklight += u8encoderRead;
                if(u8LCDBacklight >= 32) u8LCDBacklight = 0;
                u16toa(u8LCDBacklight, au8Buffer, 10);
                lcd_writeString(au8Backlight);
                lcd_writeString(au8Buffer);
                lcd_setBacklight(31 - u8LCDBacklight);
            }else if(u8encoderSwitchPressed){
                u8encoderRotary += u8encoderRead;
                u16toa(u8encoderRotary, au8Buffer, 10);
                lcd_writeString(au8Encoder);
                lcd_writeString(au8Buffer);
                lcd_setCursor(C0220BiZ_CONFIGURATION_FIRST_LINE + 19);
                if(u8encoderRotary<51)
                    lcd_writeCharacter(PATTERN_BATTERY_EMPTY);
                else if(u8encoderRotary>50 && u8encoderRotary<101)
                    lcd_writeCharacter(PATTERN_BATTERY_1_5);
                else if(u8encoderRotary>100 && u8encoderRotary<151)
                    lcd_writeCharacter(PATTERN_BATTERY_2_5);
                else if(u8encoderRotary>150 && u8encoderRotary<201)
                    lcd_writeCharacter(PATTERN_BATTERY_3_5);
                else
                    lcd_writeCharacter(PATTERN_BATTERY_FULL);
            }
            u8encoderLast = u8encoderRead;
            u8encoderRead = 0;
        }

        // SWITCHS.
        if(!SWITCH_S1){
            __delay_ms(100);
            u8switchS1Pressed = 1;
            lcd_clearLine(C0220BiZ_CONFIGURATION_SECOND_LINE);
            lcd_writeString(au8Switch1);
            lcd_writeString(au8Pressed);
        }else if(SWITCH_S1){
            if(u8switchS1Pressed){
                lcd_clearLine(C0220BiZ_CONFIGURATION_SECOND_LINE);
                lcd_writeString(au8Switch1);
                lcd_writeString(au8Released);
                u8switchS1Pressed = 0;
            }
        }
        if(!SWITCH_S2){
            __delay_ms(100);
            u8switchS2Pressed = 1;
            lcd_clearLine(C0220BiZ_CONFIGURATION_SECOND_LINE);
            lcd_writeString(au8Switch2);
            lcd_writeString(au8Pressed);
        }else if(SWITCH_S2){
            if(u8switchS2Pressed){
                lcd_clearLine(C0220BiZ_CONFIGURATION_SECOND_LINE);
                lcd_writeString(au8Switch2);
                lcd_writeString(au8Released);
                u8switchS2Pressed = 0;
            }
        }
    }
    return(0);
}

// Functions.
void i2c_restart(void)
{
    while(I2C1CON & 0x001F){};
    I2C1CONbits.RSEN = 0b1;
    while(I2C1CONbits.RSEN){};
}

void i2c_start(void)
{
    while(I2C1CON & 0x001F){};
    I2C1CONbits.SEN = 0b1;
    while(I2C1CONbits.SEN){};
}

void i2c_stop(void)
{
    while(I2C1CON & 0x001F){};
    I2C1CONbits.PEN = 0b1;
    while(I2C1CONbits.PEN){};
}

void i2c_write(uint8_t u8Data)
{
    I2C1TRN = u8Data;
    while(I2C1STATbits.TRSTAT){};
}

void lcd_clearDisplay(void)
{
    lcd_writeInstruction(ST7036_CLEAR_DISPLAY);
    __delay_ms(ST7036_CLEAR_DISPLAY_DELAY_MS);
}

void lcd_clearLine(uint8_t u8Line)
{
    uint8_t character = C0220BiZ_CONFIGURATION_CHARACTERS;

    i2c_start();
    i2c_write(C0220BiZ_CONFIGURATION_I2C_ADDRESS | I2C_WRITE);
    i2c_write(ST7036_I2C_CONTROL_NO_CONTINUOUS_COMMAND);
    i2c_write(u8Line);
    i2c_write(ST7036_I2C_CONTROL_CONTINUOUS_DATA);
    while(character--)
        i2c_write(ASCII_SPACE);
    i2c_restart();
    i2c_write(C0220BiZ_CONFIGURATION_I2C_ADDRESS | I2C_WRITE);
    i2c_write(ST7036_I2C_CONTROL_NO_CONTINUOUS_COMMAND);
    i2c_write(u8Line);
    i2c_stop();
}

void lcd_initialize(void)
{
    __delay_ms(ST7036_INITIALIZATION_DELAY_MS);

    i2c_start();
    i2c_write(C0220BiZ_CONFIGURATION_I2C_ADDRESS | I2C_WRITE);
    i2c_write(ST7036_I2C_CONTROL_CONTINUOUS_COMMAND);
    // Instruction Table IS2=0, IS1=1.
    i2c_write(ST7036_FUNCTION_SET_8_BIT_ONE_LINE_FONT5x8_IS1);
    i2c_write(ST7036_BIAS_SET_1_5);
    i2c_write(ST7036_CONTRAST_LSB_12);
    i2c_write(ST7036_POWER_ICON_ON_BOOST_ON_CONTRAST_MSB_1);
    i2c_write(ST7036_FOLLOWER_CONTROL_ON_RAB_5);
    // Instruction Table IS2=0, IS1=0.
    i2c_write(ST7036_FUNCTION_SET_8_BIT_TWO_LINE_FONT5x8);
    i2c_write(ST7036_DISPLAY_ON_CURSOR_OFF);
    i2c_write(ST7036_ENTRY_MODE_SET_DDRAM_INCREMENT_NOSHIFT);
    i2c_write(ST7036_CLEAR_DISPLAY);
    __delay_ms(ST7036_CLEAR_DISPLAY_DELAY_MS);
    i2c_stop();
}

void lcd_setBacklight(uint8_t u8Backlight)
{
    // CAT4002 DIM Reset.
    LCD_BACKLIGHT_OFF;
    __delay_ms(CAT4002_DELAY_DOWN_MS);
    LCD_BACKLIGHT_OFF;
    __delay_us(CAT4002_DELAY_LED_US);

    // CAT4002 DIM Pulses.
    IEC0bits.T1IE = 0b0;
    do{
        LCD_BACKLIGHT_OFF;
        __delay_us(CAT4002_DELAY_LOW_US);
        LCD_BACKLIGHT_ON;
        __delay_us(CAT4002_DELAY_HIGH_US);
    } while(u8Backlight--);
    IEC0bits.T1IE = 0b1;
}

void lcd_setCursor(uint8_t u8Cursor)
{
    i2c_start();
    i2c_write(C0220BiZ_CONFIGURATION_I2C_ADDRESS | I2C_WRITE);
    i2c_write(ST7036_I2C_CONTROL_NO_CONTINUOUS_COMMAND);
    i2c_write(u8Cursor);
    i2c_stop();
}

void lcd_writeCharacter(uint8_t u8Data)
{
    i2c_start();
    i2c_write(C0220BiZ_CONFIGURATION_I2C_ADDRESS | I2C_WRITE);
    i2c_write(ST7036_I2C_CONTROL_NO_CONTINUOUS_DATA);
    i2c_write(u8Data);
    i2c_stop();
}

void lcd_writeInstruction(uint8_t u8Data)
{
    i2c_start();
    i2c_write(C0220BiZ_CONFIGURATION_I2C_ADDRESS | I2C_WRITE);
    i2c_write(ST7036_I2C_CONTROL_NO_CONTINUOUS_COMMAND);
    i2c_write(u8Data);
    i2c_stop();
}

void lcd_writeString(const uint8_t * u8Data)
{
    i2c_start();
    i2c_write(C0220BiZ_CONFIGURATION_I2C_ADDRESS | I2C_WRITE);
    i2c_write(ST7036_I2C_CONTROL_CONTINUOUS_DATA);
    while(*u8Data != '\0')
        i2c_write(*u8Data++);
    i2c_stop();
}

void lcd_writeStringSetCursor(const uint8_t * u8Data, uint8_t u8Cursor)
{
    i2c_start();
    i2c_write(C0220BiZ_CONFIGURATION_I2C_ADDRESS | I2C_WRITE);
    i2c_write(ST7036_I2C_CONTROL_NO_CONTINUOUS_COMMAND);
    i2c_write(u8Cursor);
    i2c_write(ST7036_I2C_CONTROL_CONTINUOUS_DATA);
    while(*u8Data != '\0')
        i2c_write(*u8Data++);
    i2c_stop();
}

int8_t rotary_u8encoderRead(void)
{
    int8_t u8encoderRead;

    IEC0bits.T1IE = 0b0;
    u8encoderRead = encoderDelta;
    encoderDelta = u8encoderRead & 3;
    IEC0bits.T1IE = 0b1;

    return(u8encoderRead>>2);
}

void u16toa(uint16_t u16Data, uint8_t * au8Buffer, uint8_t u8Base)
{
    uint8_t u8Buffer;
    uint16_t data = u16Data;

    do{
        data /= u8Base;
        au8Buffer++;
    }while(data != '\0');
    *au8Buffer-- = 0;

    do{
        u8Buffer = (uint16_t)(u16Data % u8Base);
        u16Data /= u8Base;
        if(u8Buffer >= 10)
            u8Buffer += 'A' - '0' - 10;
        u8Buffer += '0';
        *au8Buffer-- = u8Buffer;
    }while(u16Data != '\0');
}
```

---
DISCLAIMER: THIS CODE IS PROVIDED WITHOUT ANY WARRANTY OR GUARANTEES.
USERS MAY USE THIS CODE FOR DEVELOPMENT AND EXAMPLE PURPOSES ONLY.
AUTHORS ARE NOT RESPONSIBLE FOR ANY ERRORS, OMISSIONS, OR DAMAGES THAT COULD
RESULT FROM USING THIS FIRMWARE IN WHOLE OR IN PART.

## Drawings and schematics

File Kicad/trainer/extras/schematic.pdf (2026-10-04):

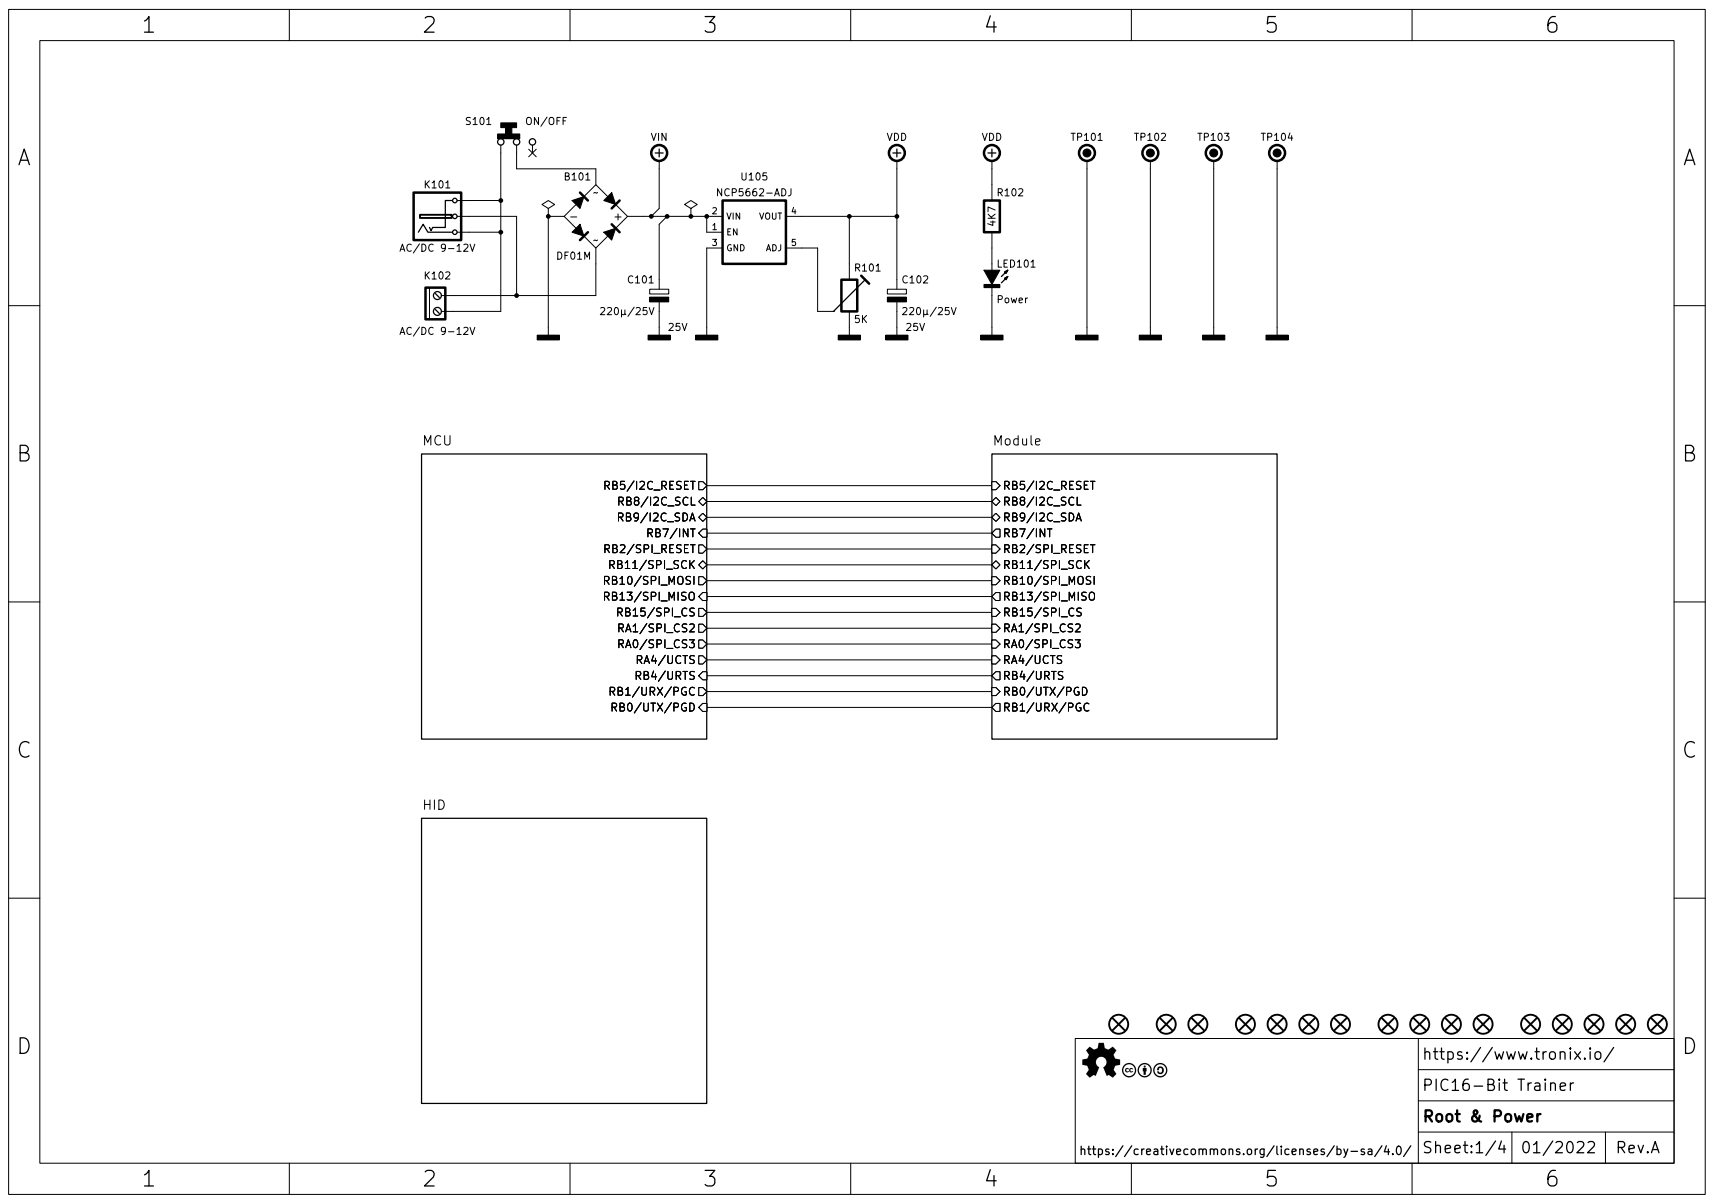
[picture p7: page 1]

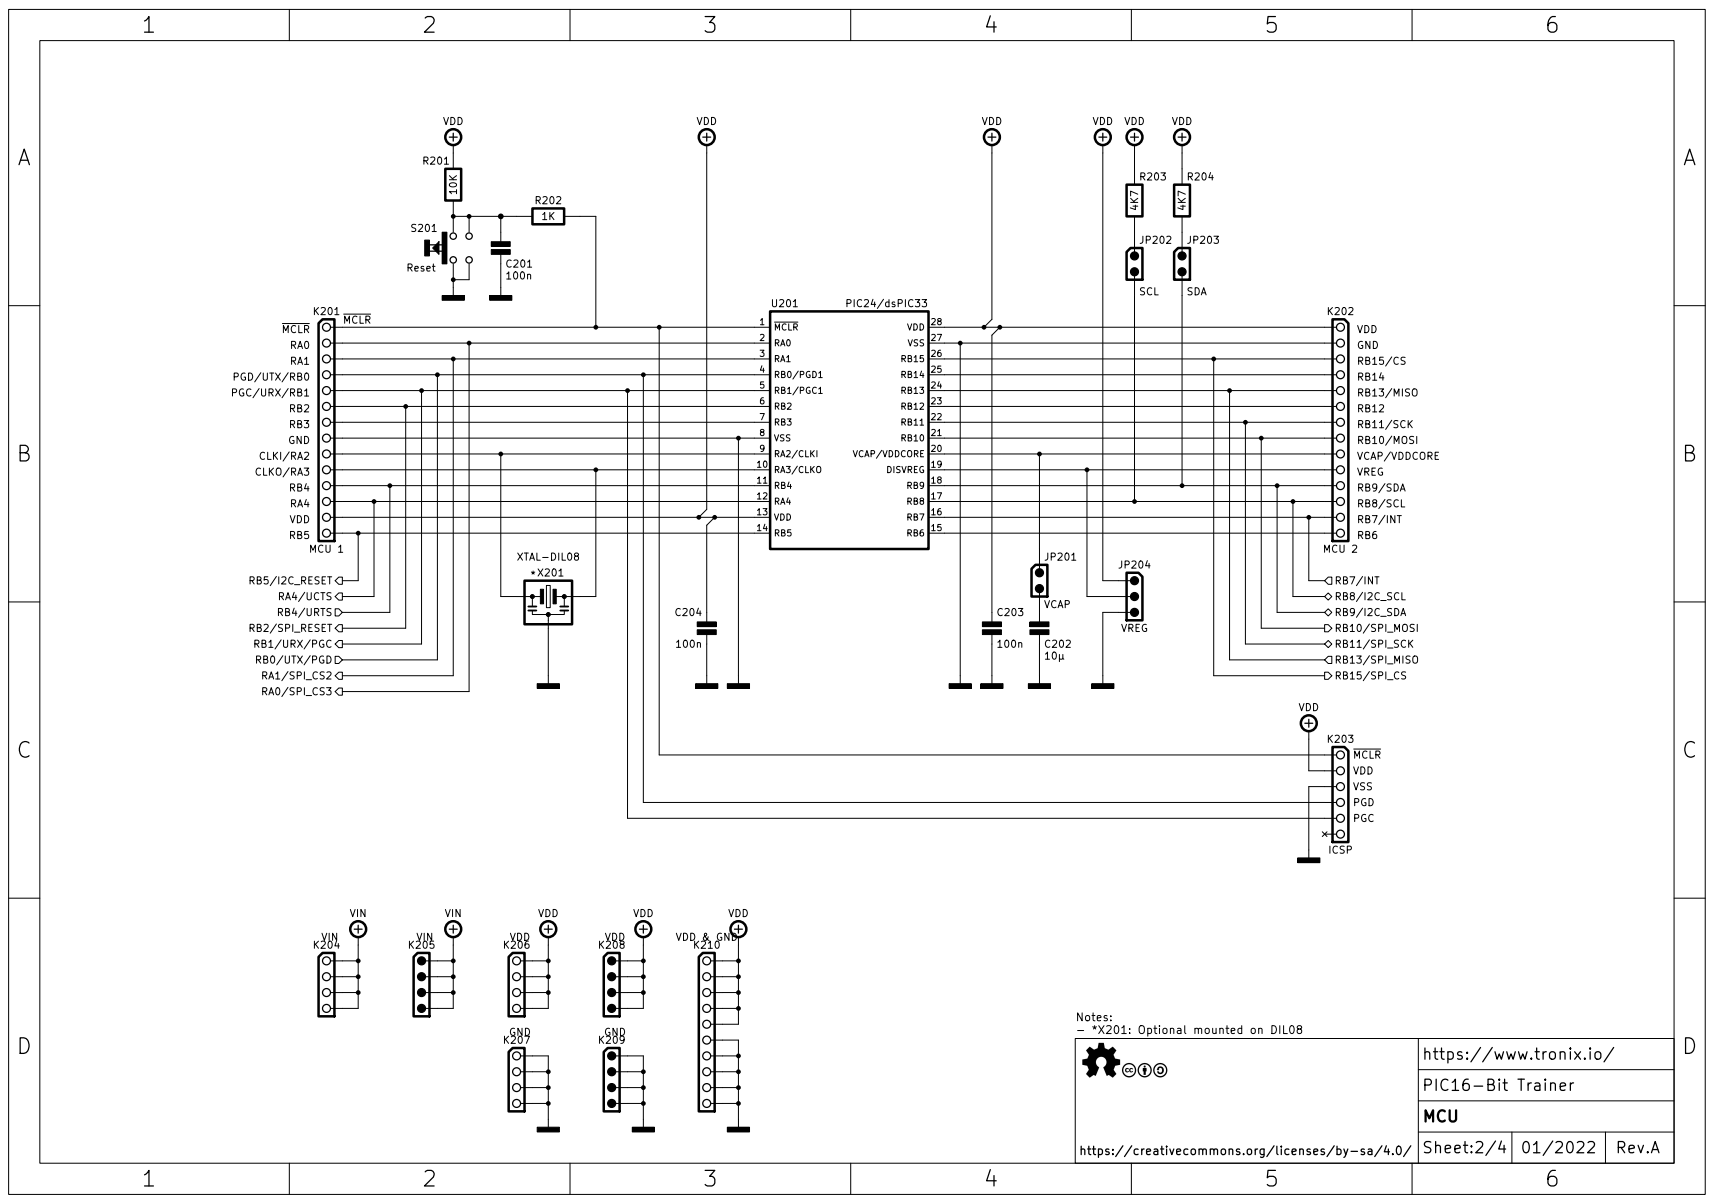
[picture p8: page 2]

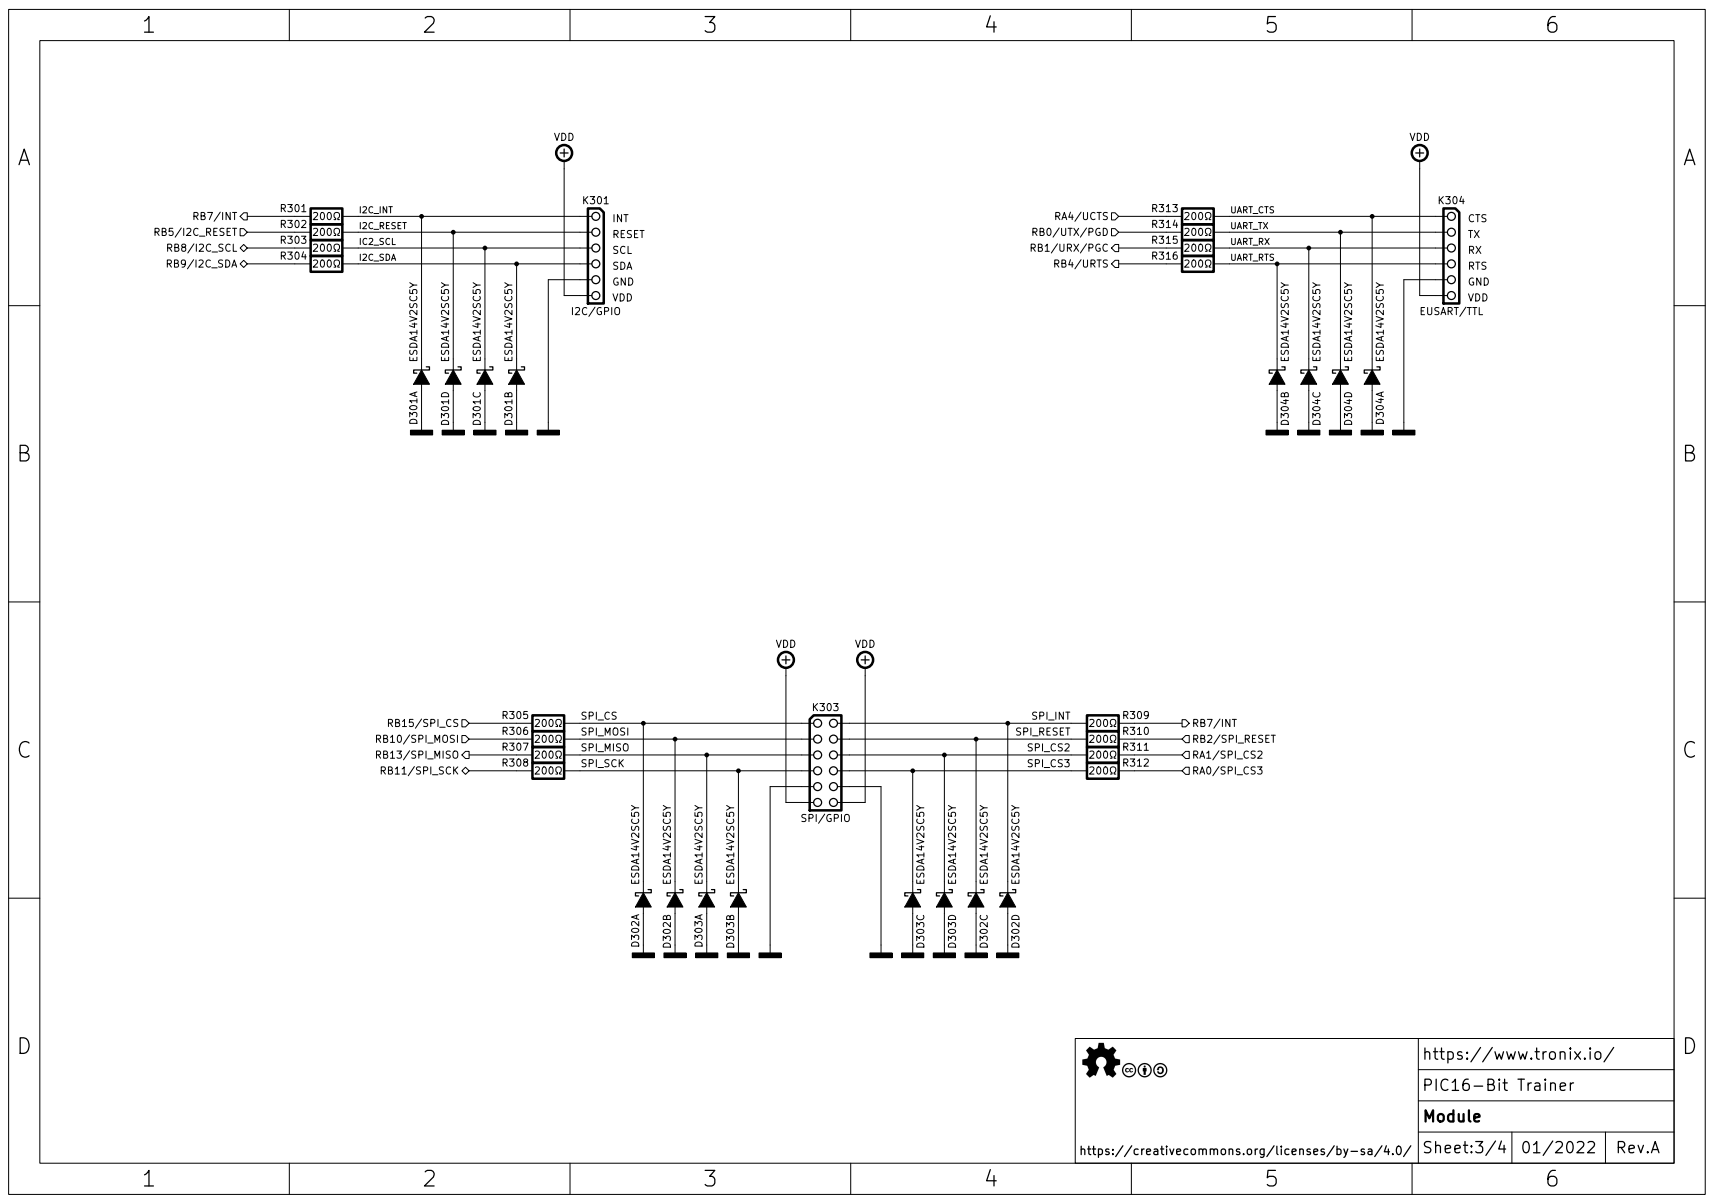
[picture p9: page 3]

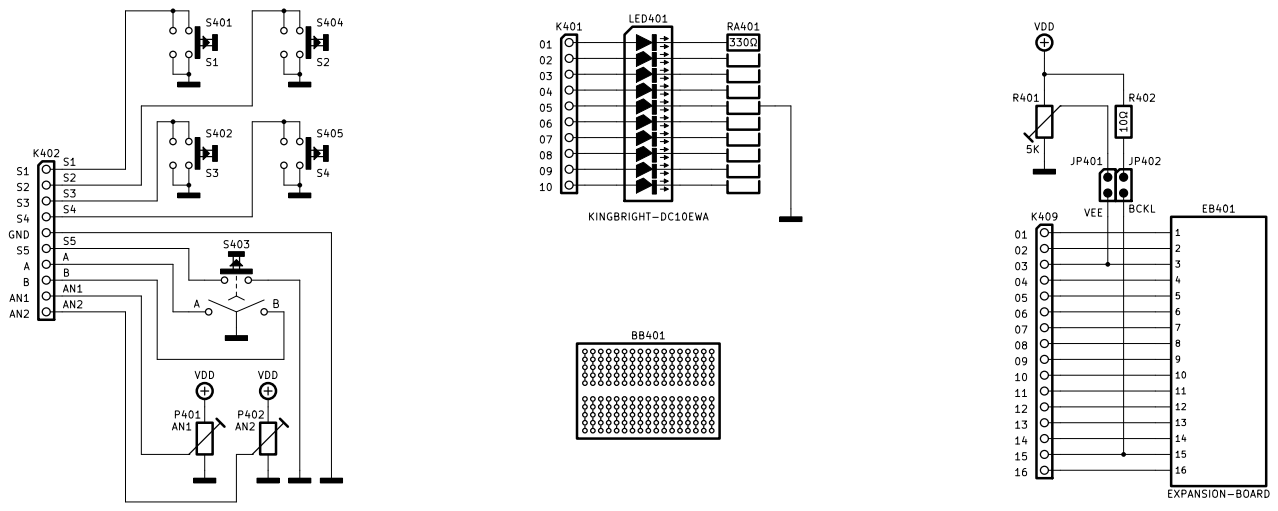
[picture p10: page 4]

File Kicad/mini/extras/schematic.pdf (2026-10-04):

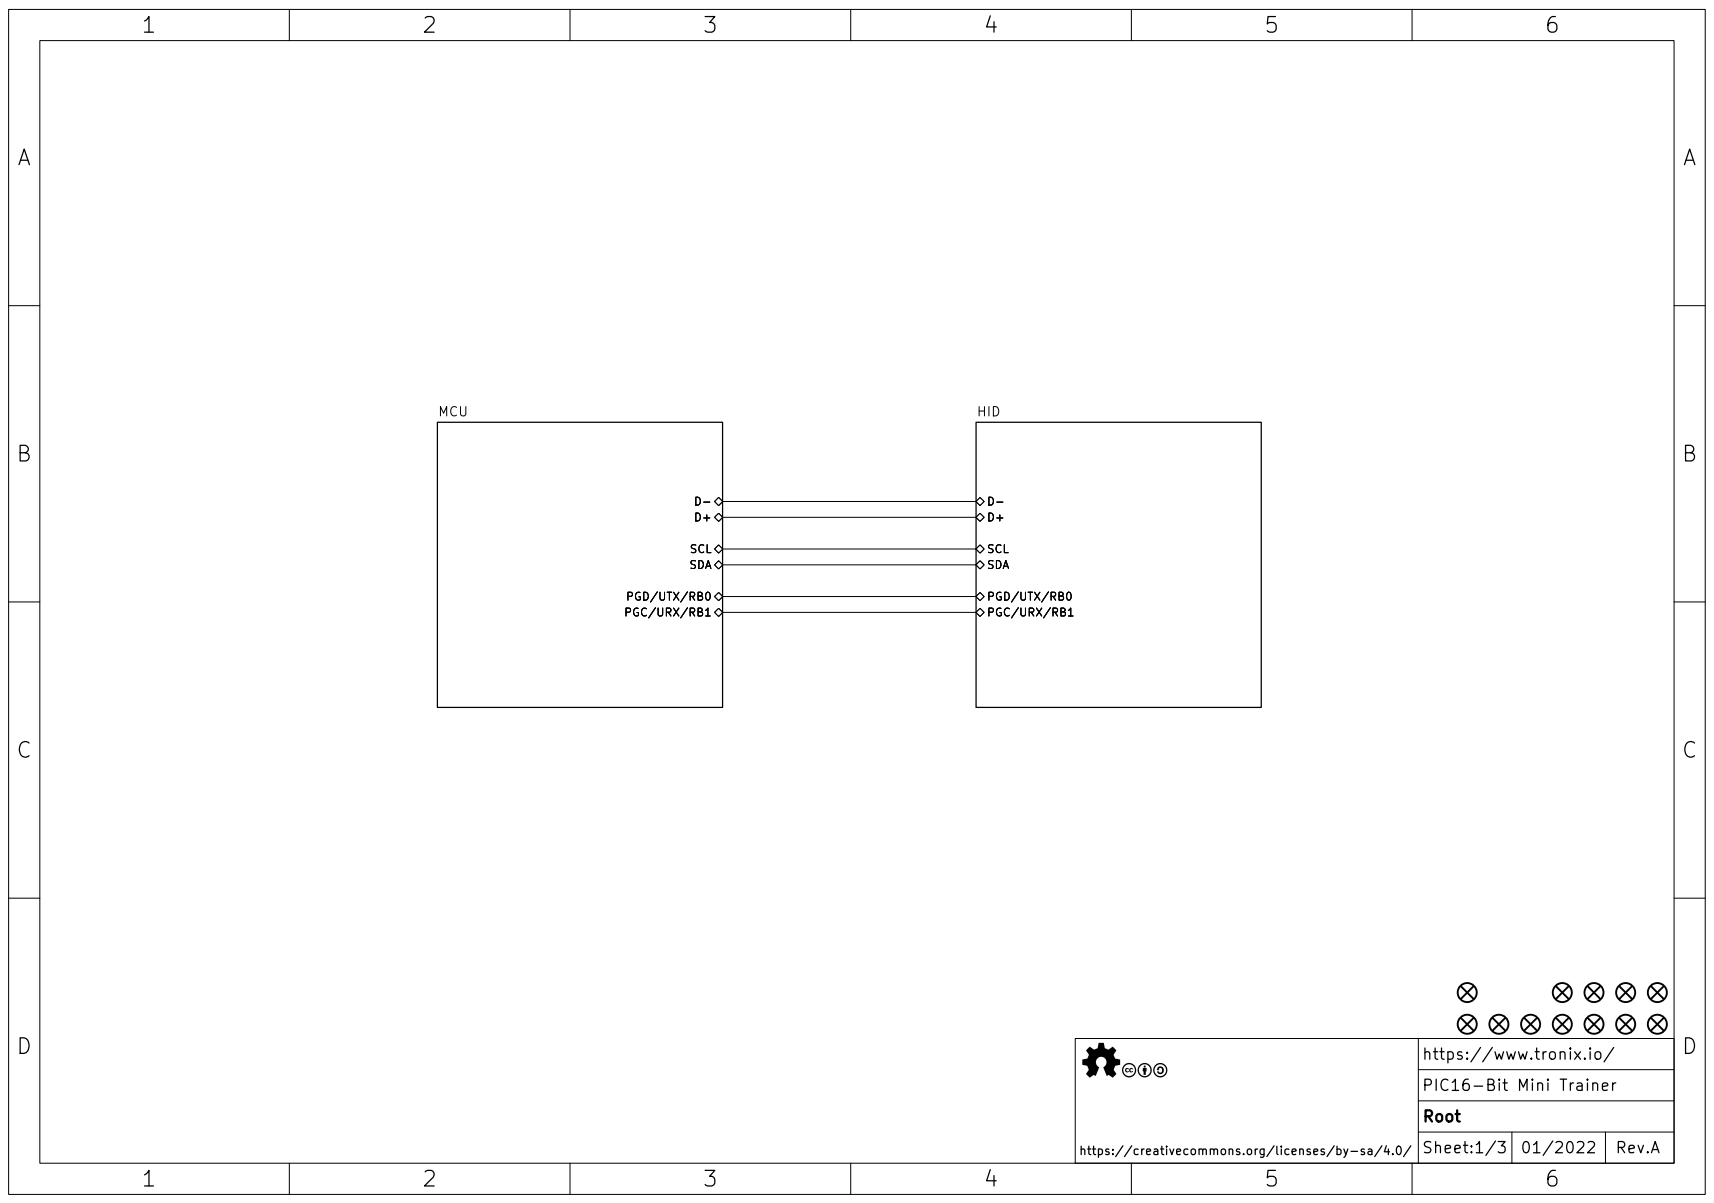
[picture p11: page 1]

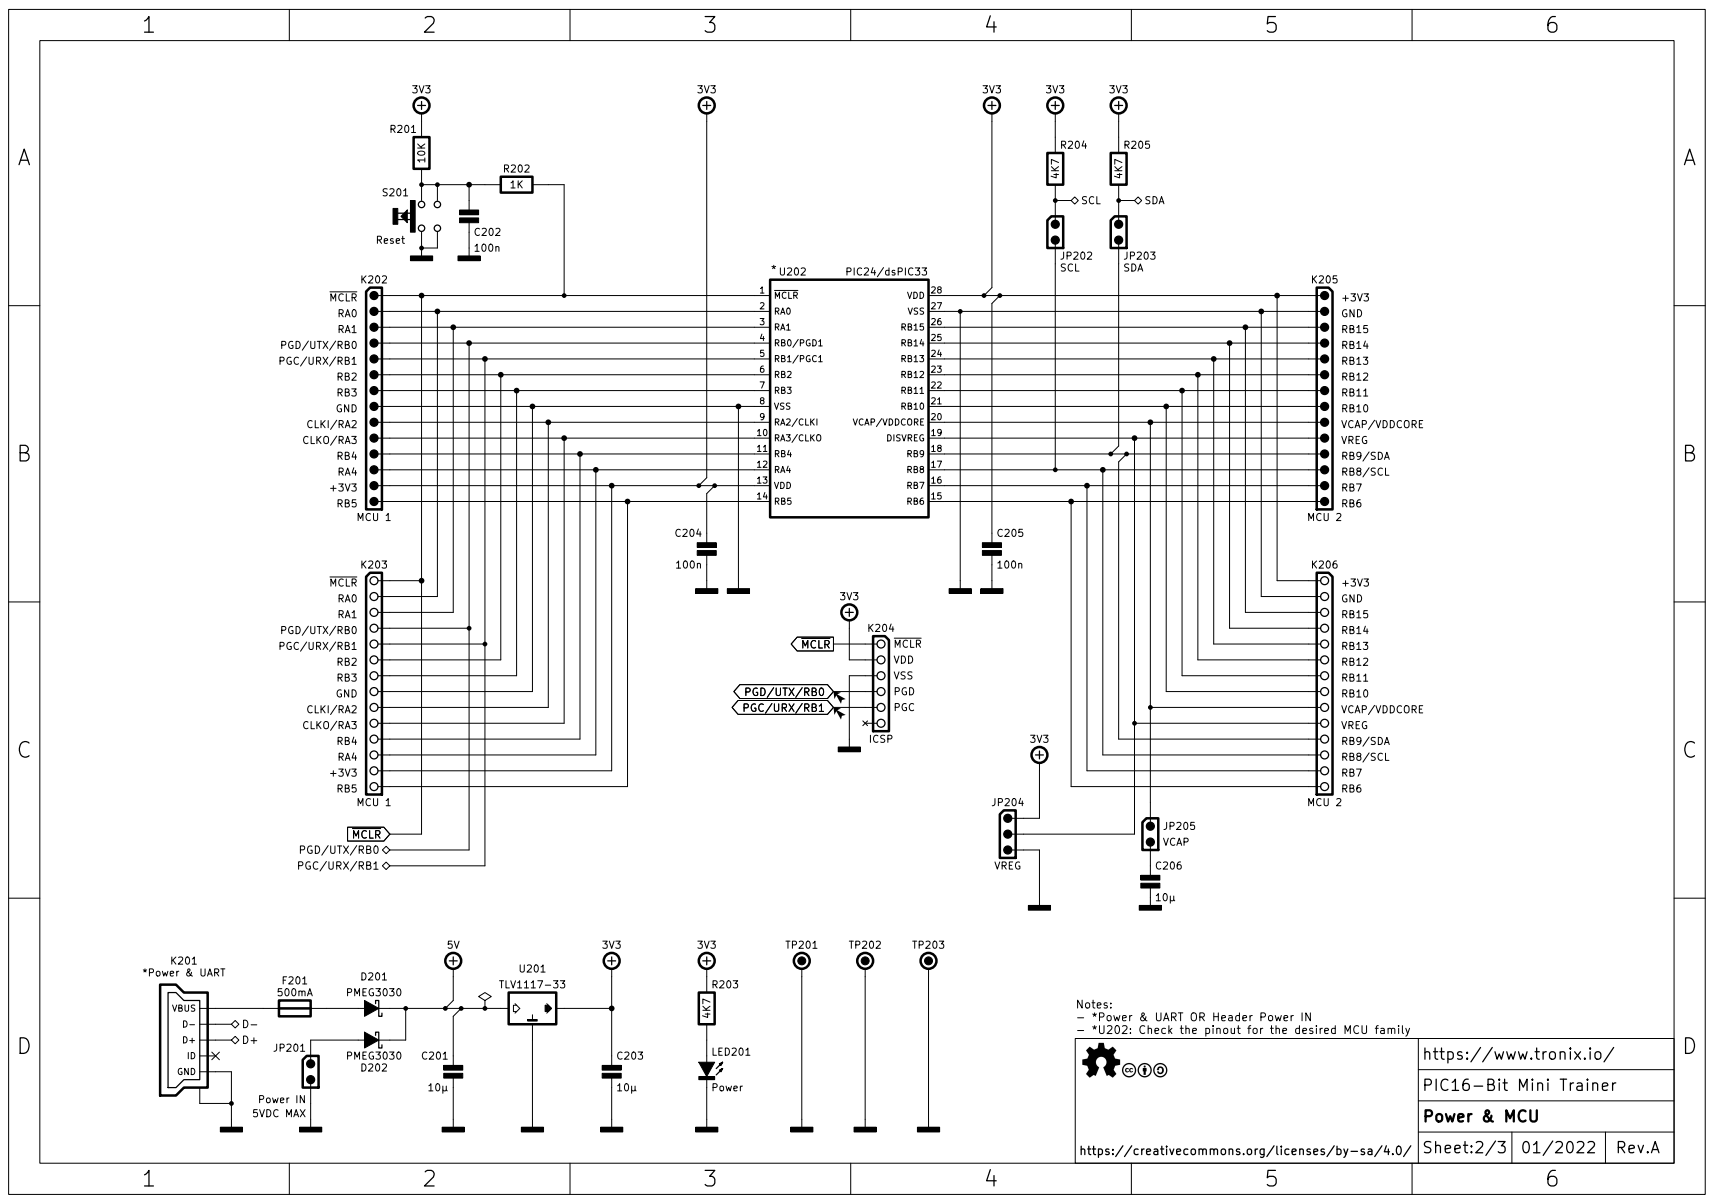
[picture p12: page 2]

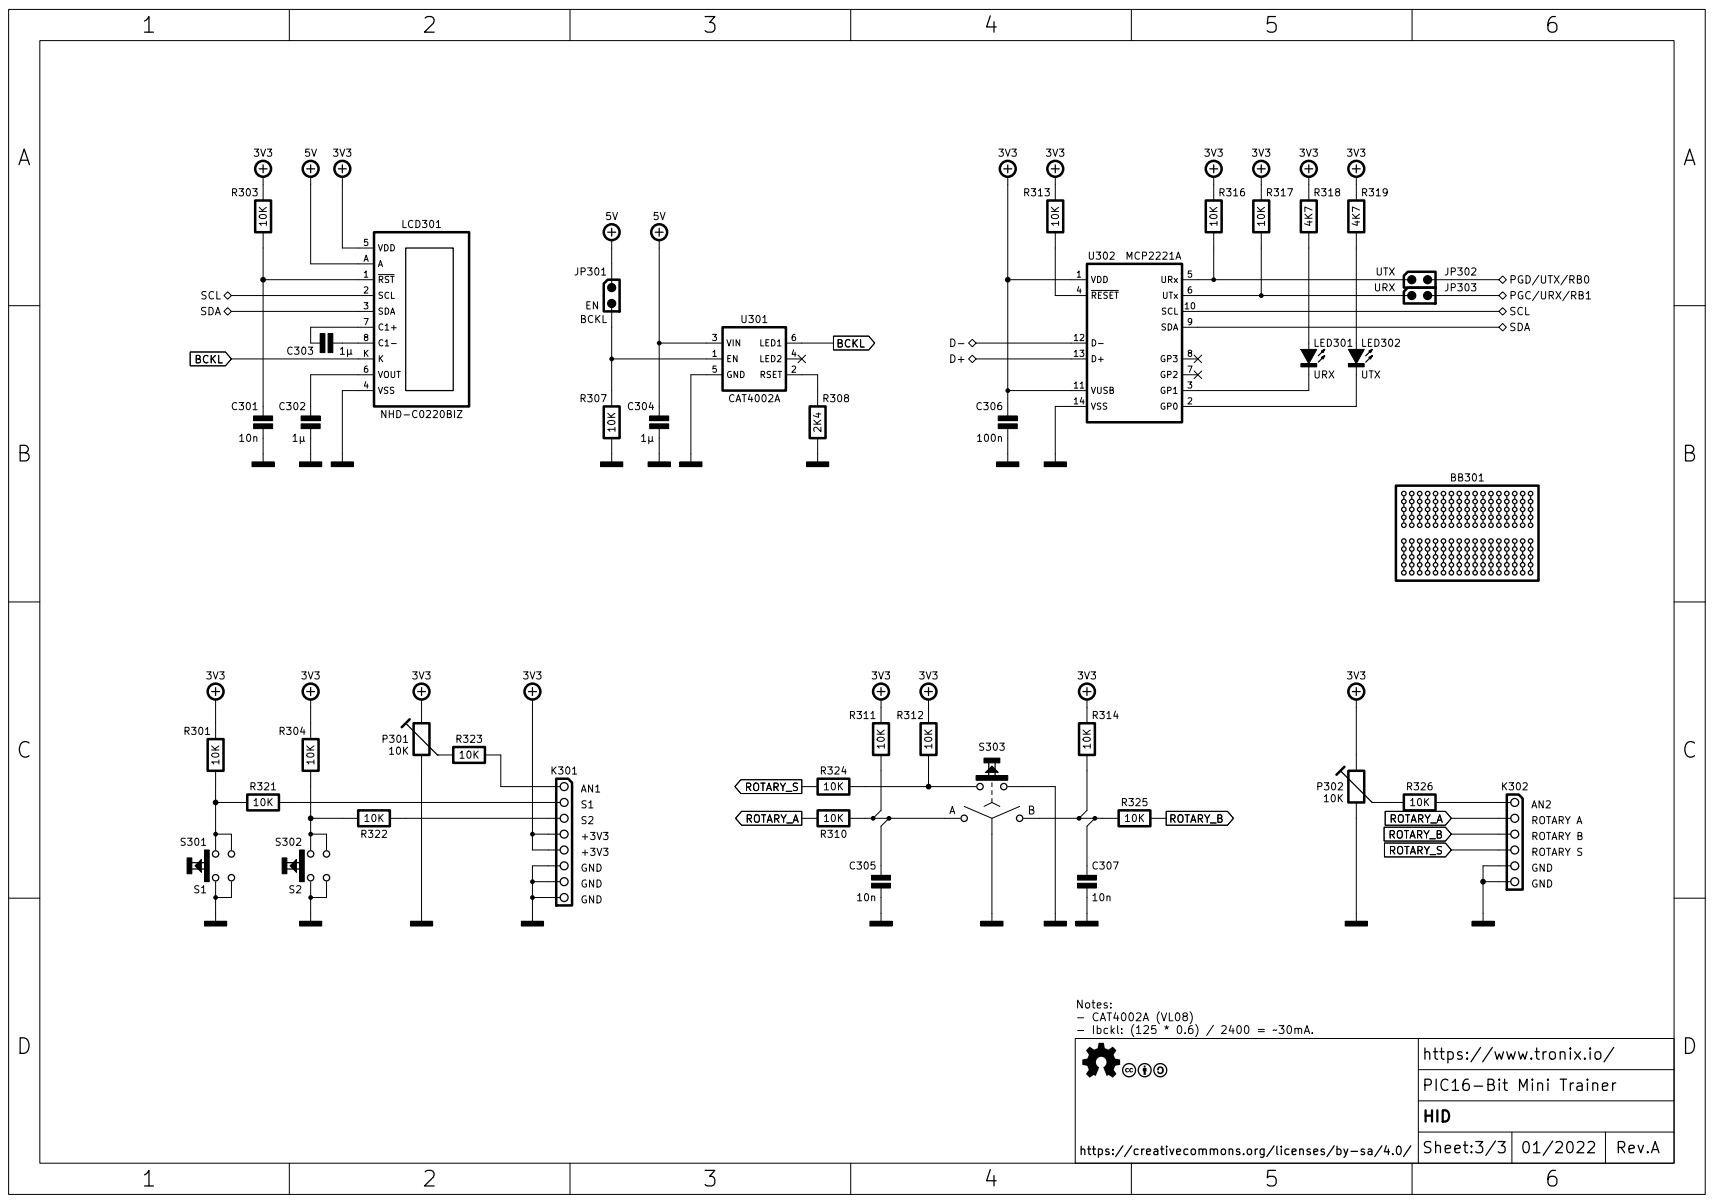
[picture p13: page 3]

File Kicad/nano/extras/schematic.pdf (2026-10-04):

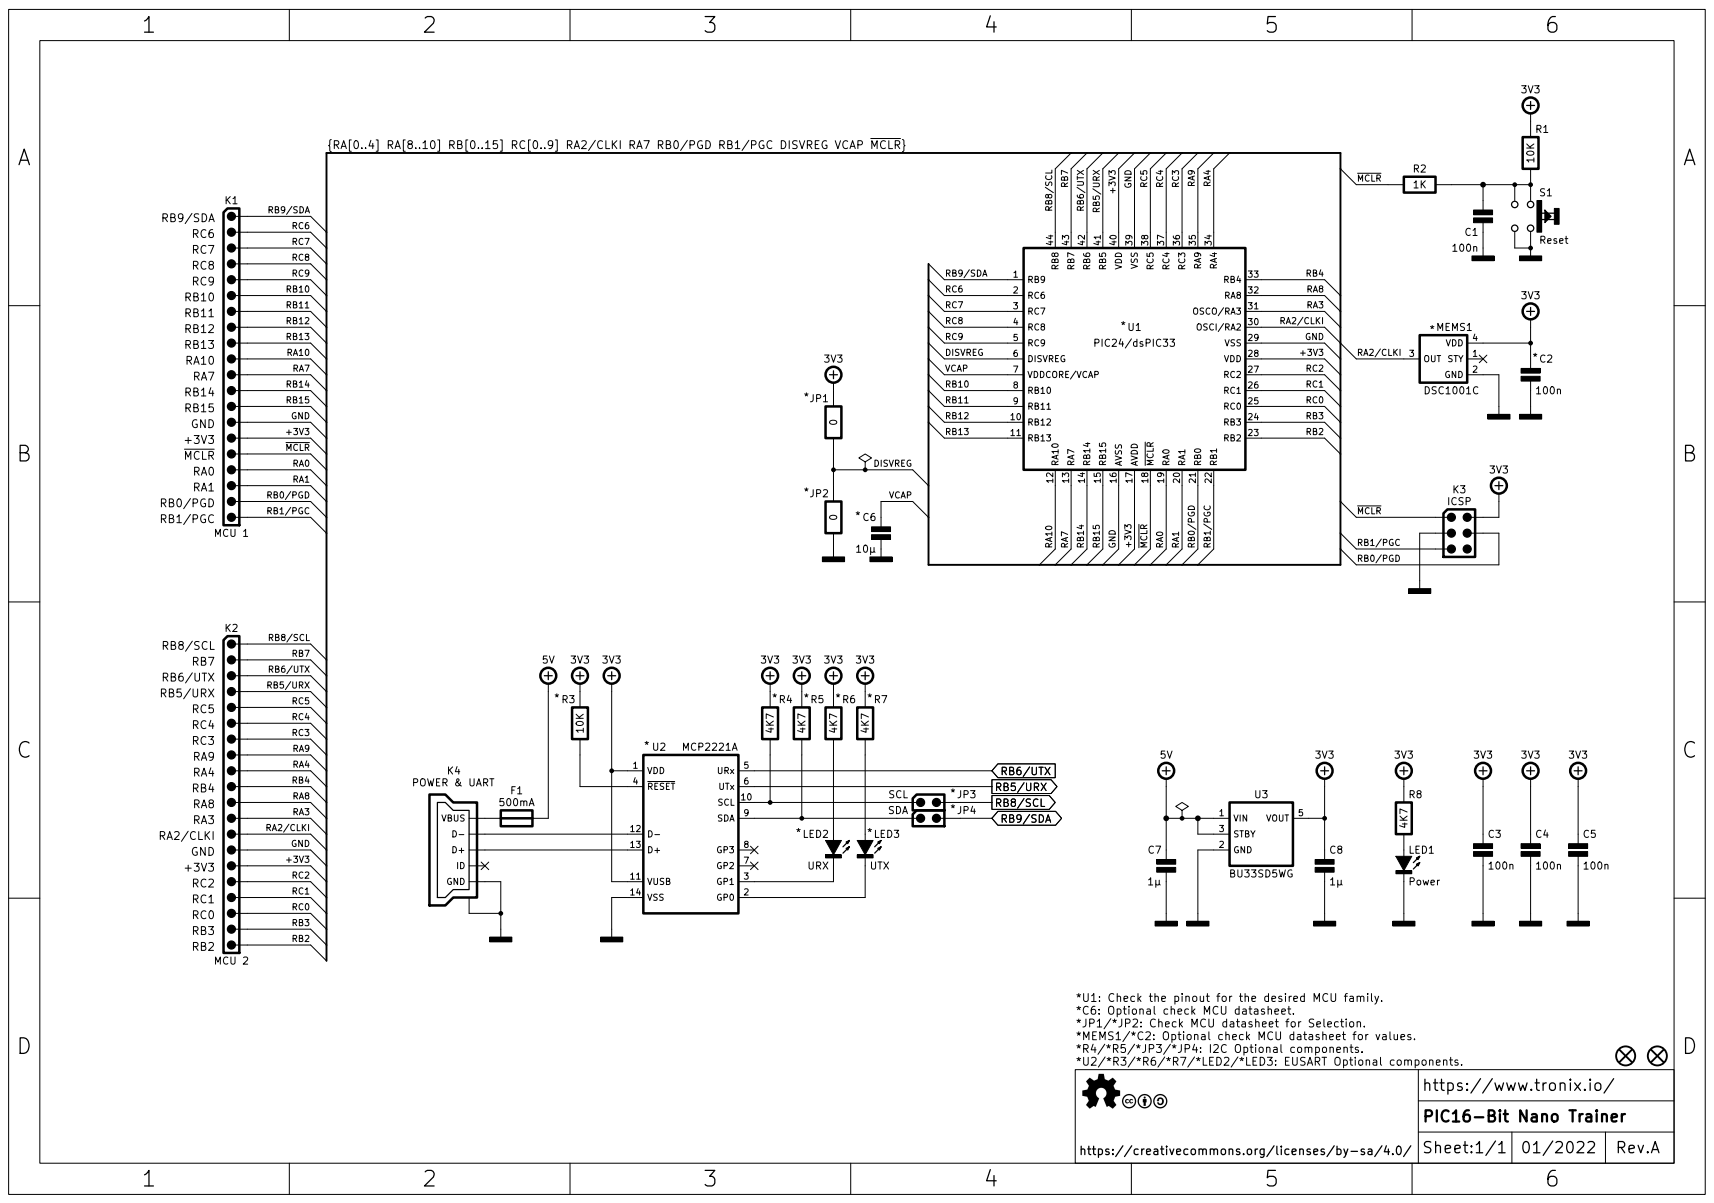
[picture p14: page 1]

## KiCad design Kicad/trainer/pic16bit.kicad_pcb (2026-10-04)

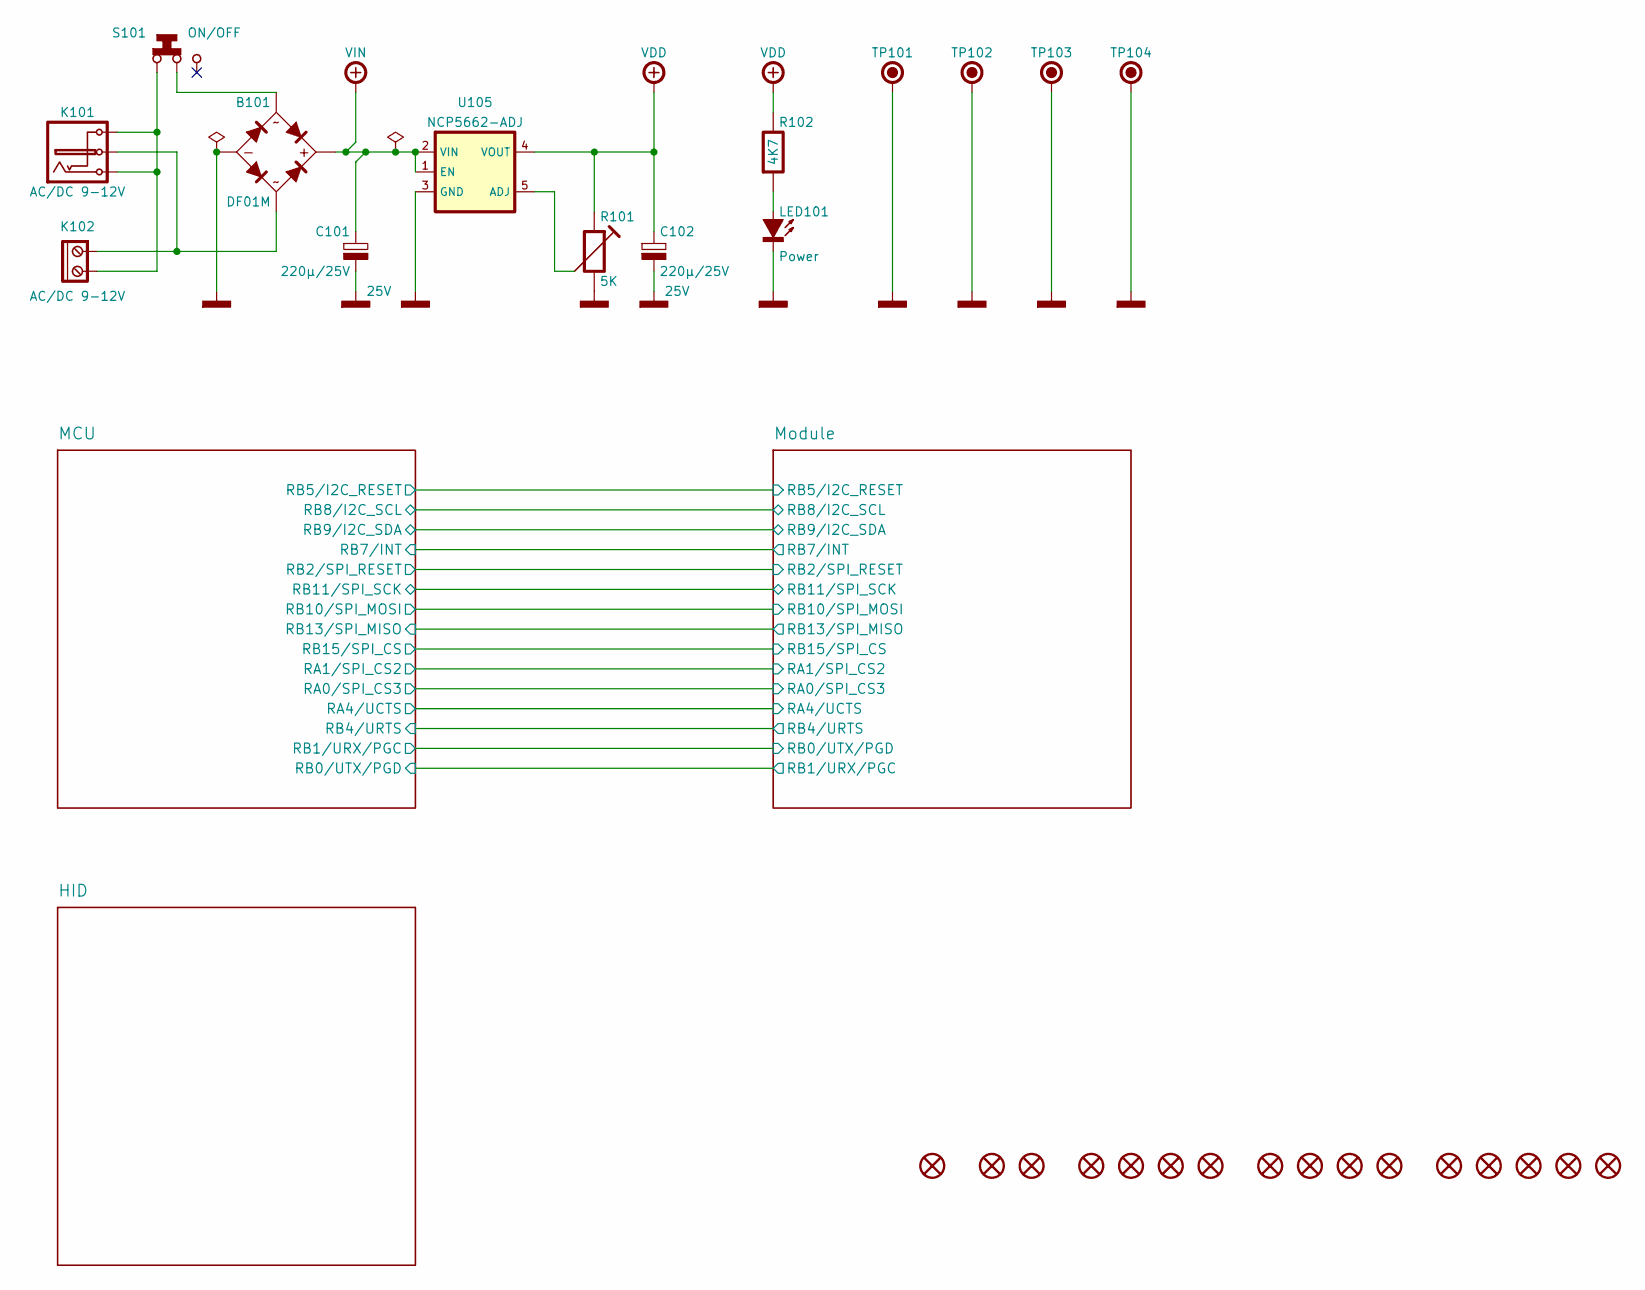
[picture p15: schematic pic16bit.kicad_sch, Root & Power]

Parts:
B101: DF01M; Mouser 512-DF01M
C101, C102: 220µ/25V; CAPACITOR-ELECTROLYTIC-RADIAL-080-115-035; Voltage 25V; Tolerance 20%; Mouser 647-UVZ1E221MPD
H101, H102, H103, H104: HARWIN-JUMPER-0254-14MM-BLACK; HARWIN-M20-7680-7683; Mouser 855-M7682
JP101: HARWIN-JUMPER-0254-06MM-BLACK; HARWIN-M20-7580-7583; Mouser 855-M7582
JP102: HARWIN-JUMPER-0254-06MM-RED; HARWIN-M20-7580-7583; Mouser 855-M7581
K101: AC/DC 9-12V; SAMESKY-PJ-102AH; Mouser 490-PJ-102AH
K102: AC/DC 9-12V; SAMESKY-TB006-508-02BE; Mouser 490-TB006-508-02BE
K103: PE-450-4X6X-BLACK; PE-450-4X6X; Mouser 450-476
LED101: Power; LED-TH-ROUND-05MM; Mouser 604-WP7113ID
R101: 5K; TRIMMER-64W; Tolerance 10%; Mouser 594-64W502
R102: 4K7; RESISTOR-TH-1016; Tolerance 5%; Mouser 594-SFR2500004701JR5
S101: ON/OFF; CK-1101M2; Mouser 611-1101M2S3CQE2
TP101, TP102, TP103: GND; KEYSTONE-5006; Mouser 534-5006
TP104: GND; KEYSTONE-2000-3; Mouser 534-2000-3
U101, U102, U103, U104: KEYSTONE-24283; Mouser 534-24283
U105: NCP5662-ADJ; TO-263-5-TABPIN3; Mouser 863-NCP5662DSADJR4G
X101, X102, X103, X104, X105: 3M-SJ5376; Mouser 517-SJ5376

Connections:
unnamed: B101.3, K101.1, K102.1
unnamed: B101.4, S101.2
unnamed: K101.2, K101.3, K102.2, S101.1
unnamed: LED101.2 (A), R102.2
unnamed: R101.2, U105.5 (ADJ)
POWER-GND: B101.2, C101.2, C102.2, LED101.1 (C), R101.1, TP101.1, TP102.1, TP103.1, TP104.1, U105.3 (GND); also elsewhere on the board
POWER-VDD: C102.1, R101.3, R102.1, U105.4 (VOUT); also elsewhere on the board
POWER-VIN: B101.1, C101.1, U105.1 (EN), U105.2 (VIN); also elsewhere on the board

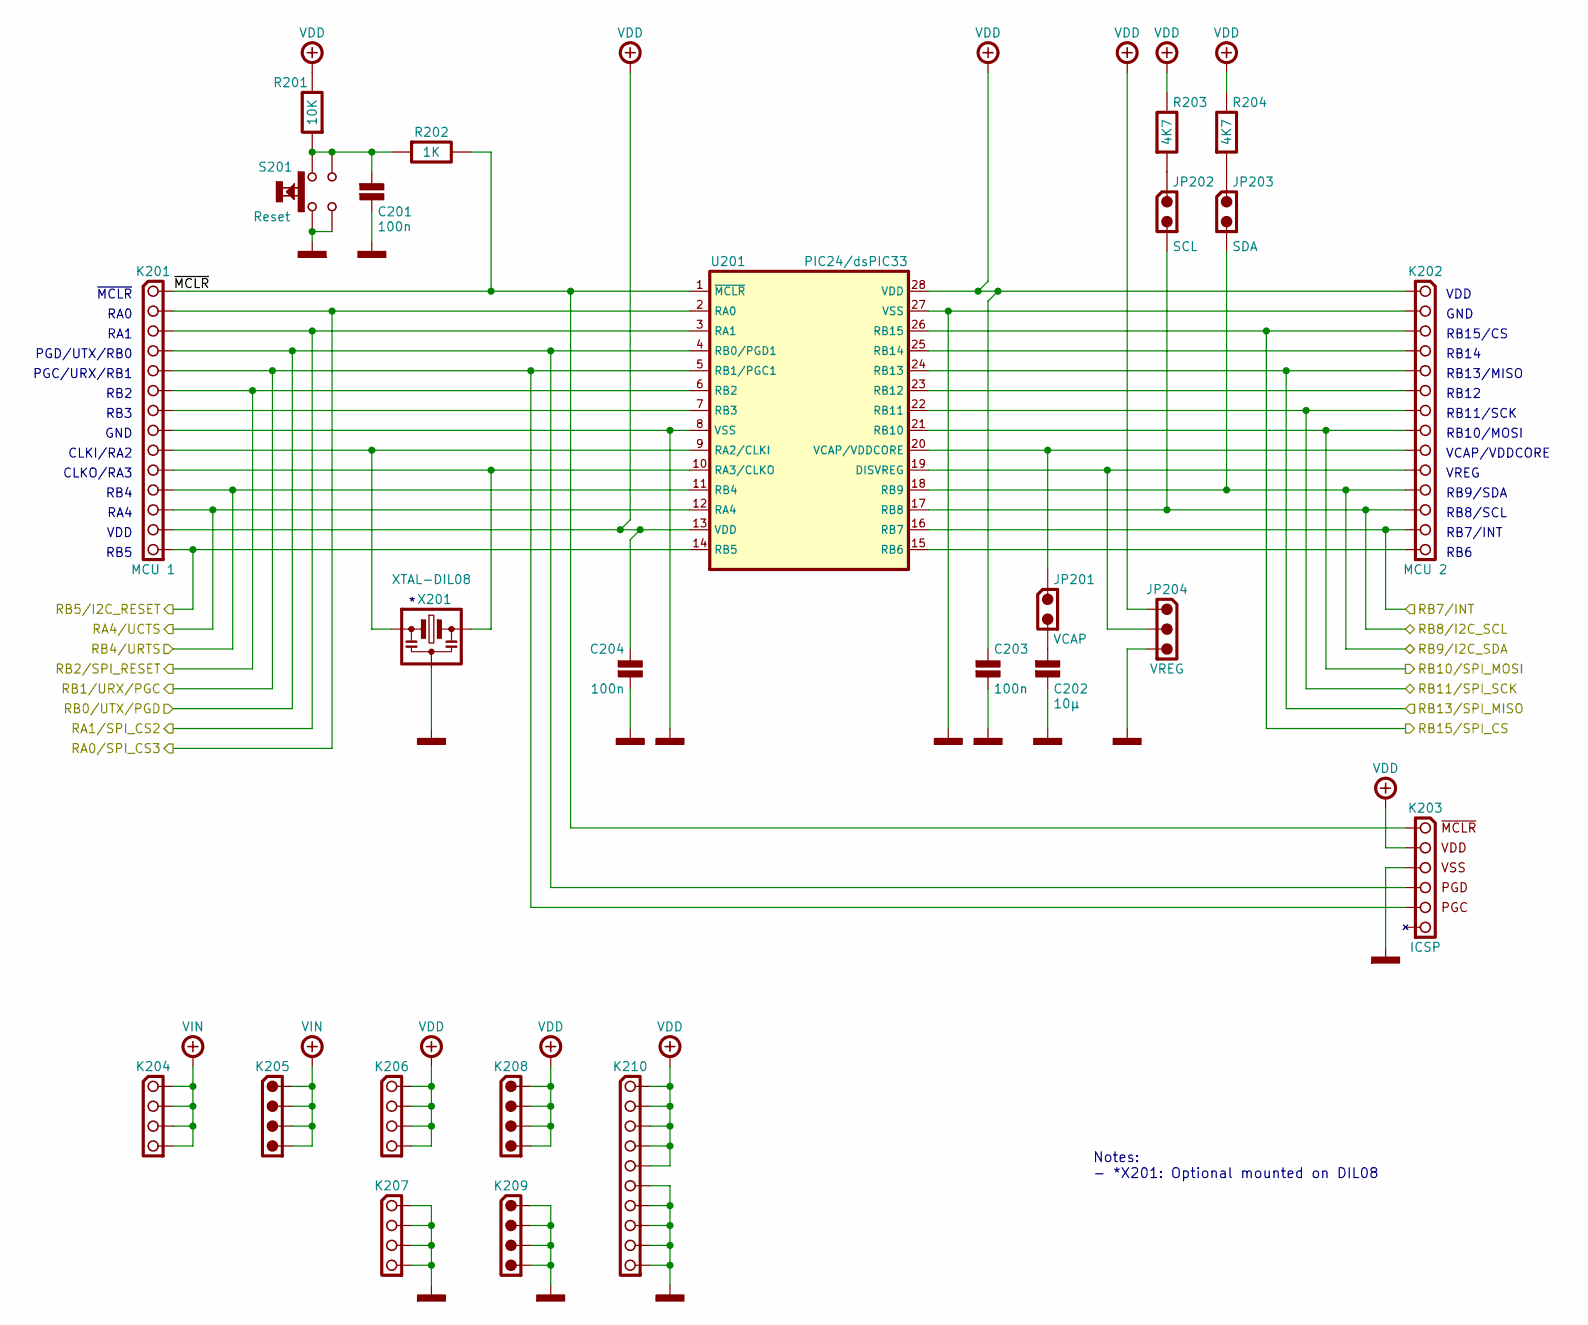
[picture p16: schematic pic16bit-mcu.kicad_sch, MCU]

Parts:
C201, C203, C204: 100n; KEMET-C315; Tolerance 20%; Voltage 50V; Mouser 80-C315C104M5U
C202: 10µ; KEMET-C322; Tolerance 10%; Voltage 25V; Mouser 80-C322C106K3R
JP201: VCAP; HARWIN-M20-975024x; Mouser 855-M20-975024
JP202: SCL; HARWIN-M20-999024x; Mouser 855-M20-999024
JP203: SDA; HARWIN-M20-999024x; Mouser 855-M20-999024
JP204: VREG; HARWIN-M20-975034x; Mouser 855-M20-975034
K201: MCU 1; HARWIN-M20-782144x; Mouser 855-M20-782144
K202: MCU 2; HARWIN-M20-782144x; Mouser 855-M20-782144
K203: ICSP; SAMTEC-SSW-106-02-T-S-RA; Mouser 200-SSW10602TSRA
K204: VIN; HARWIN-M20-782044x; Mouser 855-M20-782044
K205: VIN; HARWIN-M20-999044x; Mouser 855-M20-999044
K206: VDD; HARWIN-M20-782044x; Mouser 855-M20-782044
K207: GND; HARWIN-M20-782044x; Mouser 855-M20-782044
K208: VDD; HARWIN-M20-999044x; Mouser 855-M20-999044
K209: GND; HARWIN-M20-999044x; Mouser 855-M20-999044
K210: VDD & GND; HARWIN-M20-782104x; Mouser 855-M20-782104
R201: 10K; RESISTOR-TH-1016; Tolerance 5%; Mouser 594-SFR2500001002JA5
R202: 1K; RESISTOR-TH-1016; Tolerance 5%; Mouser 594-SFR2500001001JR5
R203, R204: 4K7; RESISTOR-TH-1016; Tolerance 5%; Mouser 594-SFR2500004701JR5
S201: Reset; CK-KSA-TH; Mouser 611-KSA0M911LFT
U201: PIC24/dsPIC33; DIP-28-W762
X201: XTAL-DIL08; DIP-08-W762-SOCKET; Mouser 575-144308

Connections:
/MCU/RA0/SPI_CS3: K201.2, U201.2 (RA0); also elsewhere on the board
/MCU/RA1/SPI_CS2: K201.3, U201.3 (RA1); also elsewhere on the board
/MCU/RA4/UCTS: K201.12, U201.12 (RA4); also elsewhere on the board
/MCU/RB0/UTX/PGD: K201.4, K203.3 (PGD), U201.4 (RB0/PGD1); also elsewhere on the board
/MCU/RB1/URX/PGC: K201.5, K203.2 (PGC), U201.5 (RB1/PGC1); also elsewhere on the board
/MCU/RB2/SPI_RESET: K201.6, U201.6 (RB2); also elsewhere on the board
/MCU/RB4/URTS: K201.11, U201.11 (RB4); also elsewhere on the board
/MCU/RB5/I2C_RESET: K201.14, U201.14 (RB5); also elsewhere on the board
/MCU/RB7/INT: K202.13, U201.16 (RB7); also elsewhere on the board
/MCU/RB8/I2C_SCL: JP202.2, K202.12, U201.17 (RB8); also elsewhere on the board
/MCU/RB9/I2C_SDA: JP203.2, K202.11, U201.18 (RB9); also elsewhere on the board
/MCU/RB10/SPI_MOSI: K202.8, U201.21 (RB10); also elsewhere on the board
/MCU/RB11/SPI_SCK: K202.7, U201.22 (RB11); also elsewhere on the board
/MCU/RB13/SPI_MISO: K202.5, U201.24 (RB13); also elsewhere on the board
/MCU/RB15/SPI_CS: K202.3, U201.26 (RB15); also elsewhere on the board
/MCU/~MCLR: K201.1, K203.6 (~MCLR), R202.1, U201.1 (~MCLR)
unnamed: C201.1, R201.2, R202.2, S201.1, S201.2
unnamed: C202.1, JP201.2
unnamed: JP202.1, R203.2
unnamed: JP203.1, R204.2
unnamed: K201.7, U201.7 (RB3)
unnamed: K201.9, U201.9 (RA2/CLKI), X201.3, X201.4
unnamed: K201.10, U201.10 (RA3/CLKO), X201.5, X201.6
unnamed: K202.4, U201.25 (RB14)
unnamed: K202.6, U201.23 (RB12)
unnamed: JP201.1, K202.9, U201.20 (VCAP/VDDCORE)
unnamed: JP204.2, K202.10, U201.19 (DISVREG)
unnamed: K202.14, U201.15 (RB6)
POWER-GND: C201.2, C202.2, C203.2, C204.2, JP204.3, K201.8, K202.2, K203.4 (GND), K207.1, K207.2, K207.3, K207.4, K209.1, K209.2, K209.3, K209.4, K210.6, K210.7, K210.8, K210.9, K210.10, S201.3, S201.4, U201.8 (VSS), U201.27 (VSS), X201.1, X201.2, X201.7, X201.8; also elsewhere on the board
POWER-VDD: C203.1, C204.1, JP204.1, K201.13, K202.1, K203.5 (VCC), K206.1, K206.2, K206.3, K206.4, K208.1, K208.2, K208.3, K208.4, K210.1, K210.2, K210.3, K210.4, K210.5, R201.1, R203.1, R204.1, U201.13 (VDD), U201.28 (VDD); also elsewhere on the board
POWER-VIN: K204.1, K204.2, K204.3, K204.4, K205.1, K205.2, K205.3, K205.4; also elsewhere on the board

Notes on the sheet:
RB8/SCL
RB2
CLKI/RA2
VCAP/VDDCORE
PGC/URX/RB1
RA0
PGD/UTX/RB0
GND
RB15/CS
Notes: - *X201: Optional mounted on DIL08
VDD
~{MCLR}
CLKO/RA3
VREG
RB14
RB12
RA1
RB13/MISO
RB7/INT
RB3
RB10/MOSI
RB9/SDA
RB6
RA4
RB4
RB11/SCK
RB5

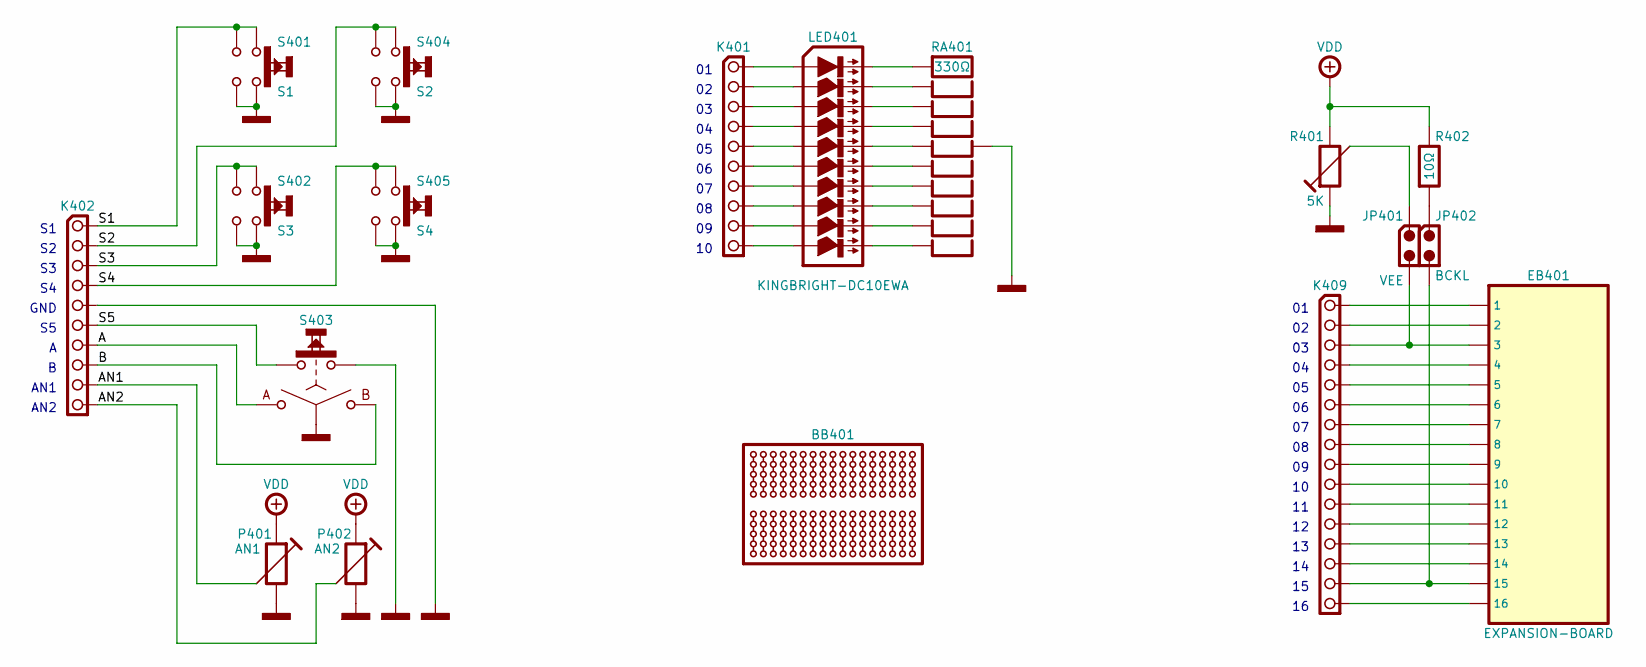
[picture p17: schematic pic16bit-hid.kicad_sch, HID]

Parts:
BB401: BREADBOARD-170; Mouser 854-BB170
EB401: EXPANSION-BOARD; TRONIXIO-EXPANSION-BOARD; Mouser 200-CES11601TS
JP401: VEE; HARWIN-M20-999024x; Mouser 855-M20-999024
JP402: BCKL; HARWIN-M20-999024x; Mouser 855-M20-999024
K401: LED ARRAY; HARWIN-M20-782104x; Mouser 855-M20-782104
K402: SWITCH, ENCODER & ANALOG; HARWIN-M20-782104x; Mouser 855-M20-782104
K409: EXPANSION BOARD; HARWIN-M20-782164x; Mouser 855-M20-782164
LED401: KINGBRIGHT-DC10EWA; KINGBRIGHT-DC; Mouser 604-DC-10EWA
P401: AN1; PIHER-PT10MV; Tolerance 20%; Mouser 531-PT10MV-10K
P402: AN2; PIHER-PT10MV; Tolerance 20%; Mouser 531-PT10MV-10K
R401: 5K; PIHER-PT10MV; Tolerance 20%; Mouser 531-PT10LV-5K
R402: 10Ω; RESISTOR-TH-1016; Tolerance 5%; Mouser 594-5043EM10R00J
RA401: 330Ω; BOURNS-4611X; Tolerance 2%; Mouser 652-4611X-1LF-330
S401: S1; CK-KSA-TH; Mouser 611-KSA0M911LFT
S402: S3; CK-KSA-TH; Mouser 611-KSA0M911LFT
S403: BOURNS-PEC12R-24DENTS; BOURNS-PEC12R-SWITCH; Mouser 652-PEC12R-4215F-S24
S404: S2; CK-KSA-TH; Mouser 611-KSA0M911LFT
S405: S4; CK-KSA-TH; Mouser 611-KSA0M911LFT

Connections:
/HID/A: K402.7, S403.1 (A)
/HID/AN1: K402.9, P401.2
/HID/AN2: K402.10, P402.2
/HID/B: K402.8, S403.3 (B)
/HID/S1: K402.1, S401.1, S401.2
/HID/S2: K402.2, S404.1, S404.2
/HID/S3: K402.3, S402.1, S402.2
/HID/S4: K402.4, S405.1, S405.2
/HID/S5: K402.6, S403.5
unnamed: JP401.1, R401.2
unnamed: JP402.1, R402.2
unnamed: K401.1, LED401.1 (A1)
unnamed: K401.2, LED401.2 (A2)
unnamed: K401.3, LED401.3 (A3)
unnamed: K401.4, LED401.4 (A4)
unnamed: K401.5, LED401.5 (A5)
unnamed: K401.6, LED401.6 (A6)
unnamed: K401.7, LED401.7 (A7)
unnamed: K401.8, LED401.8 (A8)
unnamed: K401.9, LED401.9 (A9)
unnamed: K401.10, LED401.10 (A10)
unnamed: EB401.1, K409.1
unnamed: EB401.2, K409.2
unnamed: EB401.3, JP401.2, K409.3
unnamed: EB401.4, K409.4
unnamed: EB401.5, K409.5
unnamed: EB401.6, K409.6
unnamed: EB401.7, K409.7
unnamed: EB401.8, K409.8
unnamed: EB401.9, K409.9
unnamed: EB401.10, K409.10
unnamed: EB401.11, K409.11
unnamed: EB401.12, K409.12
unnamed: EB401.13, K409.13
unnamed: EB401.14, K409.14
unnamed: EB401.15, JP402.2, K409.15
unnamed: EB401.16, K409.16
unnamed: LED401.20 (C1), RA401.2
unnamed: LED401.19 (C2), RA401.3
unnamed: LED401.18 (C3), RA401.4
unnamed: LED401.17 (C4), RA401.5
unnamed: LED401.16 (C5), RA401.6
unnamed: LED401.15 (C6), RA401.7
unnamed: LED401.14 (C7), RA401.8
unnamed: LED401.13 (C8), RA401.9
unnamed: LED401.12 (C9), RA401.10
unnamed: LED401.11 (C10), RA401.11
POWER-GND: K402.5, P401.1, P402.1, R401.3, RA401.1, S401.3, S401.4, S402.3, S402.4, S403.2 (C), S403.4, S404.3, S404.4, S405.3, S405.4; also elsewhere on the board
POWER-VDD: P401.3, P402.3, R401.1, R402.1; also elsewhere on the board

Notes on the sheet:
AN2
GND
AN1

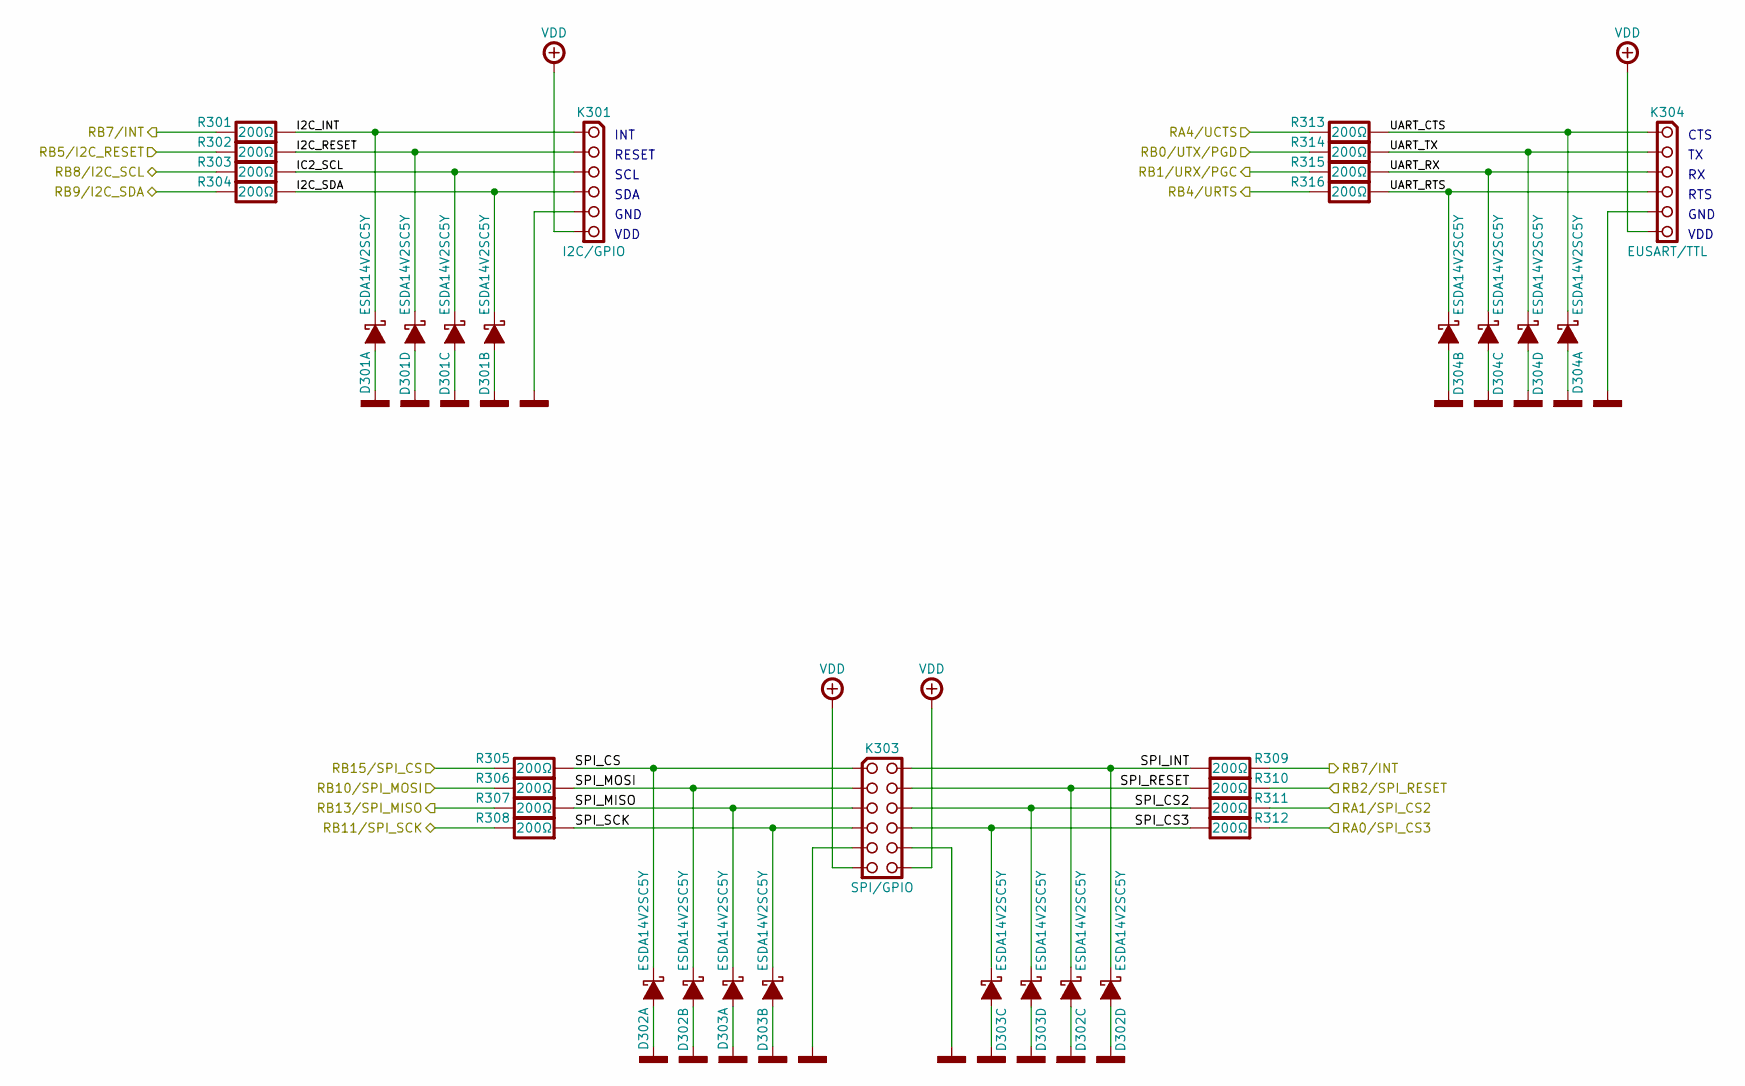
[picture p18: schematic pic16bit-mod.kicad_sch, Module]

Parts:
D301, D302, D303, D304: ESDA14V2SC5Y; SOT-23-5; Mouser 511-ESDA14V2SC5Y
K301: I2C/GPIO; SAMTEC-SSW-106-02-T-S-RA; Mouser 200-SSW10603TSRA
K303: SPI/GPIO; SAMTEC-SSW-106-02-T-D-RA; Mouser 200-SSW10602TDRA
K304: EUSART/TTL; SAMTEC-SSW-106-02-T-S-RA; Mouser 200-SSW10603TSRA
R301, R302, R303, R304, R305, R306, R307, R308, R309, R310, R311, R312, R313, R314, R315, R316: 200Ω; RESISTOR-SMD-1206; Tolerance 5%; Mouser 660-RK73B2BTTDD201J

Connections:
/MCU/RA0/SPI_CS3: R312.2; also elsewhere on the board
/MCU/RA1/SPI_CS2: R311.2; also elsewhere on the board
/MCU/RA4/UCTS: R313.1; also elsewhere on the board
/MCU/RB0/UTX/PGD: R315.1; also elsewhere on the board
/MCU/RB1/URX/PGC: R314.1; also elsewhere on the board
/MCU/RB2/SPI_RESET: R310.2; also elsewhere on the board
/MCU/RB4/URTS: R316.1; also elsewhere on the board
/MCU/RB5/I2C_RESET: R302.1; also elsewhere on the board
/MCU/RB7/INT: R301.1, R309.2; also elsewhere on the board
/MCU/RB8/I2C_SCL: R303.1; also elsewhere on the board
/MCU/RB9/I2C_SDA: R304.1; also elsewhere on the board
/MCU/RB10/SPI_MOSI: R306.1; also elsewhere on the board
/MCU/RB11/SPI_SCK: R308.1; also elsewhere on the board
/MCU/RB13/SPI_MISO: R307.1; also elsewhere on the board
/MCU/RB15/SPI_CS: R305.1; also elsewhere on the board
/Module/I2C_INT: D301.1 (C), K301.1, R301.2
/Module/I2C_RESET: D301.5 (C), K301.2, R302.2
/Module/I2C_SDA: D301.3 (C), K301.4, R304.2
/Module/IC2_SCL: D301.4 (C), K301.3, R303.2
/Module/SPI_CS: D302.1 (C), K303.1, R305.2
/Module/SPI_CS2: D303.5 (C), K303.6, R311.1
/Module/SPI_CS3: D303.4 (C), K303.8, R312.1
/Module/SPI_INT: D302.5 (C), K303.2, R309.1
/Module/SPI_MISO: D303.1 (C), K303.5, R307.2
/Module/SPI_MOSI: D302.3 (C), K303.3, R306.2
/Module/SPI_RESET: D302.4 (C), K303.4, R310.1
/Module/SPI_SCK: D303.3 (C), K303.7, R308.2
/Module/UART_CTS: D304.1 (C), K304.1, R313.2
/Module/UART_RTS: D304.3 (C), K304.4, R316.2
/Module/UART_RX: D304.4 (C), K304.3, R315.2
/Module/UART_TX: D304.5 (C), K304.2, R314.2
POWER-GND: D301.2 (A), D302.2 (A), D303.2 (A), D304.2 (A), K301.5, K303.9, K303.10, K304.5; also elsewhere on the board
POWER-VDD: K301.6, K303.11, K303.12, K304.6; also elsewhere on the board

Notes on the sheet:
INT
VDD
SCL
GND
SDA
CTS
RESET
RTS

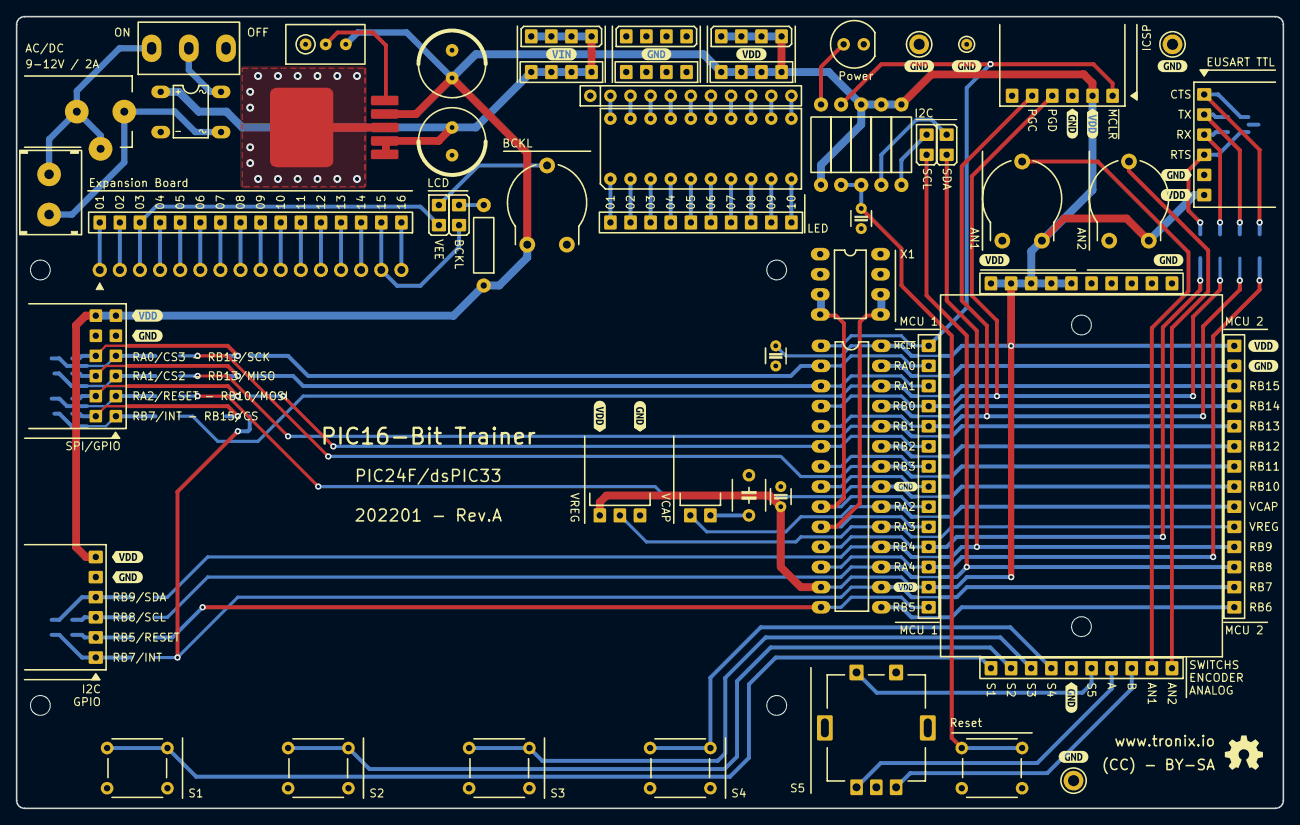
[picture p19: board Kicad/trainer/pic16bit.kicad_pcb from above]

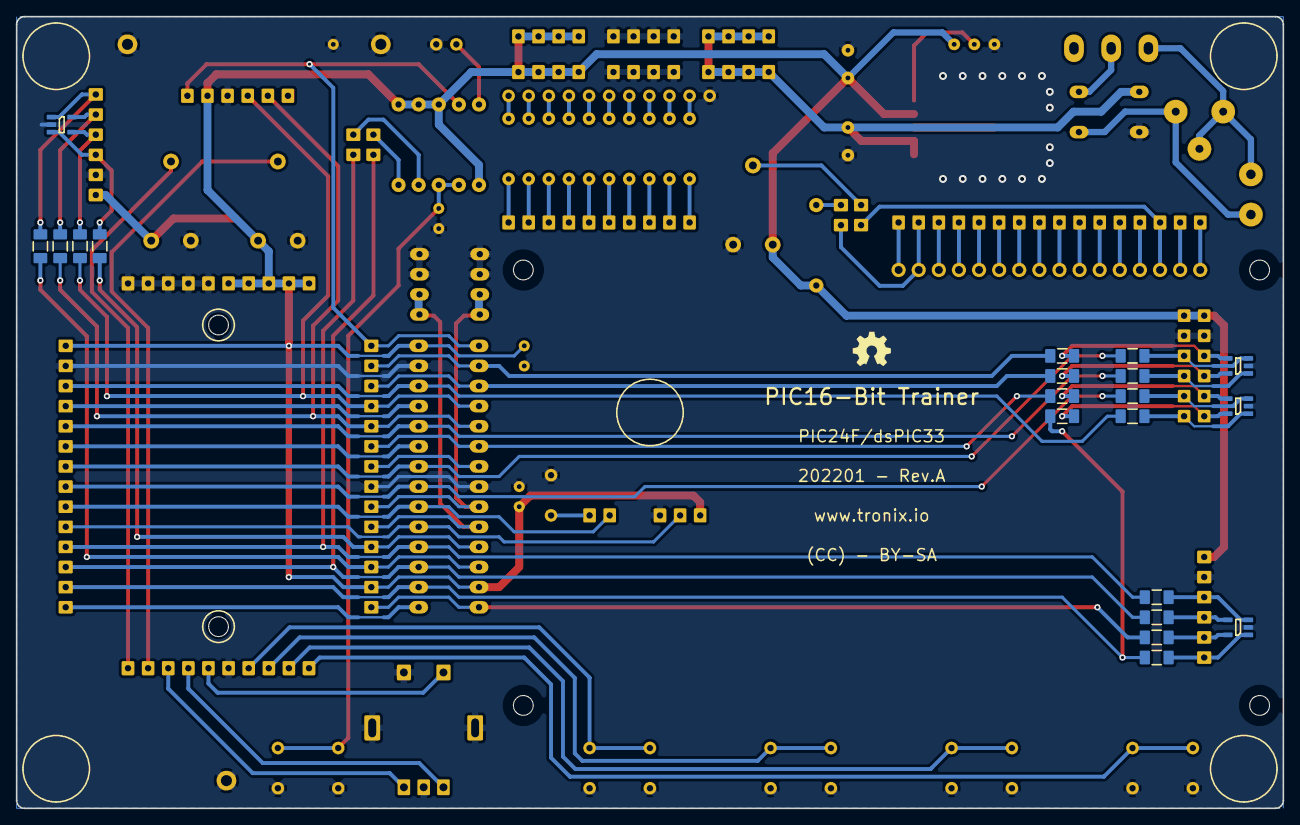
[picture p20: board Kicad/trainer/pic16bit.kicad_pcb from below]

Board: 2 copper layers, 160.0 x 100.0 mm, 120 parts (25 on the bottom side), 99 nets.

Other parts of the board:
kibuzzard-62A778D1: G***; kibuzzard-62A778D1
kibuzzard-62A778F0: G***; kibuzzard-62A778F0
kibuzzard-65F6F3D4: G***; kibuzzard-65F6F3D4
kibuzzard-65F6F3E0: G***; kibuzzard-65F6F3E0
kibuzzard-65F6F3EC: G***; kibuzzard-65F6F3EC
kibuzzard-65F6F3F9: G***; kibuzzard-65F6F3F9
kibuzzard-65F6F4AB: G***; kibuzzard-65F6F4AB
kibuzzard-65F6F4B8: G***; kibuzzard-65F6F4B8
kibuzzard-65F6F4C9: G***; kibuzzard-65F6F4C9
kibuzzard-65F6F4DA: G***; kibuzzard-65F6F4DA
kibuzzard-65F6F4F1: G***; kibuzzard-65F6F4F1
kibuzzard-65F6F42E: G***; kibuzzard-65F6F42E
kibuzzard-65F6F45D: G***; kibuzzard-65F6F45D
kibuzzard-65F6F46A: G***; kibuzzard-65F6F46A
kibuzzard-65F6F48D: G***; kibuzzard-65F6F48D
kibuzzard-65F6F405: G***; kibuzzard-65F6F405
kibuzzard-65F6F414: G***; kibuzzard-65F6F414
kibuzzard-65F6F420: G***; kibuzzard-65F6F420
kibuzzard-65F6F438: G***; kibuzzard-65F6F438
kibuzzard-65F6F442: G***; kibuzzard-65F6F442
kibuzzard-65F6F450: G***; kibuzzard-65F6F450
kibuzzard-65F6F480: G***; kibuzzard-65F6F480
kibuzzard-65F6F499: G***; kibuzzard-65F6F499
kibuzzard-65F6F500: G***; kibuzzard-65F6F500

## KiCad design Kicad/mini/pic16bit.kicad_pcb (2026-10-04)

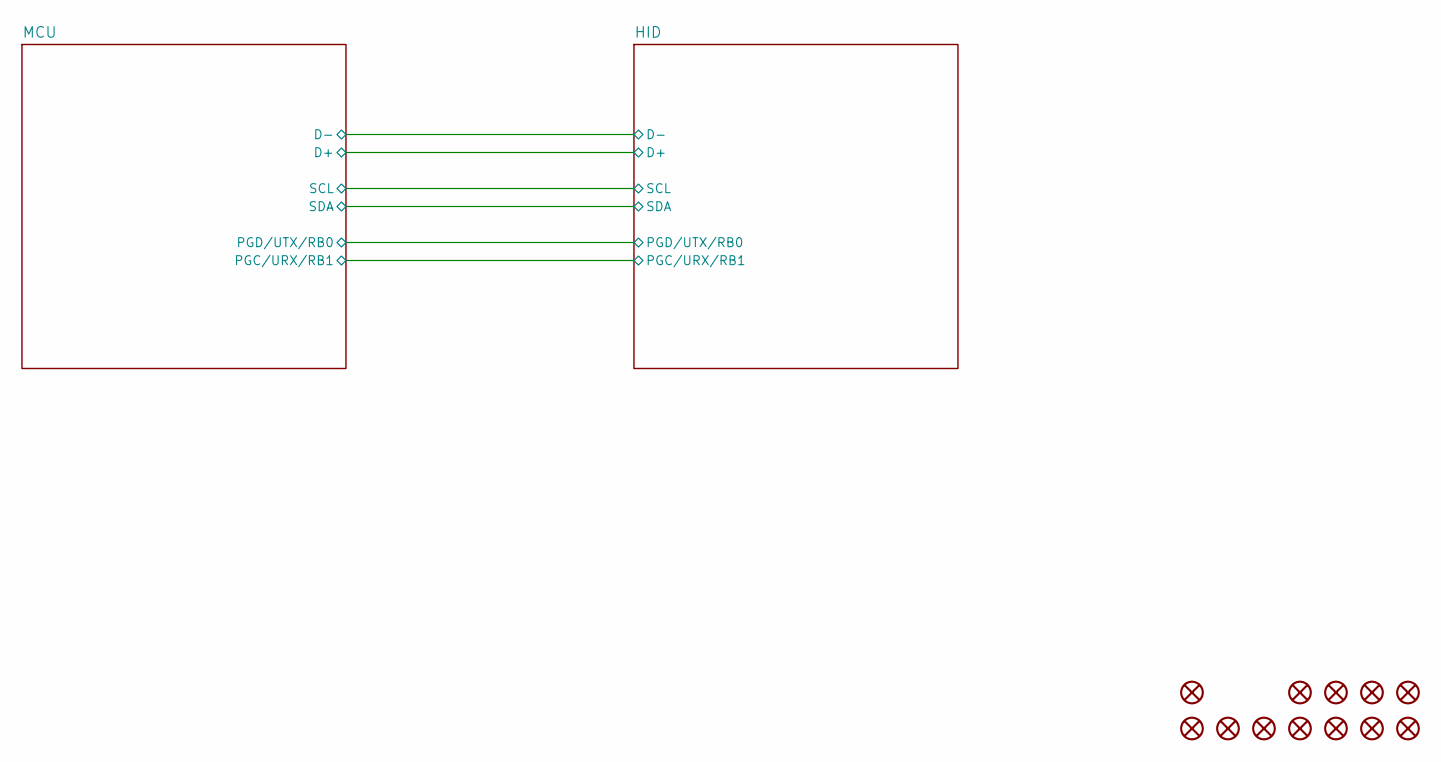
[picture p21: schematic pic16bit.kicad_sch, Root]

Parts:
H101, H102, H103, H104: KEYSTONE-9055; Mouser 534-9055
JP101, JP102, JP103, JP104, JP105, JP106, JP107: HARWIN-JUMPER-0254-06MM-BLACK; HARWIN-M20-7580-7583; Mouser 855-M7582
K101: PE-450-4X6X-BLACK; PE-450-4X6X; Mouser 450-476

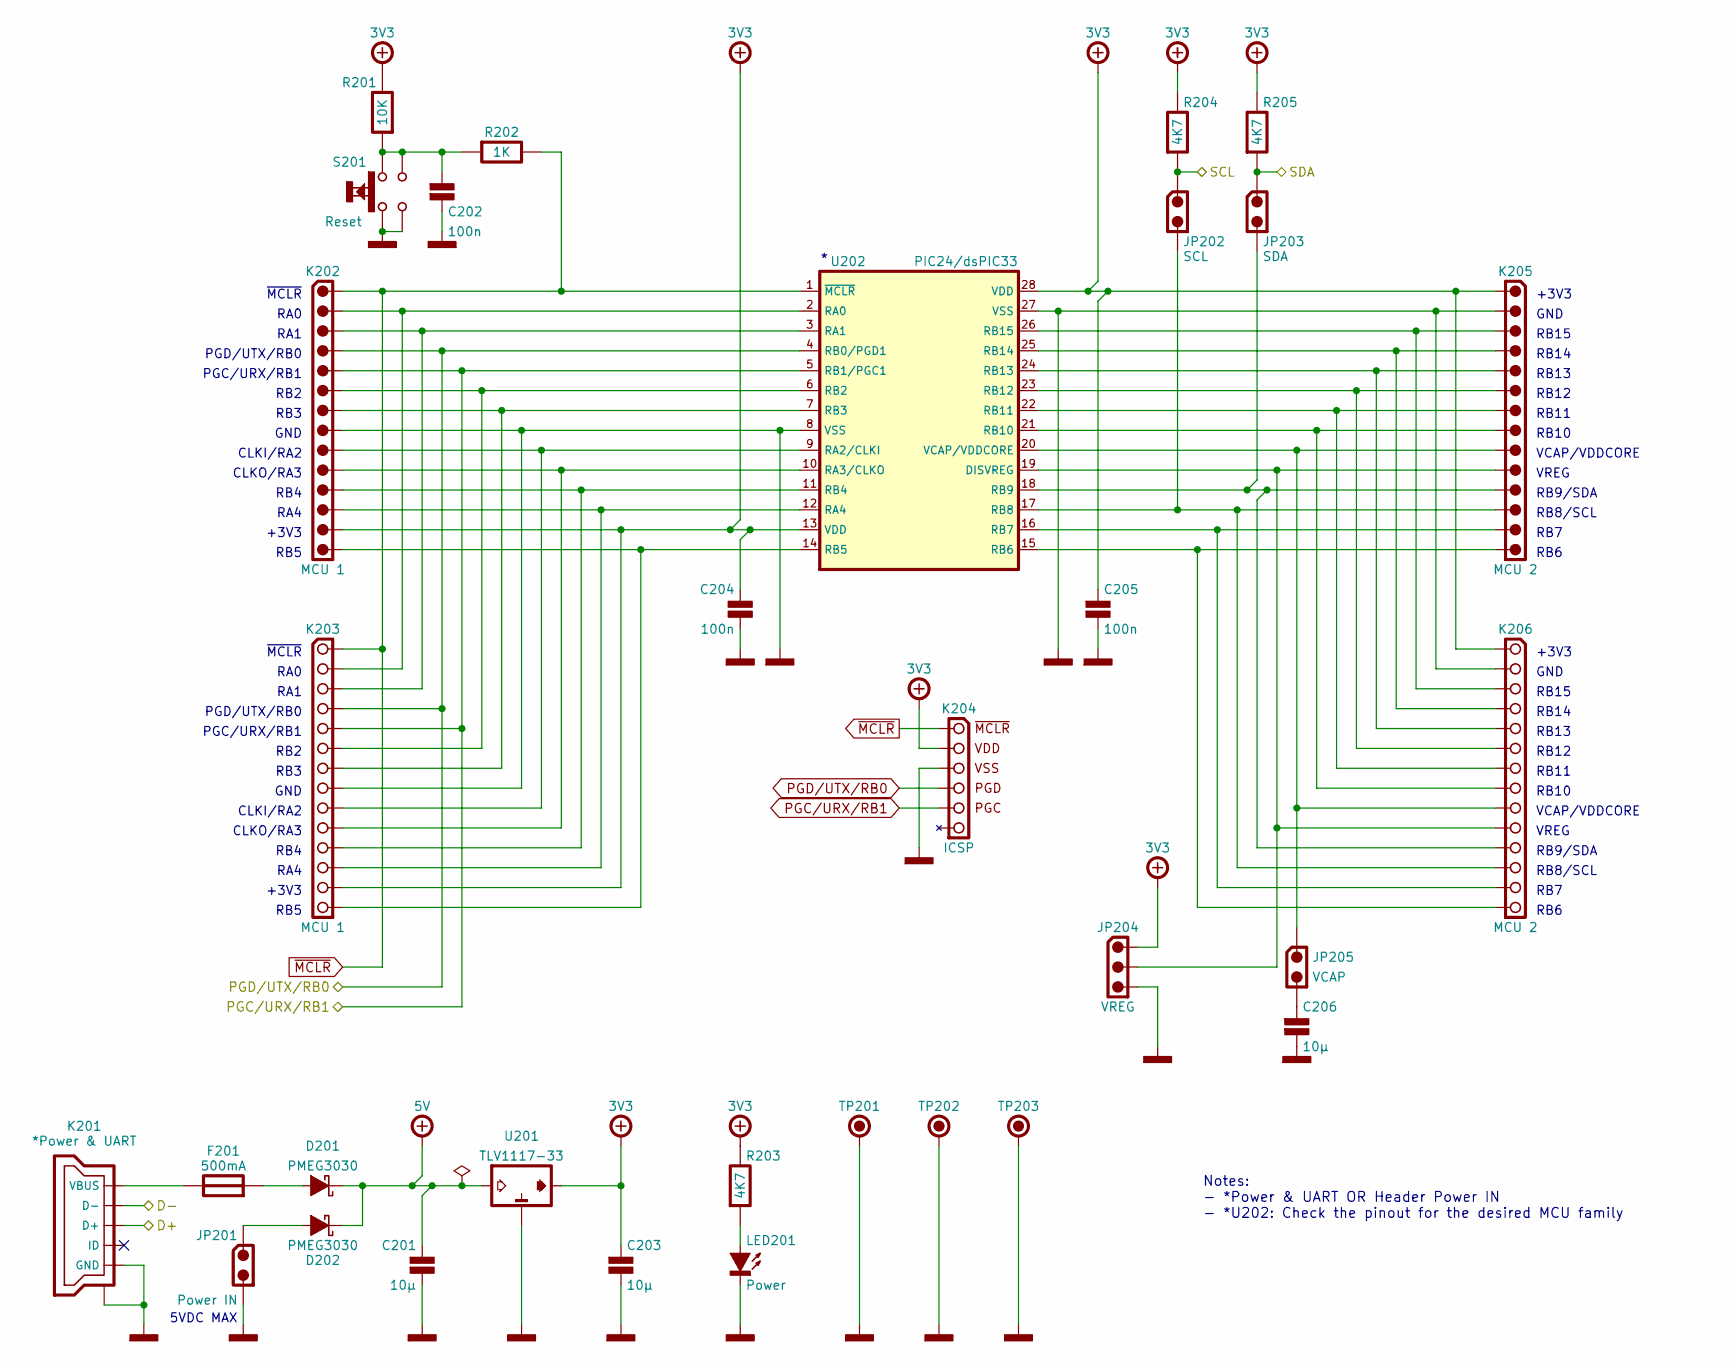
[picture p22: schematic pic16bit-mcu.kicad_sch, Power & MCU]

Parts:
C201, C203, C206: 10µ; CAPACITOR-SMD-1206; Voltage 25V; Tolerance 5%; Mouser 80-C1206C106J3R
C202, C204, C205: 100n; CAPACITOR-SMD-1206; Voltage 50V; Tolerance 5%; Mouser 80-C1206C104J5R
D201, D202: PMEG3030; SOD-128; Part Marking A5; Mouser 771-PMEG3030EP115
F201: 500mA; FUSE-SMD-1206; Mouser 652-MF-NSMF050-2
JP201: Power IN; HARWIN-M20-999024x; Mouser 855-M20-999024
JP202: SCL; HARWIN-M20-999024x; Mouser 855-M20-999024
JP203: SDA; HARWIN-M20-999024x; Mouser 855-M20-999024
JP204: VREG; HARWIN-M20-999034x; Mouser 855-M20-999034
JP205: VCAP; HARWIN-M20-999024x; Mouser 855-M20-999024
K201: *Power & UART; USB-TYPE-B-MICRO-TH; Mouser 649-10118193-0001LF
K202: MCU 1; HARWIN-M20-999144x; Mouser 855-M20-999144
K203: MCU 1; HARWIN-M20-782144x; Mouser 855-M20-782144
K204: ICSP; SAMTEC-SSW-106-02-T-S-RA; Mouser 200-SSW10602TSRA
K205: MCU 2; HARWIN-M20-999144x; Mouser 855-M20-999144
K206: MCU 2; HARWIN-M20-782144x; Mouser 855-M20-782144
LED201: Power; LED-SMD-1206; Mouser 604-APT3216LVBCD
R201: 10K; RESISTOR-SMD-1206; Tolerance 5%; Mouser 660-RK73B2BTTDD103J
R202: 1K; RESISTOR-SMD-1206; Tolerance 5%; Mouser 660-RK73B2BTTDD102J
R203, R204, R205: 4K7; RESISTOR-SMD-1206; Tolerance 5%; Mouser 660-RK73B2BTTDD472J
S201: Reset; ALPS-SKRPAC; Mouser 688-SKRPACE010
TP201, TP202: KEYSTONE-5006; Mouser 534-5006
TP203: KEYSTONE-2000-3; Mouser 534-2000-3
U201: TLV1117-33; SOT-223-3-TABPIN2; Mouser 595-TLV1117-33CDC
U202: PIC24/dsPIC33; DIP-28-W762; Mouser 579-P24FJ64GA102ISP

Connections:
/HID/D+: K201.3 (D+); also elsewhere on the board
/HID/D-: K201.2 (D-); also elsewhere on the board
/HID/SCL: JP202.1, R204.2; also elsewhere on the board
/HID/SDA: JP203.1, R205.2; also elsewhere on the board
unnamed: C202.1, R201.2, R202.2, S201.1, S201.2
unnamed: C206.1, JP205.2
unnamed: D201.2 (A), F201.2
unnamed: D202.2 (A), JP201.1
unnamed: F201.1, K201.1 (VBUS)
unnamed: K202.2, K203.2, U202.2 (RA0)
unnamed: K202.3, K203.3, U202.3 (RA1)
unnamed: K202.6, K203.6, U202.6 (RB2)
unnamed: K202.7, K203.7, U202.7 (RB3)
unnamed: K202.9, K203.9, U202.9 (RA2/CLKI)
unnamed: K202.10, K203.10, U202.10 (RA3/CLKO)
unnamed: K202.11, K203.11, U202.11 (RB4)
unnamed: K202.12, K203.12, U202.12 (RA4)
unnamed: K202.14, K203.14, U202.14 (RB5)
unnamed: K205.3, K206.3, U202.26 (RB15)
unnamed: K205.4, K206.4, U202.25 (RB14)
unnamed: K205.5, K206.5, U202.24 (RB13)
unnamed: K205.6, K206.6, U202.23 (RB12)
unnamed: K205.7, K206.7, U202.22 (RB11)
unnamed: K205.8, K206.8, U202.21 (RB10)
unnamed: JP205.1, K205.9, K206.9, U202.20 (VCAP/VDDCORE)
unnamed: JP204.2, K205.10, K206.10, U202.19 (DISVREG)
unnamed: JP203.2, K205.11, K206.11, U202.18 (RB9)
unnamed: JP202.2, K205.12, K206.12, U202.17 (RB8)
unnamed: K205.13, K206.13, U202.16 (RB7)
unnamed: K205.14, K206.14, U202.15 (RB6)
unnamed: LED201.2 (A), R203.2
PGC/URX/RB1: K202.5, K203.5, K204.2 (PGC), U202.5 (RB1/PGC1); also elsewhere on the board
PGD/UTX/RB0: K202.4, K203.4, K204.3 (PGD), U202.4 (RB0/PGD1); also elsewhere on the board
POWER-+3V3: C203.1, C204.1, C205.1, JP204.1, K202.13, K203.13, K204.5 (VCC), K205.1, K206.1, R201.1, R203.1, R204.1, R205.1, U201.2 (VOUT), U202.13 (VDD), U202.28 (VDD); also elsewhere on the board
POWER-+5V: C201.1, D201.1 (C), D202.1 (C), U201.3 (VIN); also elsewhere on the board
POWER-GND: C201.2, C202.2, C203.2, C204.2, C205.2, C206.2, JP201.2, JP204.3, K201.5 (GND), K201.SH (SHIELD), K202.8, K203.8, K204.4 (GND), K205.2, K206.2, LED201.1 (C), S201.3, S201.4, TP201.1, TP202.1, TP203.1, U201.1 (GND), U202.8 (VSS), U202.27 (VSS); also elsewhere on the board
~MCLR: K202.1, K203.1, K204.6 (~MCLR), R202.1, U202.1 (~MCLR)

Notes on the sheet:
RB8/SCL
RB2
Notes: - *Power & UART OR Header Power IN - *U202: Check the pinout for the desired MCU family
CLKI/RA2
RA1
RB11
VCAP/VDDCORE
RB13
RB6
VREG
PGC/URX/RB1
RA0
PGD/UTX/RB0
GND
RB12
RB15
+3V3
RB9/SDA
~{MCLR}
RB4
RB3
CLKO/RA3
RB10
RB14
RB7
RB5
RA4
5VDC MAX

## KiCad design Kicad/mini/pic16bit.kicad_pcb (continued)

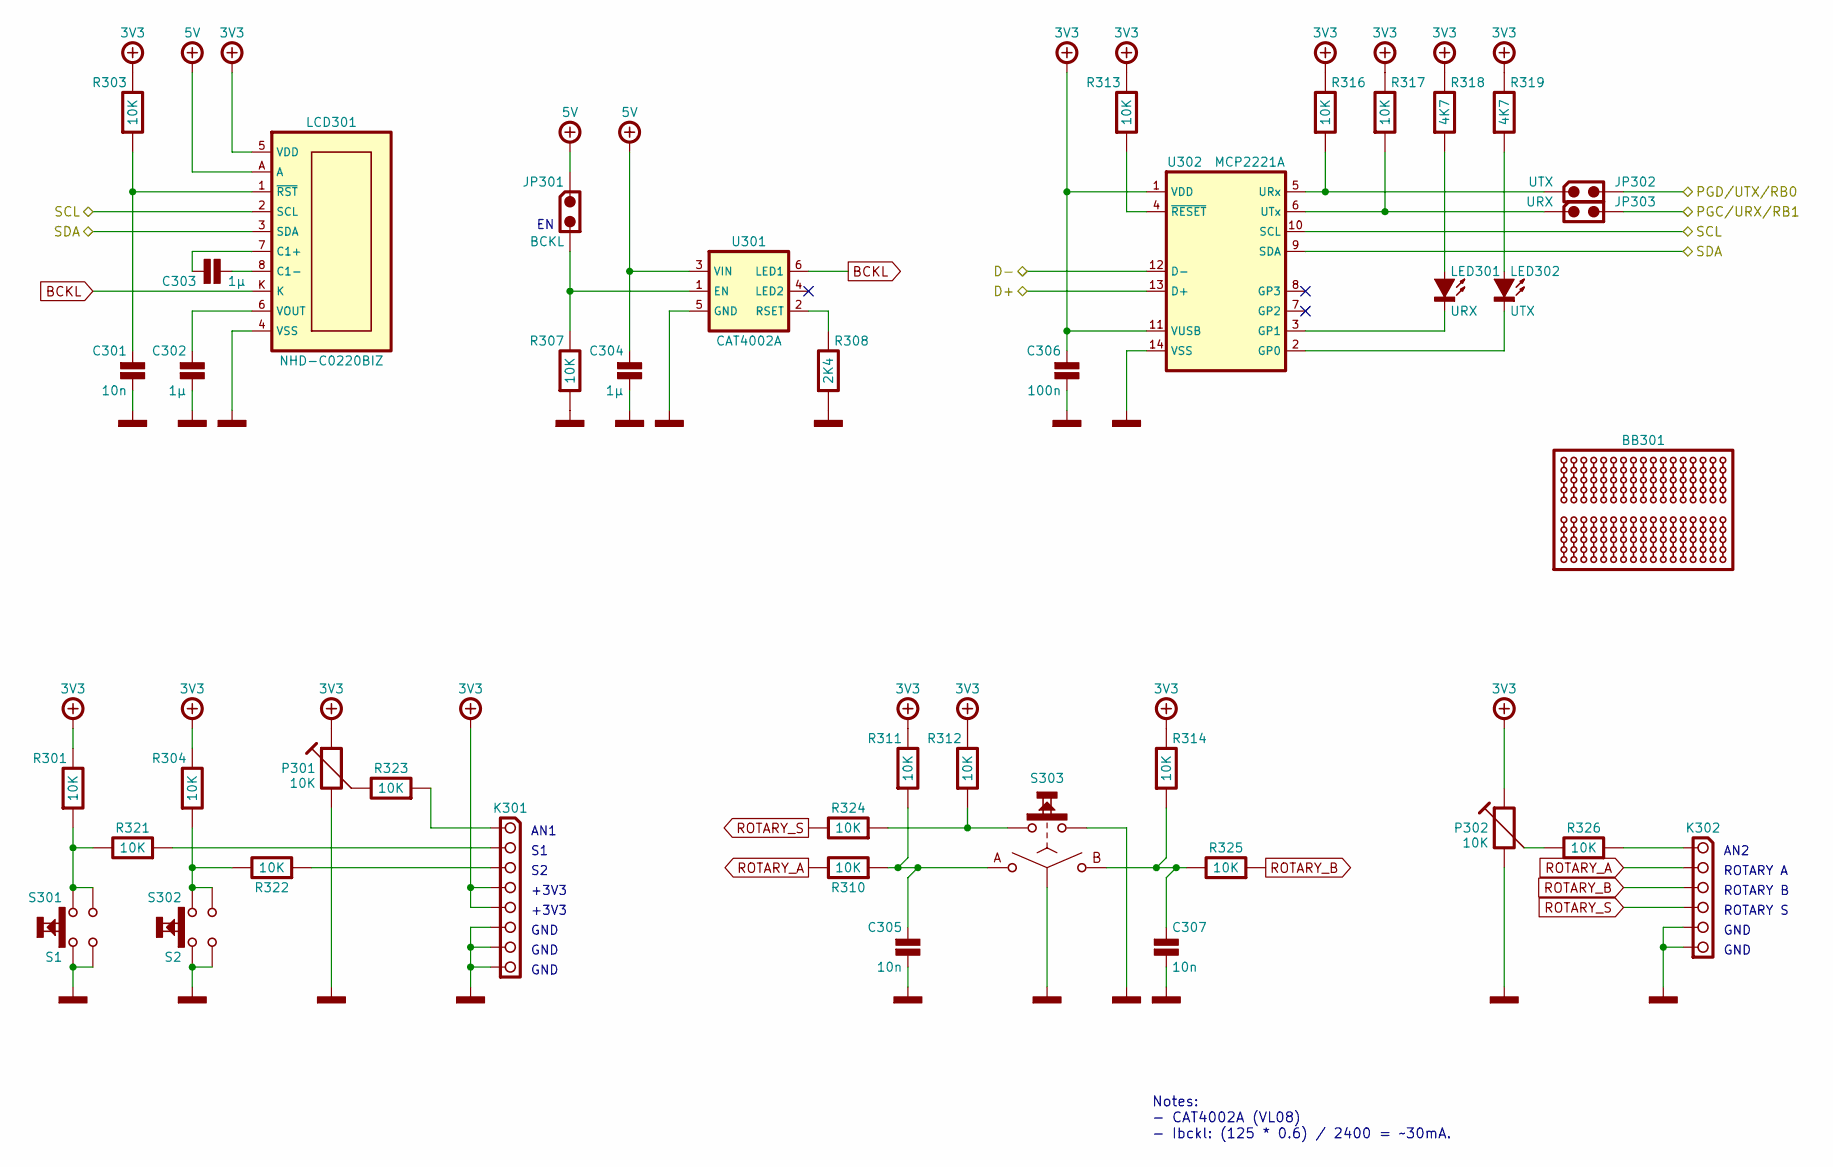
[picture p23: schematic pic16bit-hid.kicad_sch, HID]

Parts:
BB301: BREADBOARD-170; Mouser 854-BB170
C301, C305, C307: 10n; CAPACITOR-SMD-1206; Voltage 100V; Tolerance 5%; Mouser 80-C1206C103J1R
C302, C303, C304: 1µ; CAPACITOR-SMD-1206; Voltage 16V; Tolerance 10%; Mouser 80-C1206C105K4R
C306: 100n; CAPACITOR-SMD-1206; Voltage 50V; Tolerance 5%; Mouser 80-C1206C104J5R
JP301: BCKL; HARWIN-M20-999024x; Mouser 855-M20-999024
JP302: UTX; HARWIN-M20-999024x; Mouser 855-M20-999024
JP303: URX; HARWIN-M20-999024x; Mouser 855-M20-999024
K301: HARWIN-254-F-1X08-VERTICAL; HARWIN-M20-782084x; Mouser 855-M20-782084
K302: HARWIN-254-F-1X06-VERTICAL; HARWIN-M20-782064x; Mouser 855-M20-782064
LCD301: NHD-C0220BIZ; Mouser 763-C0220BIZ-FSW-FBW
LED301: URX; LED-SMD-1206; Mouser 604-APT3216LVBCD
LED302: UTX; LED-SMD-1206; Mouser 604-APT3216LVBCD
P301, P302: 10K; PIHER-PT10MV; Tolerance 20%; Mouser 531-PT10MV-10K
R301, R303, R304, R307, R310, R311, R312, R313, R314, R316, R317, R321, R322, R323, R324, R325, R326: 10K; RESISTOR-SMD-1206; Tolerance 5%; Mouser 660-RK73B2BTTDD103J
R308: 2K4; RESISTOR-SMD-1206; Tolerance 5%; Mouser 660-RK73B2BTTDD242J
R318, R319: 4K7; RESISTOR-SMD-1206; Tolerance 5%; Mouser 660-RK73B2BTTDD472J
S301: S1; CK-KSA-TH; Mouser 611-KSA0M911LFT
S302: S2; CK-KSA-TH; Mouser 611-KSA0M911LFT
S303: BOURNS-PEC12R-24DENTS-SWITCH; BOURNS-PEC12R-SWITCH; Mouser 652-PEC12R-4215F-S24
U301: CAT4002A; SC-70-6; Mouser 863-CAT4002ASD-GT3
U302: MCP2221A; SOIC-14; Mouser 579-MCP2221A-I/SL

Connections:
/HID/D+: U302.13 (D+); also elsewhere on the board
/HID/D-: U302.12 (D-); also elsewhere on the board
/HID/SCL: LCD301.2 (SCL), U302.10 (SCL); also elsewhere on the board
/HID/SDA: LCD301.3 (SDA), U302.9 (SDA); also elsewhere on the board
BCKL: LCD301.K, U301.6 (LED1)
unnamed: K301.1, R323.2
unnamed: K301.2, R321.2
unnamed: K301.3, R322.2
unnamed: K302.1, R326.2
unnamed: C303.1, LCD301.7 (C1+)
unnamed: C303.2, LCD301.8 (C1-)
unnamed: C302.1, LCD301.6 (VOUT)
unnamed: C301.1, LCD301.1 (~RST), R303.2
unnamed: LED301.2 (A), R318.2
unnamed: LED301.1 (C), U302.3 (GP1)
unnamed: LED302.2 (A), R319.2
unnamed: LED302.1 (C), U302.2 (GP0)
unnamed: P301.2, R323.1
unnamed: P302.2, R326.1
unnamed: R301.2, R321.1, S301.3, S301.4
unnamed: R304.2, R322.1, S302.3, S302.4
unnamed: R312.2, R324.2, S303.5
unnamed: C305.1, R310.2, R311.2, S303.1 (A)
unnamed: C307.1, R314.2, R325.1, S303.3 (B)
unnamed: JP301.2, R307.1, U301.1 (EN)
unnamed: R308.1, U301.2 (RSET)
unnamed: JP302.1, R316.2, U302.5 (URx)
unnamed: JP303.1, R317.2, U302.6 (UTx)
unnamed: R313.2, U302.4 (~RESET)
PGC/URX/RB1: JP303.2; also elsewhere on the board
PGD/UTX/RB0: JP302.2; also elsewhere on the board
POWER-+3V3: C306.1, K301.4, K301.5, LCD301.5 (VDD), P301.3, P302.3, R301.1, R303.1, R304.1, R311.1, R312.1, R313.1, R314.1, R316.1, R317.1, R318.1, R319.1, U302.1 (VDD), U302.11 (VUSB); also elsewhere on the board
POWER-+5V: C304.1, JP301.1, LCD301.A, U301.3 (VIN); also elsewhere on the board
POWER-GND: C301.2, C302.2, C304.2, C305.2, C306.2, C307.2, K301.6, K301.7, K301.8, K302.5, K302.6, LCD301.4 (VSS), P301.1, P302.1, R307.2, R308.2, S301.1, S301.2, S302.1, S302.2, S303.2 (C), S303.4, U301.5 (GND), U302.14 (VSS); also elsewhere on the board
ROTARY_A: K302.2, R310.1
ROTARY_B: K302.3, R325.2
ROTARY_S: K302.4, R324.1

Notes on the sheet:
AN1
GND
Notes: - CAT4002A (VL08) - Ibckl: (125 * 0.6) / 2400 = ~30mA.
ROTARY A
ROTARY B
AN2
+3V3
ROTARY S

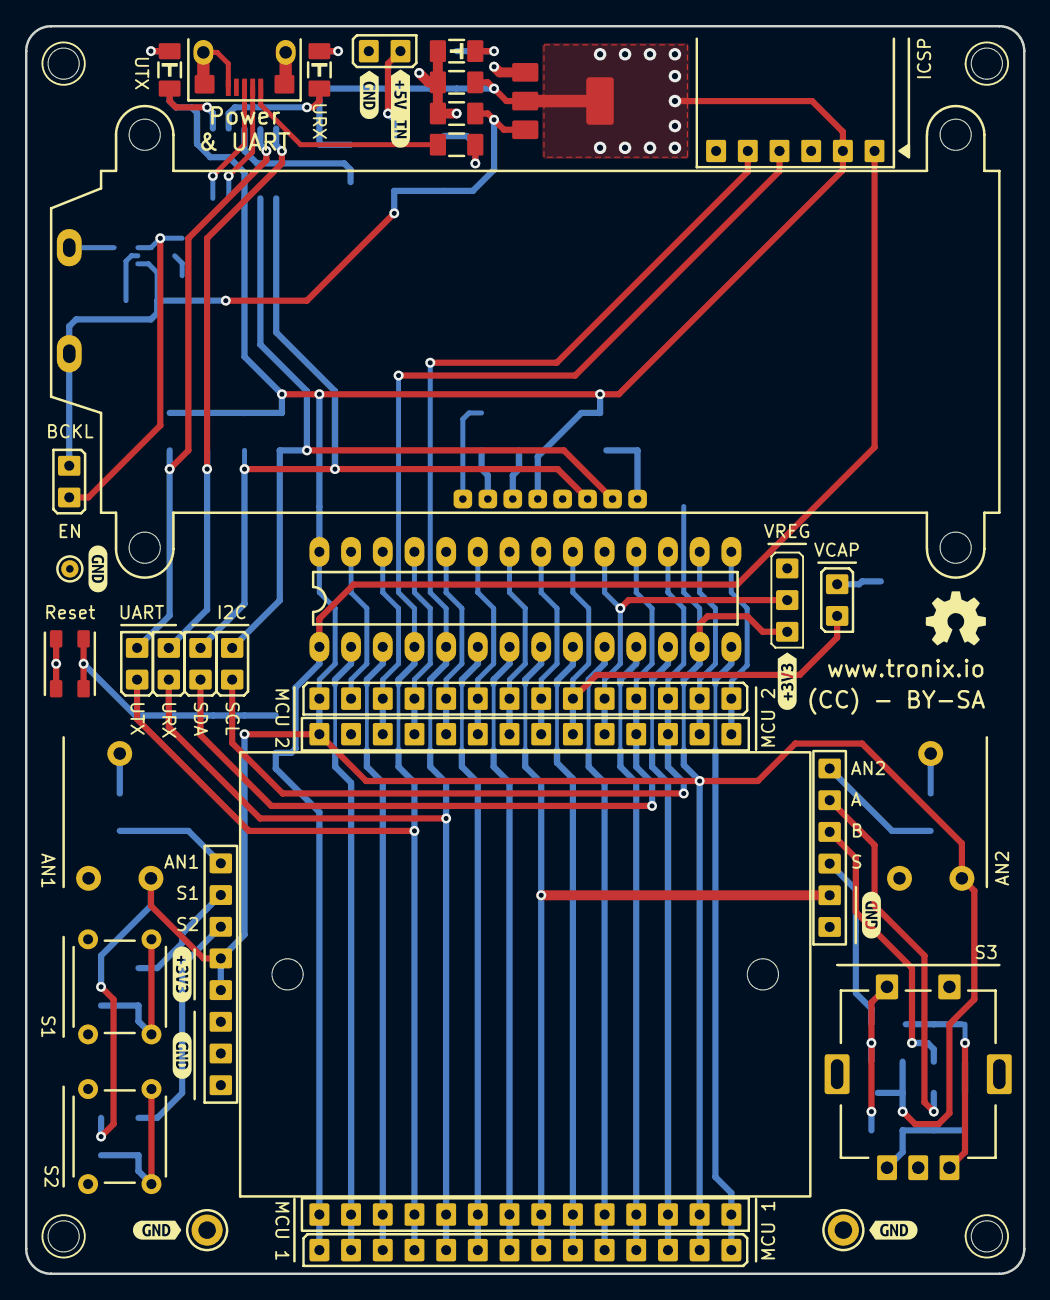
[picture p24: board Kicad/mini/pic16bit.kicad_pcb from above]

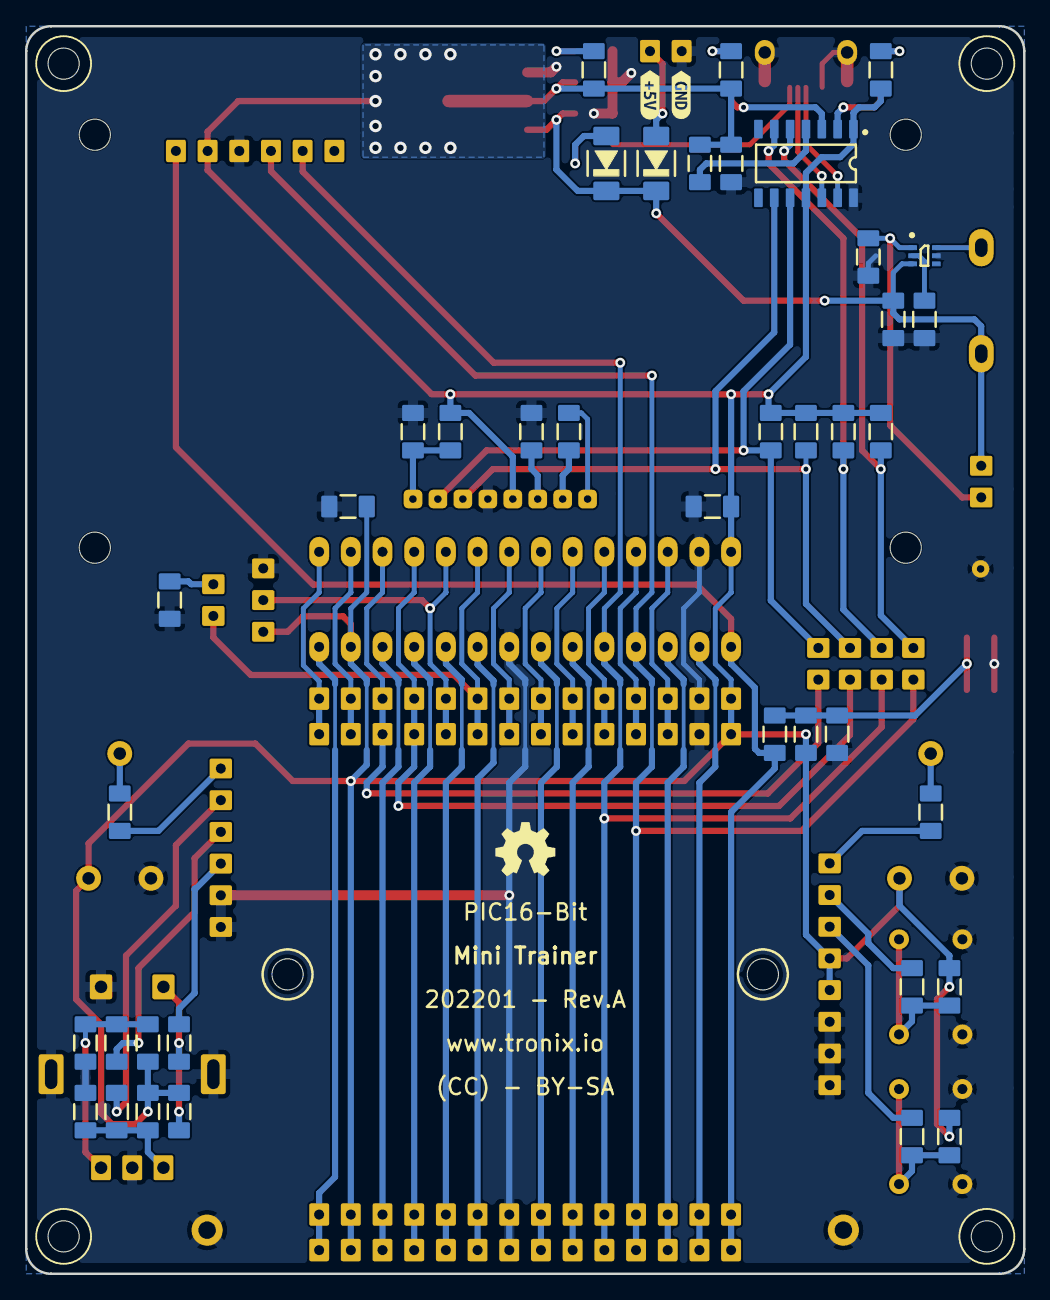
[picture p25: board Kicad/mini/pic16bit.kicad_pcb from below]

Board: 2 copper layers, 80.0 x 100.0 mm, 98 parts (42 on the bottom side), 65 nets.

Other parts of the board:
kibuzzard-65F5FF8A: G***; kibuzzard-65F5FF8A
kibuzzard-65F5FF96: G***; kibuzzard-65F5FF96
kibuzzard-65F5FFA5: G***; kibuzzard-65F5FFA5
kibuzzard-65F5FFB1: G***; kibuzzard-65F5FFB1
kibuzzard-65F5FFC7: G***; kibuzzard-65F5FFC7
kibuzzard-65F5FFD5: G***; kibuzzard-65F5FFD5
kibuzzard-65F5FFE7: G***; kibuzzard-65F5FFE7
kibuzzard-65F5FFF2: G***; kibuzzard-65F5FFF2
kibuzzard-65F6000E: G***; kibuzzard-65F6000E
kibuzzard-65F60000: G***; kibuzzard-65F60000
kibuzzard-65F60022: G***; kibuzzard-65F60022

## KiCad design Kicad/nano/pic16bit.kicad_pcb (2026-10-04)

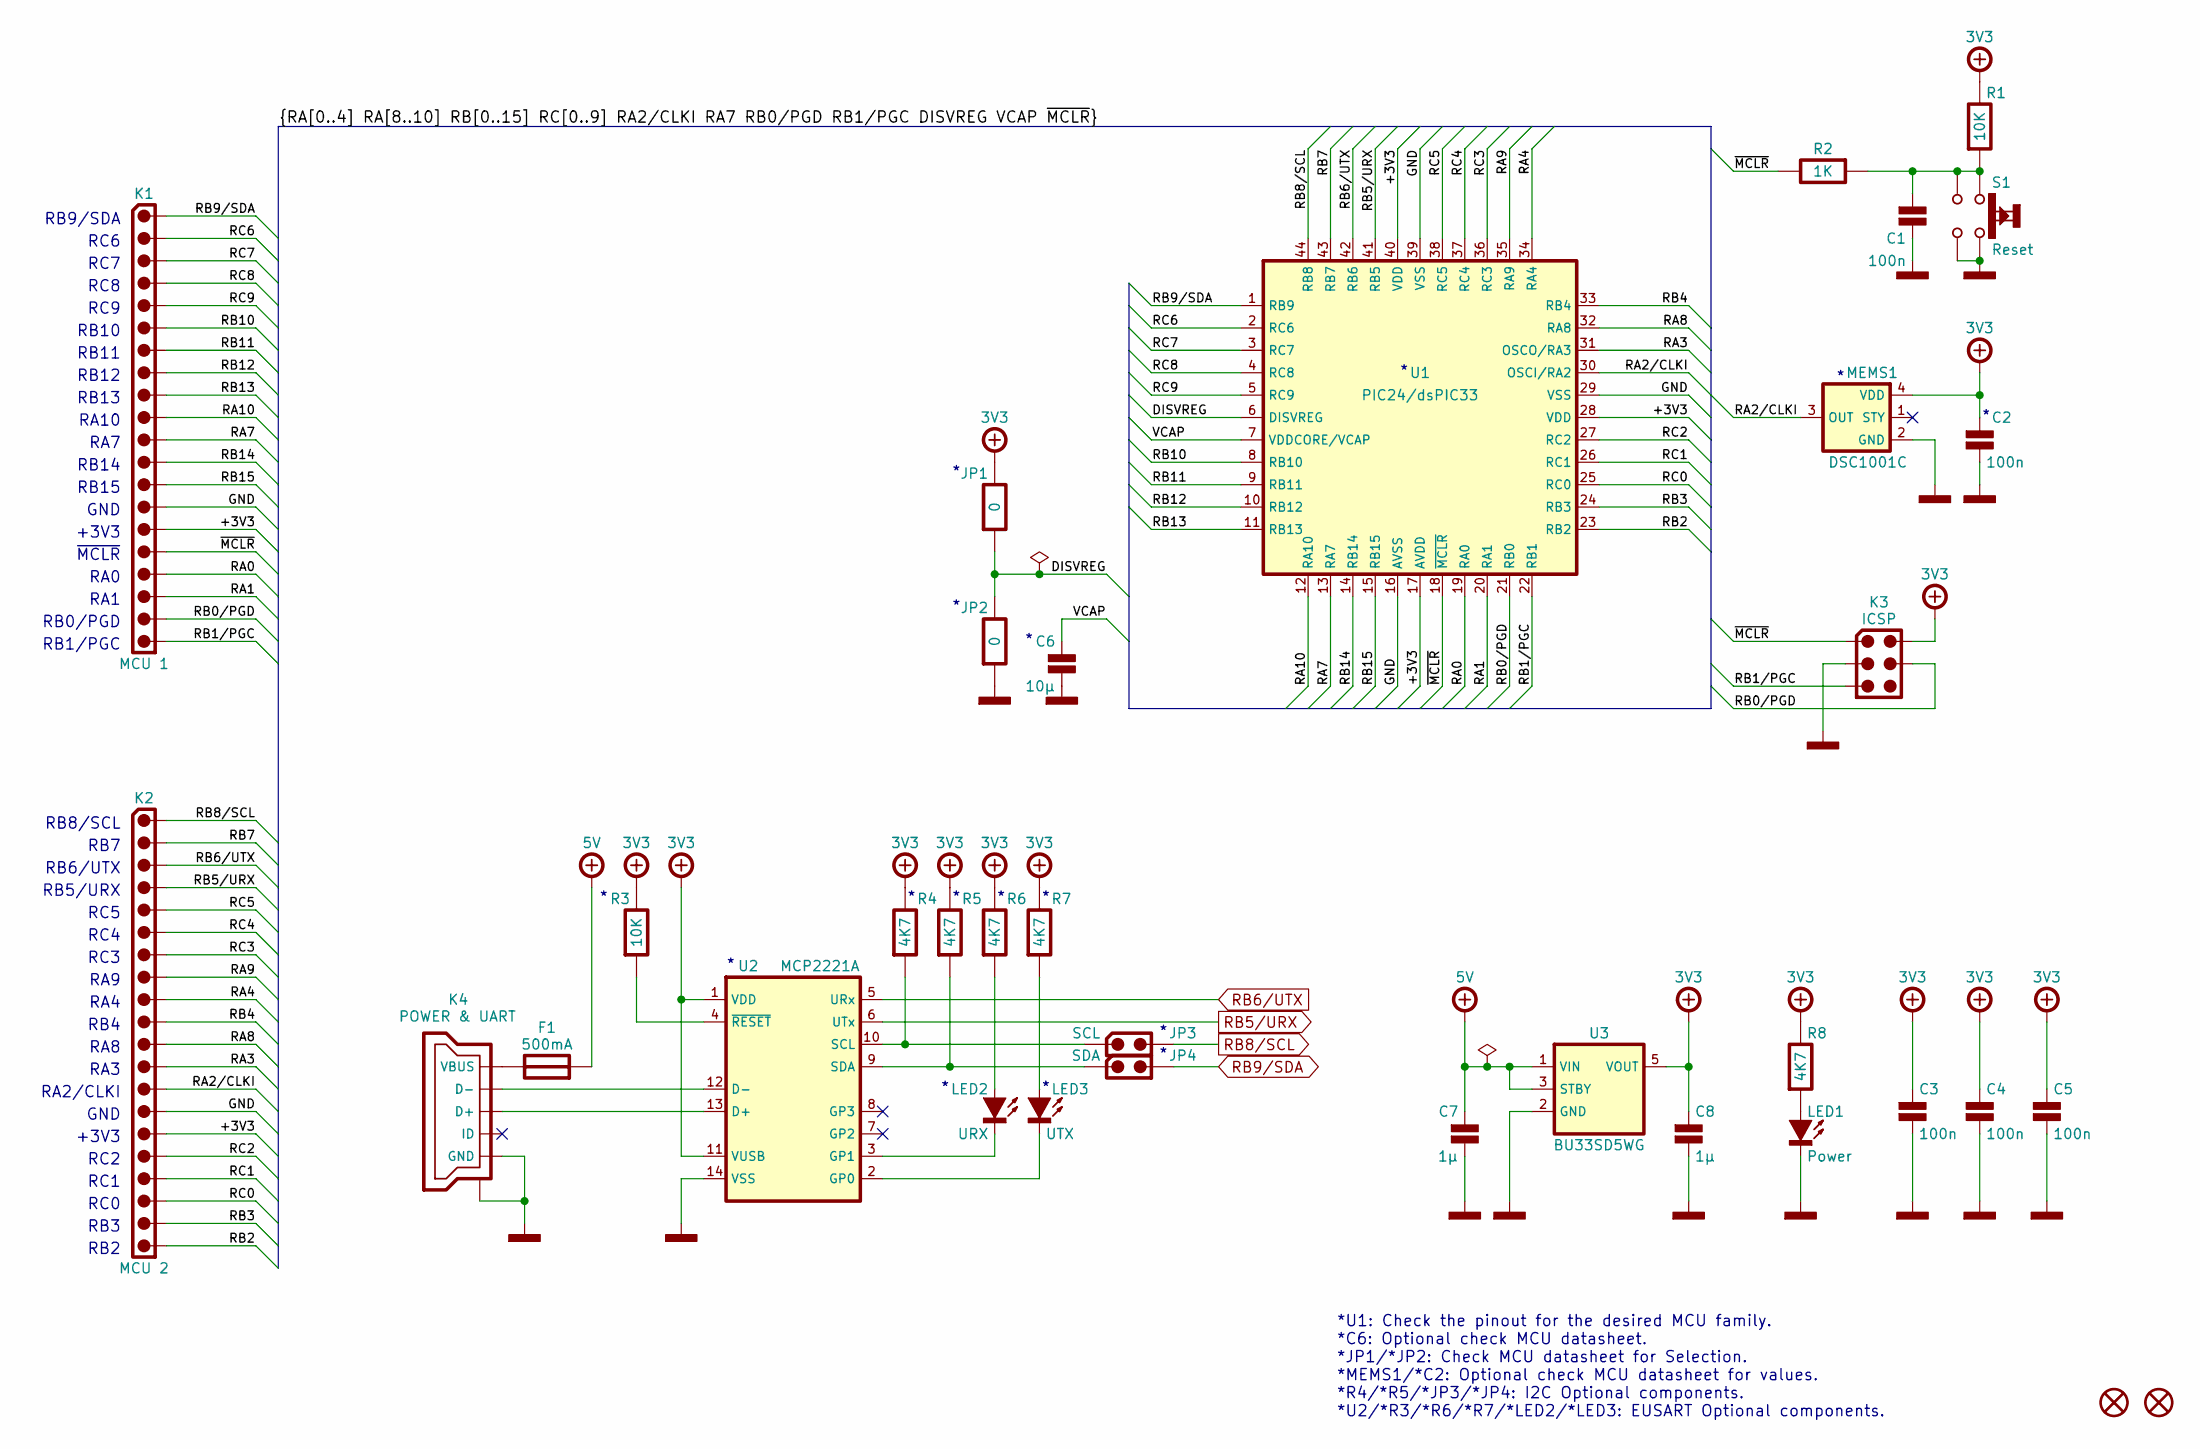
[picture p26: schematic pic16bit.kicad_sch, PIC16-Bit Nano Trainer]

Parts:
C1, C2, C3, C4, C5: 100n; CAPACITOR-SMD-0805; Voltage 50V; Tolerance 5%; Mouser 80-C0805C104J5
C6: 10µ; CAPACITOR-SMD-0805; Voltage 25V; Tolerance 10%; Mouser 81-GRM21BZ71E106
C7, C8: 1µ; CAPACITOR-SMD-0805; Voltage 50V; Tolerance 10%; Mouser 187-CL21B105KBFNNNE
F1: 500mA; FUSE-SMD-0805; Mouser 652-MF-PSMF050X-2
H1, H2: HARWIN-JUMPER-0200-03MM-BLACK; HARWIN-M22-190-19X; Mouser 855-M22-19000
JP1, JP2: 0; RESISTOR-SMD-0805; Mouser 660-RK73Z2ATTD
JP3: SCL; HARWIN-M22-25102xx; Mouser 855-M22-25102
JP4: SDA; HARWIN-M22-25102xx; Mouser 855-M22-25102
K1: MCU 1; SAMTEC-TSW-120-22-T-S; Mouser 200-TSW12022TS
K2: MCU 2; SAMTEC-TSW-120-22-T-S; Mouser 200-TSW12022TS
K3: ICSP; HARWIN-M20-998034x; Mouser 855-M20-998034
K4: POWER & UART; USB-TYPE-B-MICRO-TH; Mouser 649-10118193-0001LF
LED1: Power; LED-SMD-0805; Mouser 604-APT2012LVBCD
LED2: URX; LED-SMD-0805; Mouser 604-APT2012LVBCD
LED3: UTX; LED-SMD-0805; Mouser 604-APT2012LVBCD
MEMS1: DSC1001C; CDFN-3225; Mouser 998-1001CI2-024.5760
R1, R3: 10K; RESISTOR-SMD-0805; Tolerance 5%; Mouser 660-RK73B2ATTDD103J
R2: 1K; RESISTOR-SMD-0805; Tolerance 5%; Mouser 660-RK73B2ATTDD102J
R4, R5, R6, R7, R8: 4K7; RESISTOR-SMD-0805; Tolerance 5%; Mouser 660-RK73B2ATTDD472J
S1: Reset; ALPS-SKRPAC; Mouser 688-SKRPACE010
U1: PIC24/dsPIC33; TQFP-44; Mouser 579-FJ64GA104-I/PT
U2: MCP2221A; TSSOP-14; Mouser 579-MCP2221A-I/ST
U3: BU33SD5WG; SOT-23-5; Mouser 755-BU33SD5WG-TR

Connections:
+3V3: C2.1, C3.1, C4.1, C5.1, C8.1, JP1.1, K1.15, K2.15, K3.2 (VCC), MEMS1.4 (VDD), R1.1, R3.1, R4.1, R5.1, R6.1, R7.1, R8.1, U1.17 (AVDD), U1.28 (VDD), U1.40 (VDD), U2.1 (VDD), U2.11 (VUSB), U3.5 (VOUT)
/DISVREG: JP1.2, JP2.1, U1.6 (DISVREG)
/RA0: K1.17, U1.19 (RA0)
/RA1: K1.18, U1.20 (RA1)
/RA2/CLKI: K2.13, MEMS1.3 (OUT), U1.30 (OSCI/RA2)
/RA3: K2.12, U1.31 (OSCO/RA3)
/RA4: K2.9, U1.34 (RA4)
/RA7: K1.11, U1.13 (RA7)
/RA8: K2.11, U1.32 (RA8)
/RA9: K2.8, U1.35 (RA9)
/RA10: K1.10, U1.12 (RA10)
/RB0/PGD: K1.19, K3.4 (ICSPDAT), U1.21 (RB0)
/RB1/PGC: K1.20, K3.5 (ICSPCLK), U1.22 (RB1)
/RB2: K2.20, U1.23 (RB2)
/RB3: K2.19, U1.24 (RB3)
/RB4: K2.10, U1.33 (RB4)
/RB7: K2.2, U1.43 (RB7)
/RB10: K1.6, U1.8 (RB10)
/RB11: K1.7, U1.9 (RB11)
/RB12: K1.8, U1.10 (RB12)
/RB13: K1.9, U1.11 (RB13)
/RB14: K1.12, U1.14 (RB14)
/RB15: K1.13, U1.15 (RB15)
/RC0: K2.18, U1.25 (RC0)
/RC1: K2.17, U1.26 (RC1)
/RC2: K2.16, U1.27 (RC2)
/RC3: K2.7, U1.36 (RC3)
/RC4: K2.6, U1.37 (RC4)
/RC5: K2.5, U1.38 (RC5)
/RC6: K1.2, U1.2 (RC6)
/RC7: K1.3, U1.3 (RC7)
/RC8: K1.4, U1.4 (RC8)
/RC9: K1.5, U1.5 (RC9)
/VCAP: C6.1, U1.7 (VDDCORE/VCAP)
/~MCLR: K1.16, K3.1 (~MCLR), R2.1, U1.18 (~MCLR)
GND: C1.2, C2.2, C3.2, C4.2, C5.2, C6.2, C7.2, C8.2, JP2.2, K1.14, K2.14, K3.3 (GND), K4.5 (GND), K4.SH (SHIELD), LED1.1 (C), MEMS1.2 (GND), S1.3, S1.4, U1.16 (AVSS), U1.29 (VSS), U1.39 (VSS), U2.14 (VSS), U3.2 (GND)
unnamed: C1.1, R1.2, R2.2, S1.1, S1.2
unnamed: K4.3 (D+), U2.13 (D+)
unnamed: K4.2 (D-), U2.12 (D-)
unnamed: F1.1, K4.1 (VBUS)
unnamed: LED1.2 (A), R8.2
unnamed: LED2.2 (A), R6.2
unnamed: LED2.1 (C), U2.3 (GP1)
unnamed: LED3.2 (A), R7.2
unnamed: LED3.1 (C), U2.2 (GP0)
unnamed: JP3.1, R4.2, U2.10 (SCL)
unnamed: JP4.1, R5.2, U2.9 (SDA)
unnamed: R3.2, U2.4 (~RESET)
POWER-+5V: C7.1, F1.2, U3.1 (VIN), U3.3 (STBY)
RB5/URX: K2.4, U1.41 (RB5), U2.6 (UTx)
RB6/UTX: K2.3, U1.42 (RB6), U2.5 (URx)
RB8/SCL: JP3.2, K2.1, U1.44 (RB8)
RB9/SDA: JP4.2, K1.1, U1.1 (RB9)

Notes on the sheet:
RC9
RA2/CLKI
RB12
RC7
RB8/SCL
GND
RB14
RB2
RB13
RC0
RA9
~{MCLR}
RA10
RB11
RC1
RB15
RA3
RC4
RB5/URX
RC8
RB10
RA7
RB1/PGC
*U1: Check the pinout for the desired MCU family. *C6: Optional check MCU datasheet. *JP1/*JP2: Check MCU datasheet for Selection. *MEMS1/*C2: Optional check MCU datasheet for values. *R4/*R5/*JP3/*JP4: I2C Optional components. *U2/*R3/*R6/*R7/*LED2/*LED3: EUSART Optional components.
RC2
RA1
+3V3
RB0/PGD
RB7
RA8
RB6/UTX
RA0
RB3
RC5
RC3
RA4
RB9/SDA
RB4
RC6



Board: 2 copper layers, 21.0 x 52.0 mm, 45 parts (28 on the bottom side), 53 nets.

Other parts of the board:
GB: LOGO; OSHW-3MM
GT: LOGO; OSHW-3MM
kibuzzard-65F5C12D: G***; kibuzzard-65F5C12D
kibuzzard-65F5C13A: G***; kibuzzard-65F5C13A
kibuzzard-65F5C14D: G***; kibuzzard-65F5C14D
kibuzzard-65F5C15C: G***; kibuzzard-65F5C15C
kibuzzard-65F5C114: G***; kibuzzard-65F5C114
kibuzzard-65F5C121: G***; kibuzzard-65F5C121
kibuzzard-65F5C168: G***; kibuzzard-65F5C168
kibuzzard-65F5C174: G***; kibuzzard-65F5C174

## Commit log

2022-01-10 Add Kicad
    [pic16bit.kicad_pcb, pic16bit.kicad_sch]
2022-03-21 Create Mini
    [pic16bit-hid.kicad_sch, pic16bit-mcu.kicad_sch, pic16bit.kicad_pcb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]
2022-04-01 Update Nano
    [pic16bit.kicad_pcb, pic16bit.kicad_sch]
2022-04-01 Update Mini
    [pic16bit-hid.kicad_sch, pic16bit-mcu.kicad_sch, pic16bit.kicad_pcb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]
2022-04-18 Update Kicad
    [pic16bit-hid.kicad_sch, pic16bit-mcu.kicad_sch, pic16bit.kicad_pcb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]
2022-09-03 PIC16Bit Trainer
    [pic16bit-hid.kicad_sch, pic16bit-mcu.kicad_sch, pic16bit-mod.kicad_sch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]
2023-01-21 Update Trainer
    [pic16bit-hid.kicad_sch, pic16bit-mcu.kicad_sch, pic16bit-mod.kicad_sch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]
2024-03-16 Update Nano Kicad 8
    [pic16bit.kicad_pcb]
2024-03-16 Update Mini Kicad 8
    [pic16bit-hid.kicad_sch, pic16bit-mcu.kicad_sch, pic16bit.kicad_pcb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]
2024-03-17 Update Trainer Kicad 8
    [pic16bit-hid.kicad_sch, pic16bit-mcu.kicad_sch, pic16bit-mod.kicad_sch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]
